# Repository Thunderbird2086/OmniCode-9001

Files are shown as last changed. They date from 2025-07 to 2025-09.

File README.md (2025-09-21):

# OmniCode:9001
A modular keyboard made up of three detachable untis.
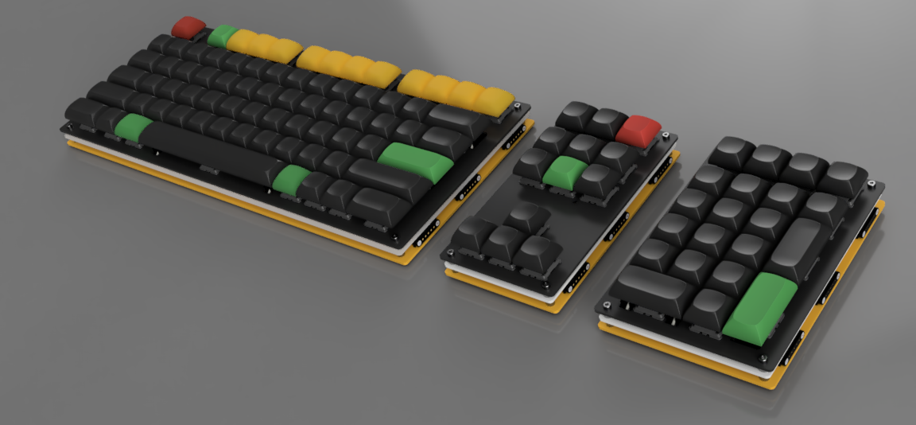
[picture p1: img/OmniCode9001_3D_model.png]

*POGO pins are rendered with 5 pins only*

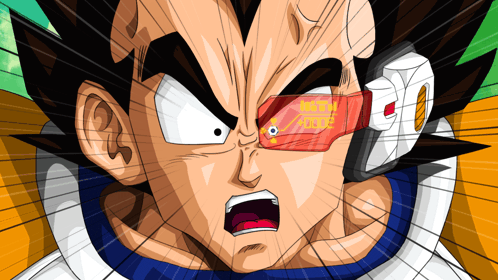
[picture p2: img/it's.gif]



## Overview
OmniCode:9001 is the modular keyboards born in Hong Kong, engineered for control beyond limits. This highly customizable, open-source keyboard is designed for ergonomic comfort, maximum flexibility, and creative power. With magnetic connectors, hot-swappable blocks like GlyphMatrix, PhaseShift, and DeltaForm, OmniCode:9001 adapts to every workflow.  It is built with the RP2040 microcontroller for next-generation performance.  Ideal for makers and keyboard enthusiasts who demand the best.

## Sub Modules
- **Alpha Block:** GlyphMatrix taps into the visual power of language—glyphs as symbols, matrix as command stream. It’s the scriptwriter for your digital world.

- **Nav Block:** PhaseShift suggests rapid movement, shifting through modes or layers like teleportation. It’s your tactical array for traversing digital dimensions.

- **Num Block:** DeltaForm Already perfect. This name suggests modular transformation. Zoom, macros, data entry and it's all reborn in a shapeshifting format.

## Builds
* [BOM](bom/)
* [Build guides](doc/build.md)
* [Cases](cases/)

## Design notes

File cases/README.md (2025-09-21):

# OmniCode:9001 Case Files

This directory contains STEP files for all OmniCode:9001 cases. These files can be used for both 3D printing and CNC manufacturing.

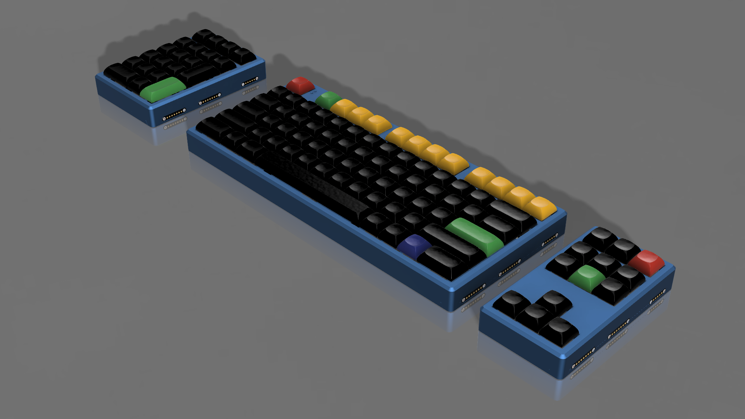
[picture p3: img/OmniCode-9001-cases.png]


## Case Components

### GlyphMatrix
- `GlyphMatrix_Top.step` - Top case
- `GlyphMatrix_PCB.step` - PCB model for reference

### PhaseShift
- `PhaseShift_Top.step` - Top case
- `PhaseShift_Plate.step` - Switch plate

### DeltaForm
- `DeltaForm_Top.step` - Top case
- `DeltaForm_Plate.step` - Switch plate

## Manufacturing Notes

### Screw Specifications
- All cases use M3 helicoils (thread inserts)
- Helicoil size: M3x0.5mm 1D(3mm)
- Required for both 3D printed and CNC manufactured cases

### 3D Printing Recommendations
- Material: Nylon or ABS recommended
- Layer Height: 0.2mm or less for better surface finish
- Infill: 60% minimum, recommanded over 80% 
- Wall Count: 4 minimum
- Support: Required for top cases
- Orientation: Print top cases upside down for best finish
- Note: Tap for helicoil installation after printing

### CNC Manufacturing
- Material: Aluminum 6061 recommended
- Finish: Can be anodized after manufacturing
- Thread spec: Tap for M3 helicoil installation

### Hardware Requirements
- M3 helicoils for all mounting points
- M3 screws for assembly: 8mm in length
- Follow the main build guide for assembly instructions

## Additional Notes
- All models are in 1:1 scale (millimeters)

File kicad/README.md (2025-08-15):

# OmniCode:9001 PCB Designs

This directory contains all KiCad PCB design files for the OmniCode:9001 keyboard modules.

## Modules

### GlyphMatrix (Alpha Block)
The main typing module with a full ANSI layout.

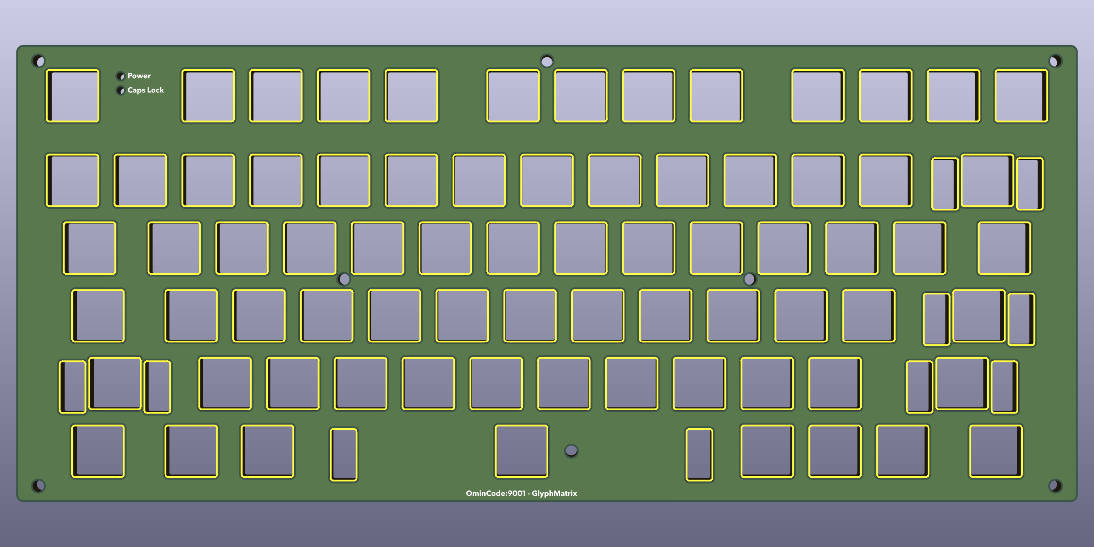
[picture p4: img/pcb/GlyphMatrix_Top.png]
GlyphMatrix PCB Top View

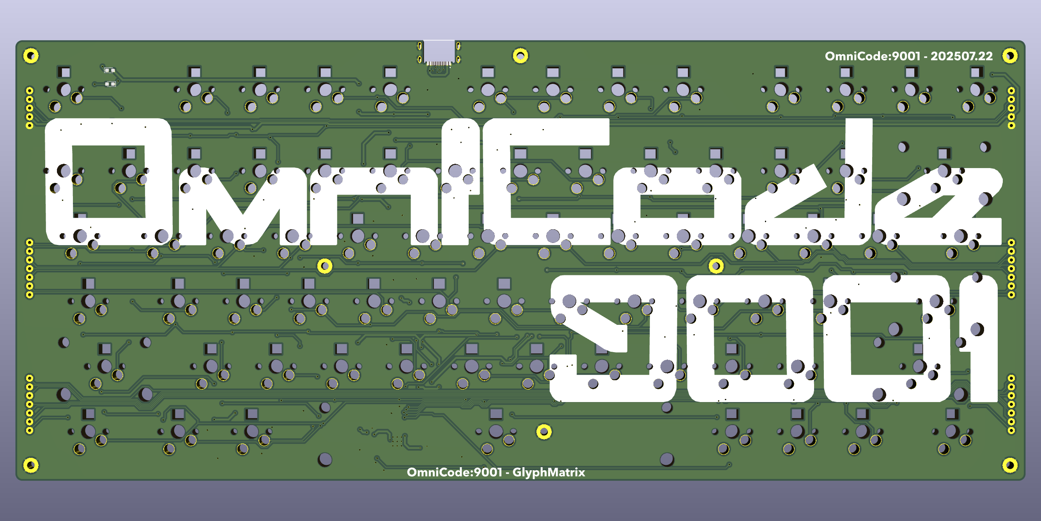
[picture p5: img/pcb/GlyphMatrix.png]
GlyphMatrix PCB

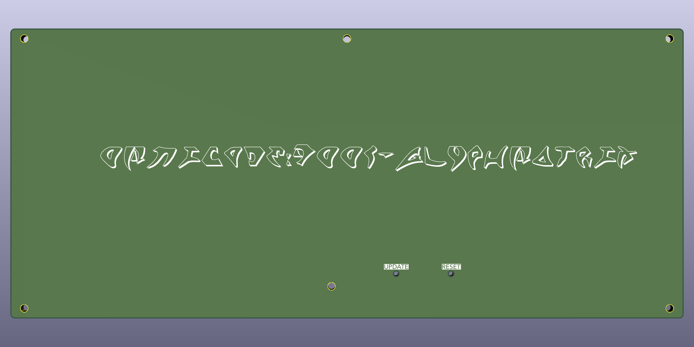
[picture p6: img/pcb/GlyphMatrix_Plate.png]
GlyphMatrix PCB Bottom View


**Features:**
- RP2040 microcontroller
- USB Type-C connector
- Hot-swappable MX switch sockets
- RGB LED support
- POGO pin connections for modular attachment

### PhaseShift (Nav Block)
Navigation and macro control module.

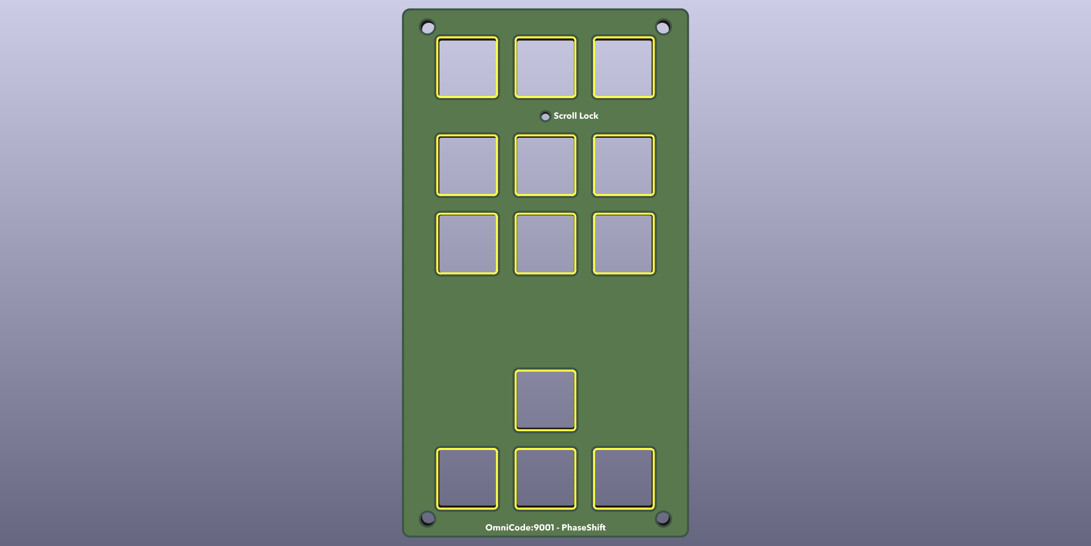
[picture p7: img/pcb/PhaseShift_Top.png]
PhaseShift PCB Top View

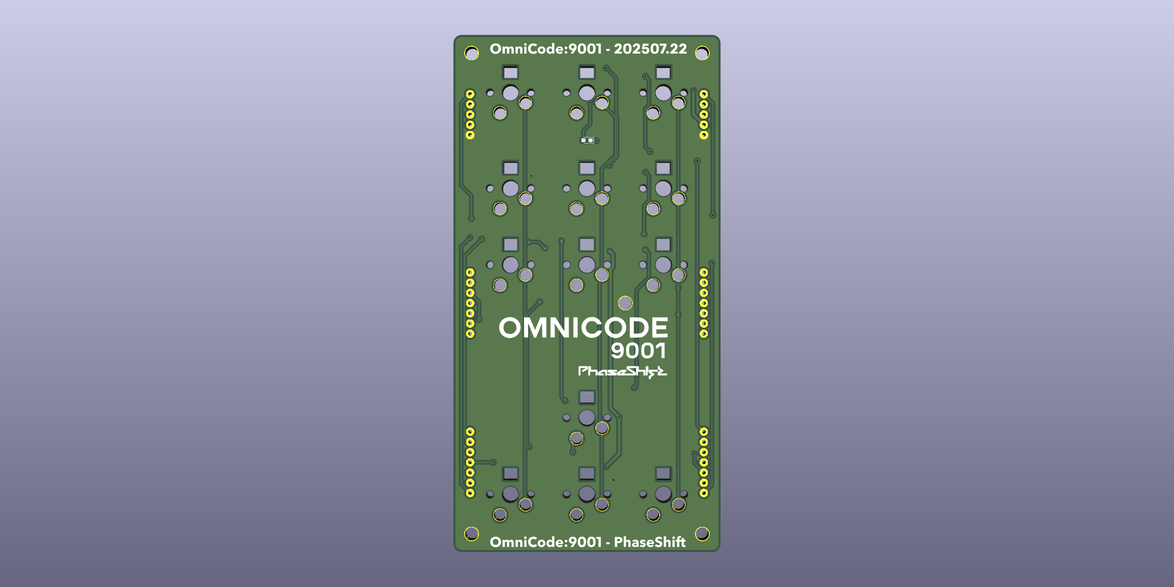
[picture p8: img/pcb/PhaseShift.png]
PhaseShift PCB

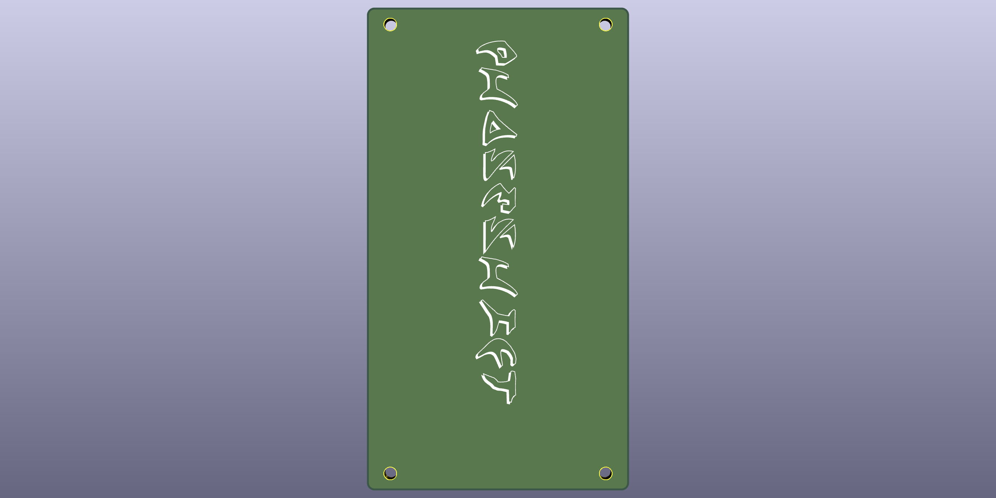
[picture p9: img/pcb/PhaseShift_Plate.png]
PhaseShift PCB Bottom View


**Features:**
- Hot-swappable MX switch sockets
- RGB LED support
- POGO pin connections for modular attachment

### DeltaForm (Num Block)
Numeric keypad and additional macro keys.

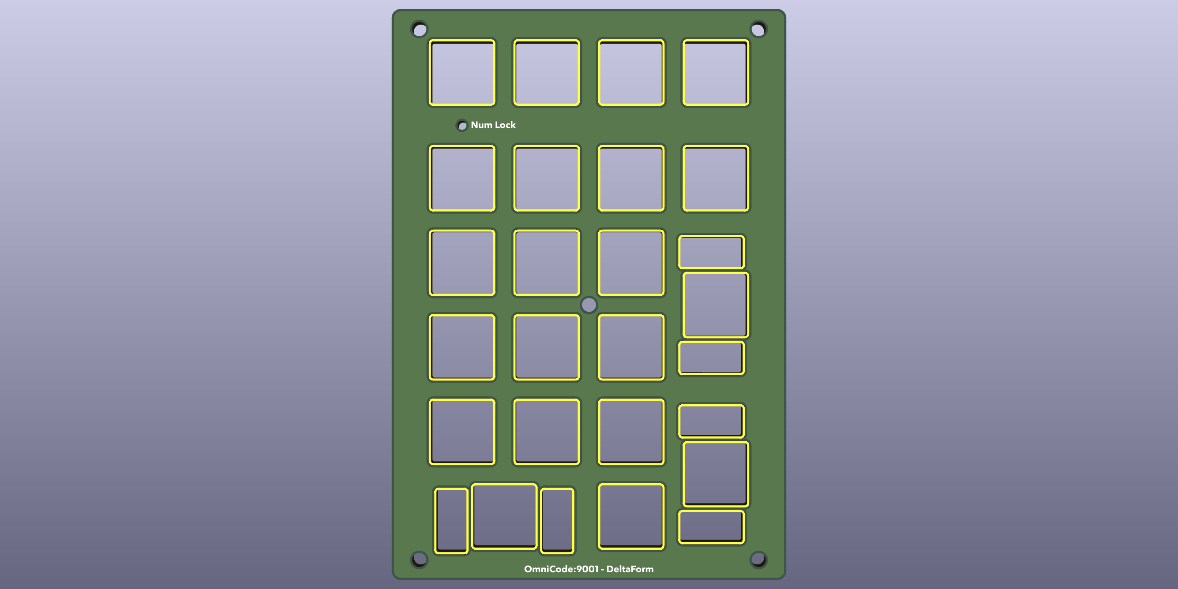
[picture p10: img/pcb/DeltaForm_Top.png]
DeltaForm PCB Top View

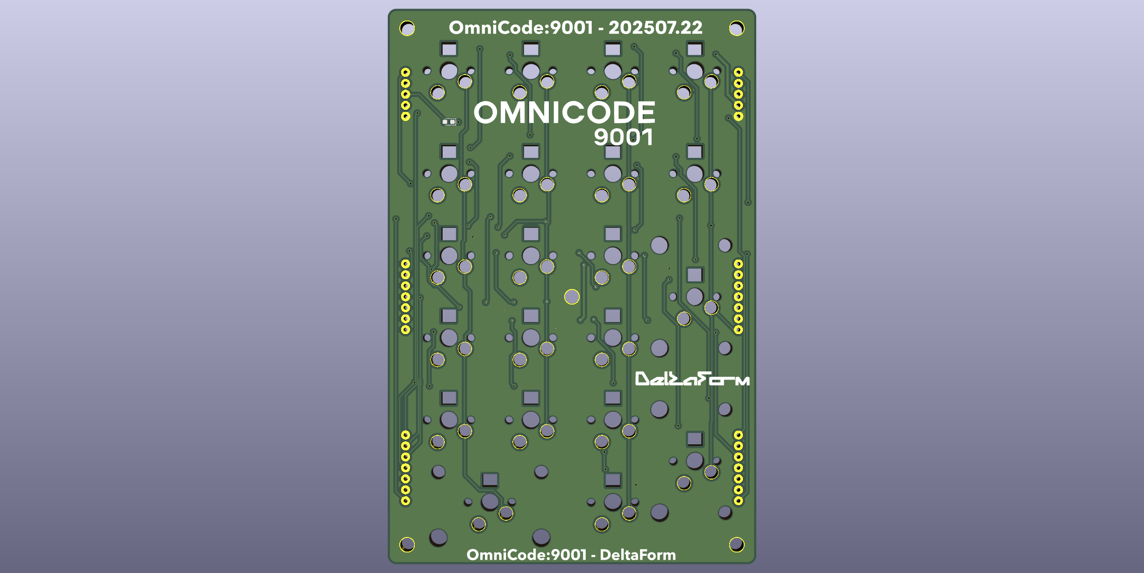
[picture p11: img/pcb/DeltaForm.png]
DeltaForm PCB

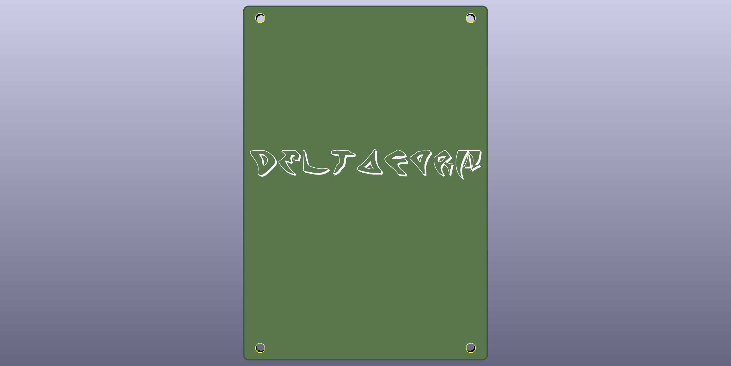
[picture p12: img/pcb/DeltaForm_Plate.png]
DeltaForm PCB Bottom View


**Features:**
- Hot-swappable MX switch sockets
- RGB LED support
- POGO pin connections for modular attachment

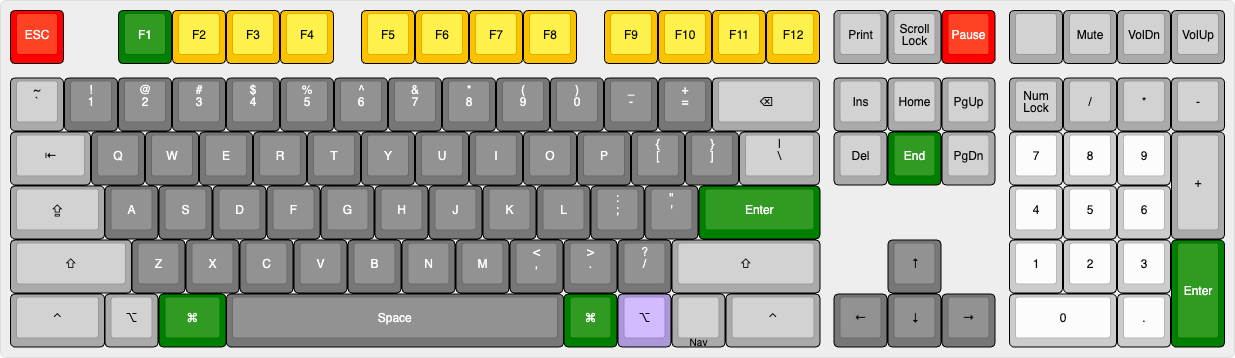
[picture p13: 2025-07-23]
img/layout/omnicode-9001-qwerty.png

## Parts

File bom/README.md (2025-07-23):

# GlyphMatrix (Alpha Block) BOM

GlyphMatrix taps into the visual power of language—glyphs as symbols, matrix as command stream. It’s the scriptwriter for your digital world.

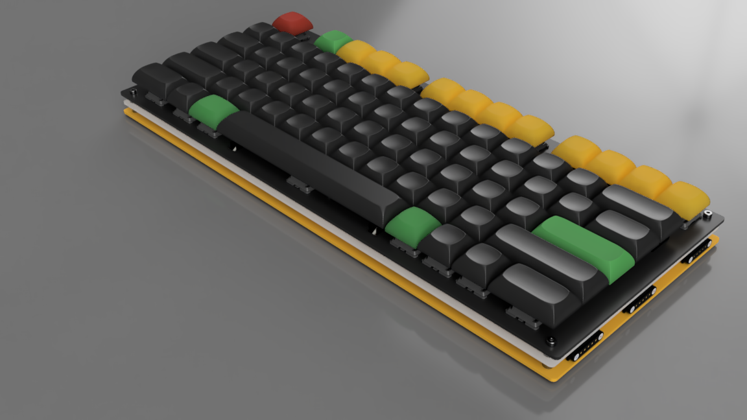
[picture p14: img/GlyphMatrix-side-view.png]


*POGO pins are rendered with 5 pins only*

## Bill of Materials

### RP2040

| Parts | Package | Designator(s) | Quantity |
|---|---|---|---|
| RP2040 | QFN-56 | MCU1 | 1 |
| W25Q128JVS | SOIC-8 | U1 | 1 |
| XC6206PxxxMR | SOT-23 | U3 | 1 |
| 1k | 0402 | R1, R6, R8 | 3 |
| 27R | 0603 | R4, R5 | 2 |
| 100nF | 0402 | C1, C10, C11, C12, C13, C14, C15, C5, C6, C9 | 10 |
| 1uF | 0402 | C16, C17, C4, C8 | 4 |
| 10uF | 0402 | C7 | 1 |
| 22pF | 0402 | C2, C3 | 2 |
| 12MHz | 3225 | Y1 | 1 |
| Push Switch | SKQG | SW1, SW2 | 2 |

### USB

| Parts | Package | Designator(s) | Quantity |
|---|---|---|---|
| USB-C Receptacle | USB4520-03-0-A Rev. A | USB1 | 1 |
| USBLC6-2SC6 | SOT-23-6 | U2 | 1 |
| 5.1k | 0402 | R2, R3 | 2 |
| 500mA | 1206 | F1 | 1 |

### Key Switches

| Parts | Package | Designator(s) | Quantity |
|---|---|---|---|
| 1N4148W | SOD-123 | D1-D74 | 74 |
| Hotswap Socket | MX | S1-S74 | 74 |
| WHITE | 0603 | LED1 | 1 |
| GREEN | 0603 | LED2 | 1 |

### Optional

| Parts | Package | Designator(s) | Quantity |
|---|---|---|---|
| SK6812MINI-E | SK6812MINI-E| L1-L74 | 74 |
| POGO 5 pin-male | Curved | POGO1 | 1 |
| POGO 5 pin-female | Curved | POGO2 | 1 |
| POGO 7 pin-male | Curved | POGO3, POGO5 | 2 |
| POGO 7 pin-female | Curved | POGO4, POGO6 | 2 |

# Other blocks

* [PhaseShift](bom-phaseshift.md)
* [DeltaForm](bom-deltaform.md)

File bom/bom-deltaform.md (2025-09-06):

# DeltaForm (Num Block) BOM

DeltaForm Already perfect. This name suggests modular transformation. Zoom, macros, data entry and it's all reborn in a shapeshifting format.

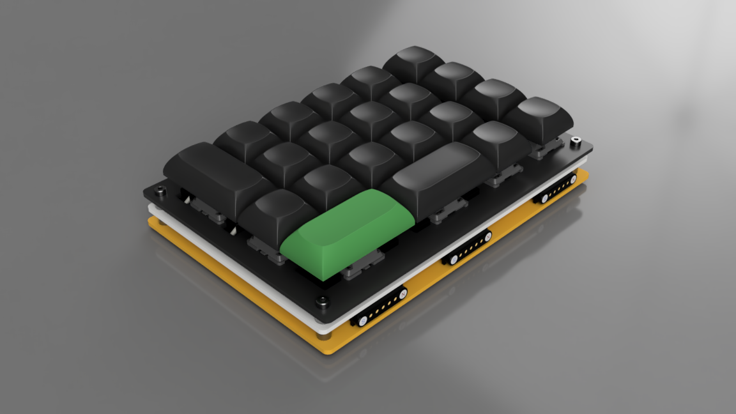
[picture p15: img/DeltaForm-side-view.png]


*POGO pins are rendered with 5 pins only*

## Bill of Materials

| Parts | Packeage | Designator(s) | Quantity |
|---|---|---|---|
| Hotswap Socket | MX | S1-S21 | 21 |
| 1N4148W | SOD-123 | D1-D21 | 21 |
| 330 | 0603 | R1 | 1 |
| GREEN | 0603 | LED1 | 1 |
| POGO 5 pin-male | Curved | POGO1 | 1 |
| POGO 5 pin-female | Curved | POGO2 | 1 |
| POGO 7 pin-male | Curved | POGO3, POGO5 | 2 |
| POGO 7 pin-female | Curved | POGO4, POGO6 | 2 |

### Optional

| Parts | Packeage | Designator(s) | Quantity |
|---|---|---|---|
| SK6812MINI-E | SK6812MINI-E| L1-L21 | 21 |

# Other blocks

* [GlyphMatrix](README.md)
* [PhaseShift](bom-phaseshift.md)

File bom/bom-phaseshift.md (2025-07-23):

# PhaseShift (Nav Block) BOM

PhaseShift suggests rapid movement, shifting through modes or layers like teleportation. It’s your tactical array for traversing digital dimensions.

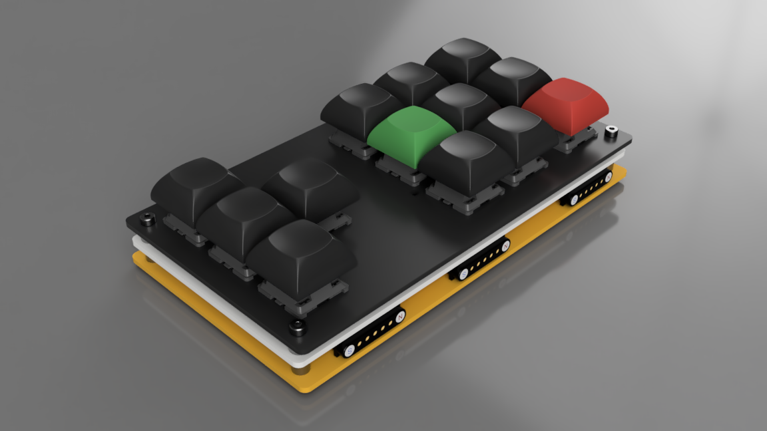
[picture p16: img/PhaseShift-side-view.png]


*POGO pins are rendered with 5 pins only*

## Bill of Materials

| Parts | Packeage | Designator(s) | Quantity |
|---|---|---|---|
| Hotswap Socket | MX | S1-S13 | 13 |
| 1N4148W | SOD-123 | D1-D13 | 13 |
| 330 | 0603 | R1 | 1 |
| GREEN | 0603 | LED1 | 1 |
| POGO 5 pin-male | Curved | POGO1 | 1 |
| POGO 5 pin-female | Curved | POGO2 | 1 |
| POGO 7 pin-male | Curved | POGO3, POGO5 | 2 |
| POGO 7 pin-female | Curved | POGO4, POGO6 | 2 |

### Optional

| Parts | Packeage | Designator(s) | Quantity |
|---|---|---|---|
| SK6812MINI-E | SK6812MINI-E| L1-L13 | 13 |

# Other blocks

* [GlyphMatrix](README.md)
* [DeltaForm](bom-deltaform.md)

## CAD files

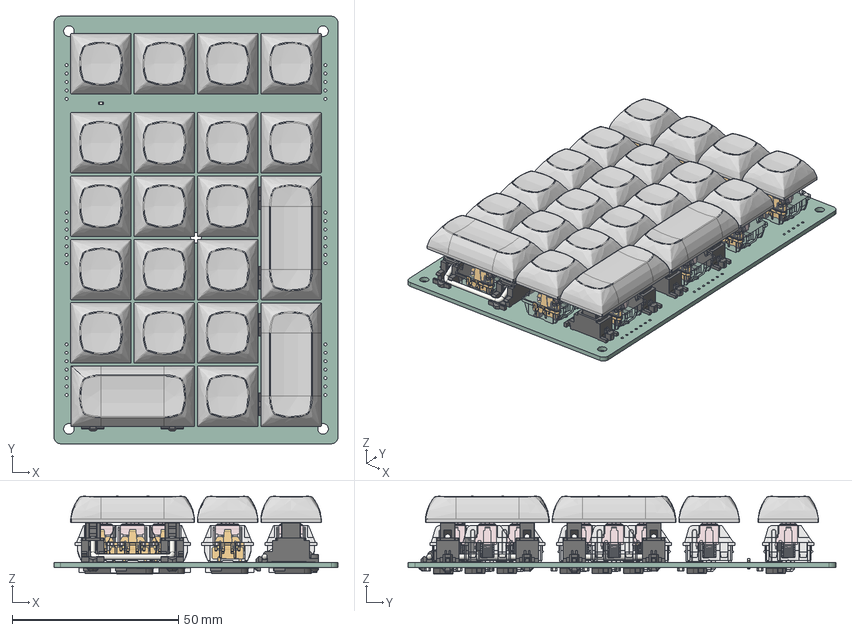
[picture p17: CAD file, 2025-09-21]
3D Models/DeltaForm.step
85.4 x 128.6 x 23.4 mm
Stabilizer_Cherry_MX_2.00u x 3
LED_0603_1608Metric
D_1206_3216Metric x 21
mx_body x 21
contact_a1 x 21
contact_a2 x 21
contact_b x 21
contact_a003 x 21
contact_a004 x 21
contact_b001 x 21
DSA_2u x 3
bottom x 21
pin1 x 21
pin2 x 21
shrunken_spring x 21
stem_body x 21
stem_cushion_l x 21
stem_cushion_r x 21
top x 21
MX Mount v1 x 18
SK6812MINI-E x 21
R_0603_1608Metric
DeltaForm_PCB

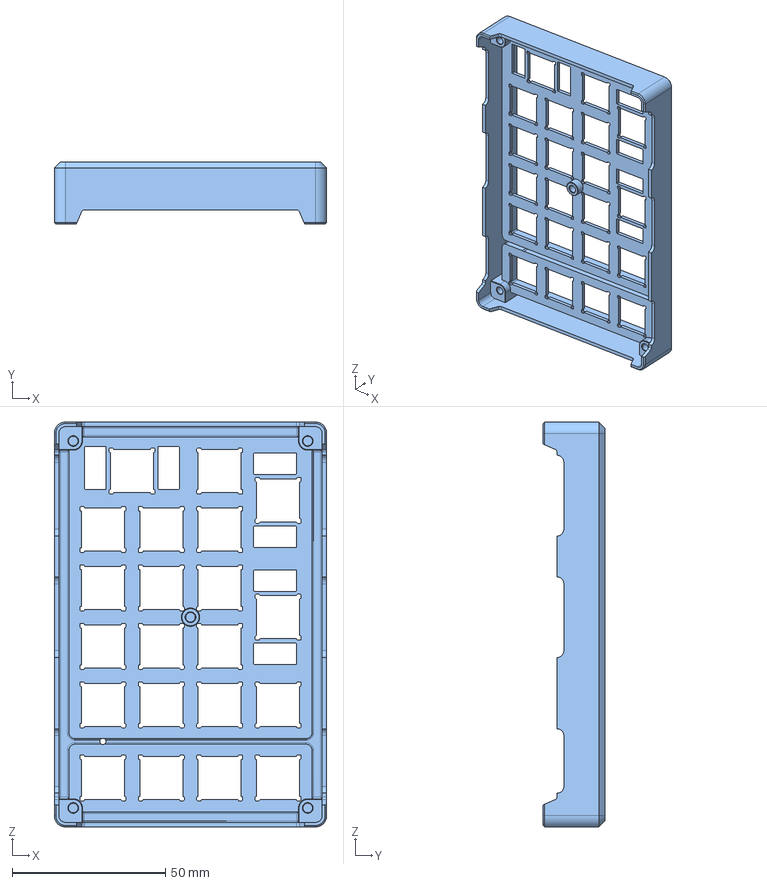
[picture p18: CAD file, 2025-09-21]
cases/DeltaForm-Top.step
88.8 x 20.2 x 132.0 mm

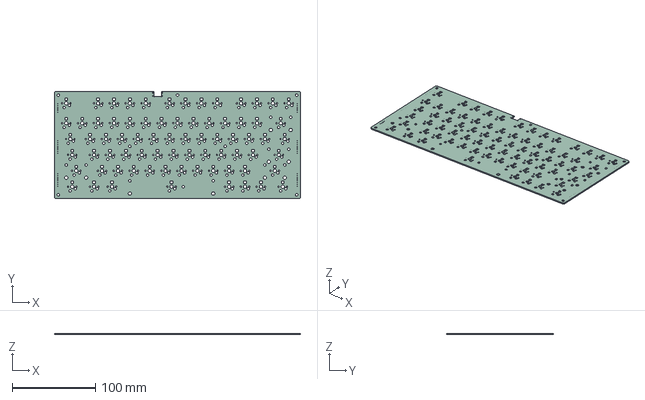
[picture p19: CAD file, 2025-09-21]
3D Models/GlyphMatrix_PCB.step
294.9 x 128.6 x 1.51 mm

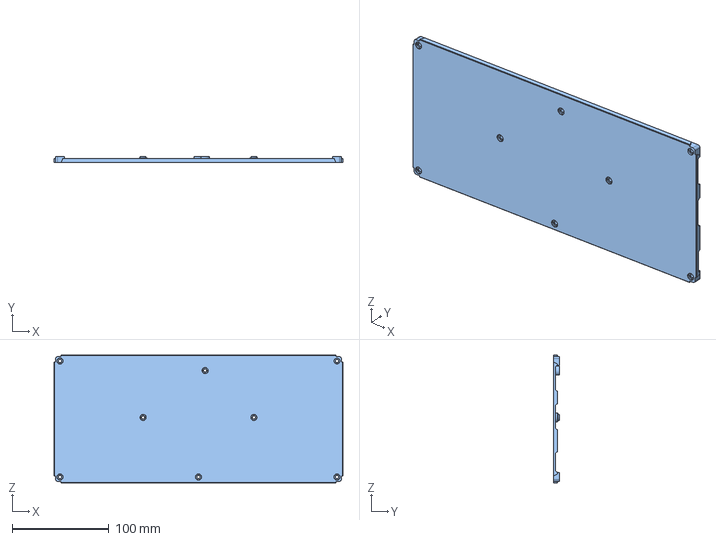
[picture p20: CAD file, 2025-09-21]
cases/GlyphMatrix-Bottom.step
298.3 x 6.70 x 132.0 mm

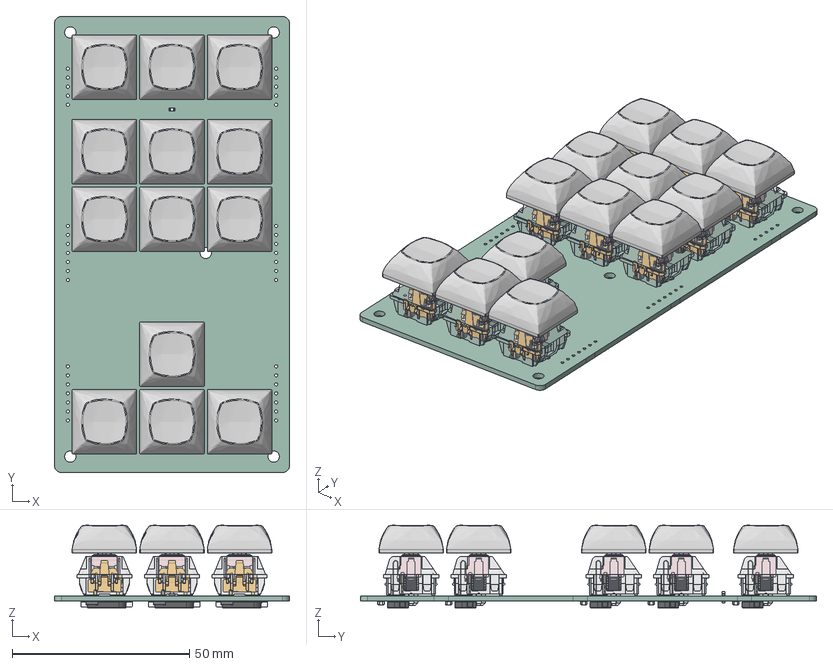
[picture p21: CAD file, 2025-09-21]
3D Models/PhaseShift.step
66.4 x 128.6 x 23.3 mm
LED_0603_1608Metric
mx_body x 13
contact_a1 x 13
contact_a2 x 13
contact_b x 13
contact_a003 x 13
contact_a004 x 13
contact_b001 x 13
MX Mount v1 x 13
bottom x 13
pin1 x 13
pin2 x 13
shrunken_spring x 13
stem_body x 13
stem_cushion_l x 13
stem_cushion_r x 13
top x 13
D_1206_3216Metric x 13
SK6812MINI-E x 13
R_0603_1608Metric
PhaseShift_PCB

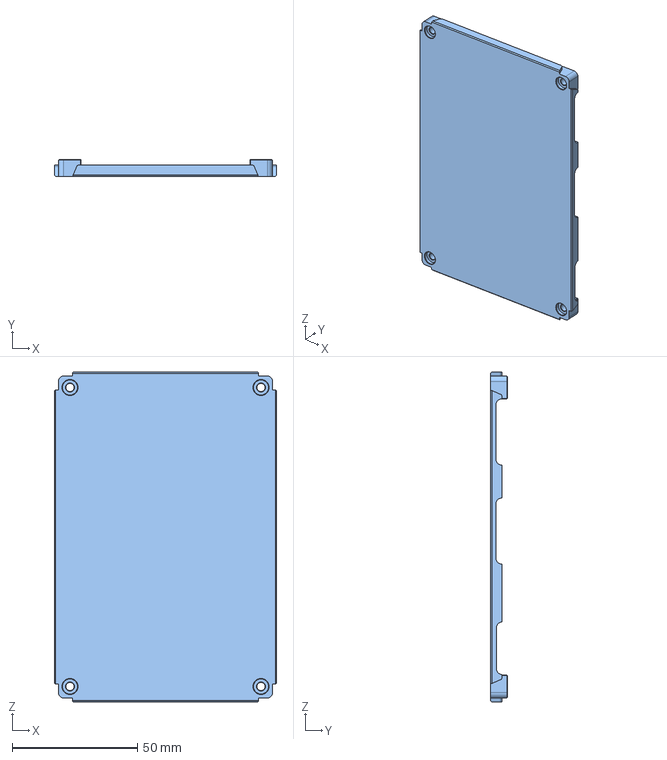
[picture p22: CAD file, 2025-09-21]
cases/DeltaForm-Bottom.step
88.8 x 6.70 x 132.0 mm

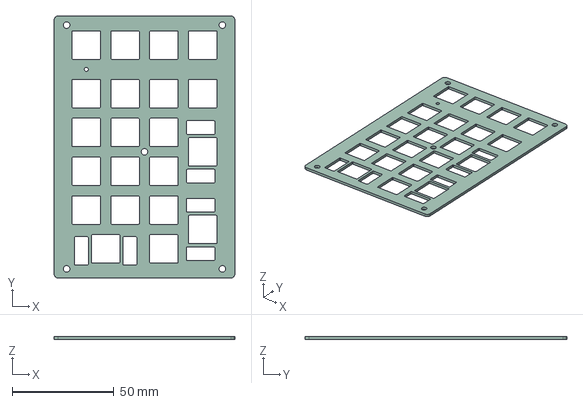
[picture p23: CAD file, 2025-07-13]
3D Models/DeltaForm_Top.step
88.8 x 128.6 x 1.51 mm

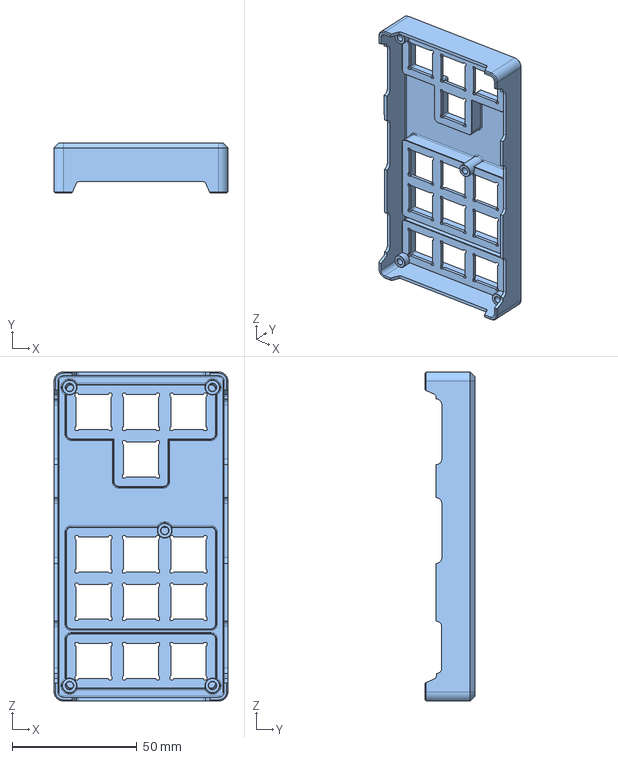
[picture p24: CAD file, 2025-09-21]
cases/PhaseShift-Top.step
69.8 x 20.2 x 132.0 mm

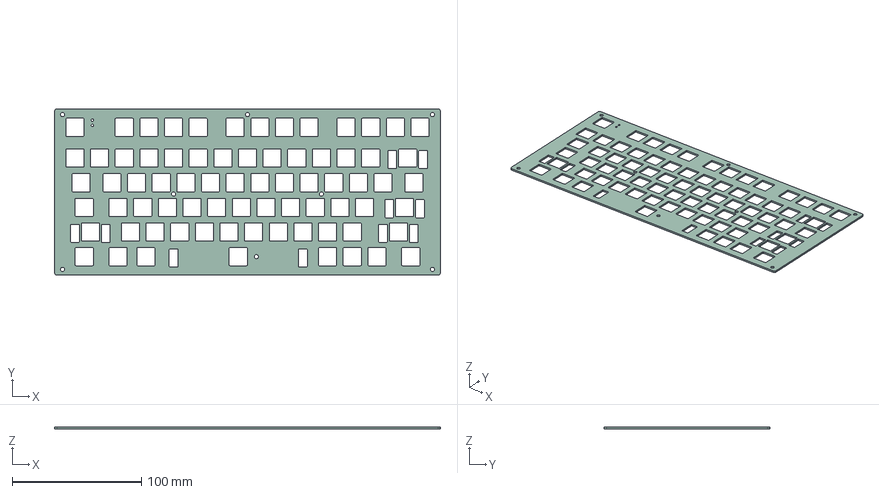
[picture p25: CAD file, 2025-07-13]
3D Models/GlyphMatrix_Top.step
298.3 x 128.6 x 1.51 mm

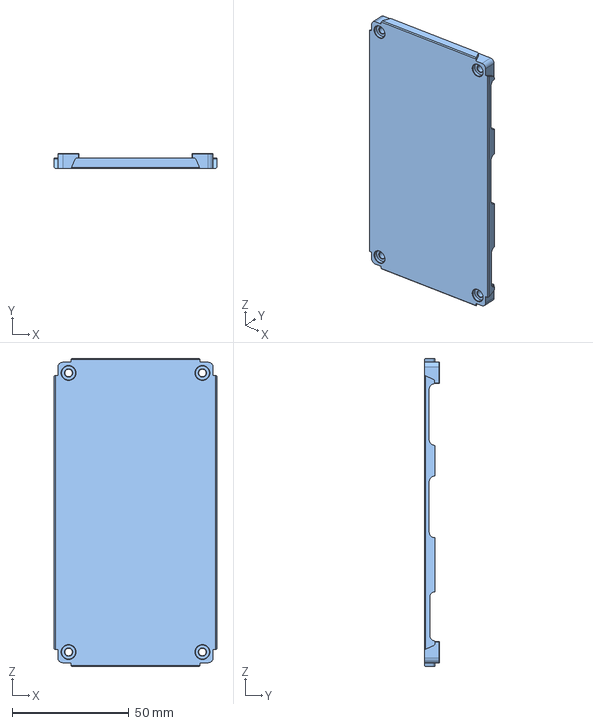
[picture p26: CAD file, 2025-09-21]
cases/PhaseShift-Bottom.step
69.8 x 6.60 x 132.0 mm

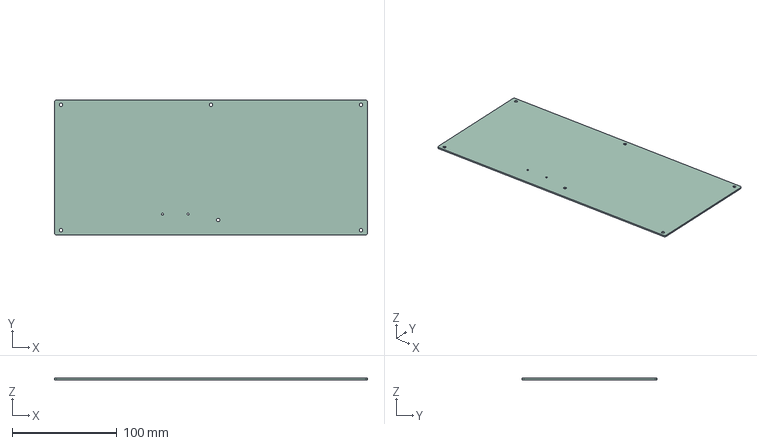
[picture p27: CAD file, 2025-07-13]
3D Models/GlyphMatrix_Plate.step
298.3 x 128.6 x 1.51 mm

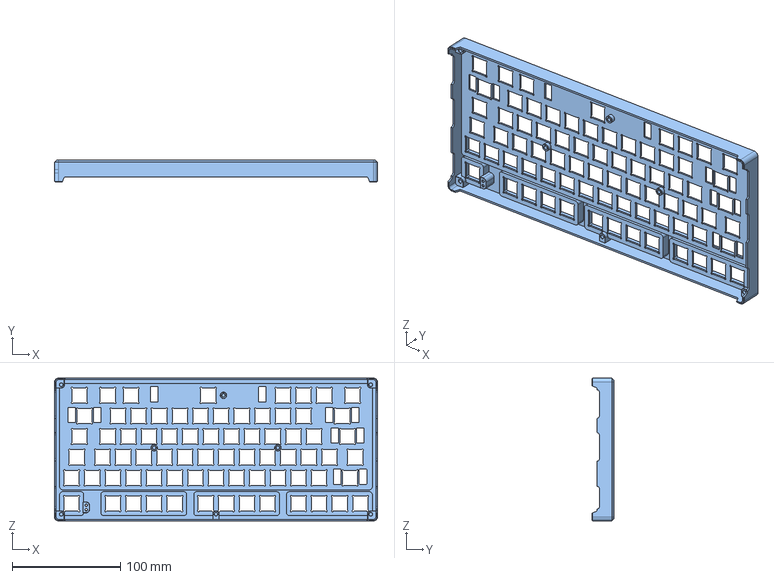
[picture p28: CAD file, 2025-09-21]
cases/GlyphMatrix-Top.step
298.3 x 20.2 x 132.0 mm

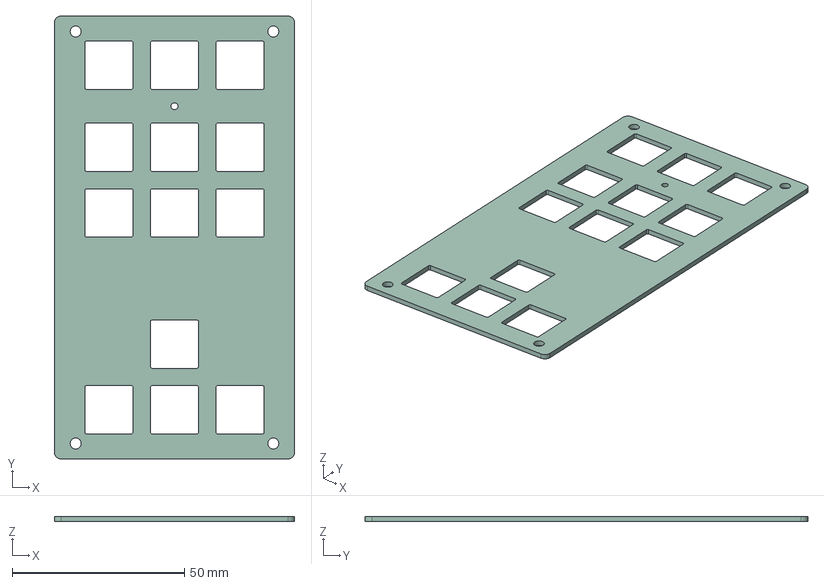
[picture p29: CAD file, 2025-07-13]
3D Models/PhaseShift_Top.step
69.8 x 128.6 x 1.51 mm

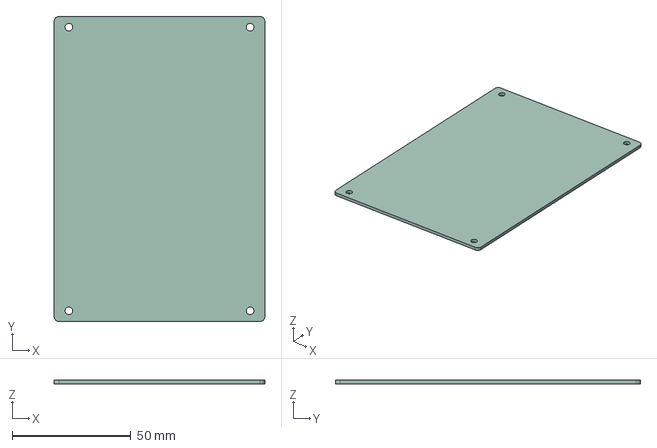
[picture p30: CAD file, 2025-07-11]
3D Models/DeltaForm_Plate.step
88.8 x 128.6 x 1.51 mm

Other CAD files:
3D Models/PhaseShift_Plate.step

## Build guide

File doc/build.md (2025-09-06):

# Build Guide - GlyphMatrix

> **Note:** Even though using a pre-soldered PCB, it still requires manual soldering of hot swap sockets and LEDs.

## Parts
### Required
| Part | Quantity | Notes |
|---|---|---|
| MX key switches | 74 | |
| Hot swap sockets | 74 | |
| Keycaps | 74 | |
| M3x8 screws | 8 | |
| Spacers (3mm) or M3 Standoffs (3mm) | 8 | Choose one |
| M3 gaskets (0.5mm) | 8 | |
| M3x4 screws | 6 | |
| M3 Standoffs (5mm) | 8 | |
| D2 Light guide (3.2mm) | 2 | |

### Optonal
| Part | Quantity | Notes |
|---|---|---|
| RGB LEDs | 74 | SK6812 mini-e |
| POGO Pin 5P (curved)| 1 Set | male and female |
| POGO Pin 7P (curved)| 2 Set | male and female |

## Steps

1. **Soldering Hot Swap Sockets and LEDs**
   - **Hot Swap Sockets:** Solder all 74 hot swap sockets onto the PCB, making sure each socket is aligned with the footprint.

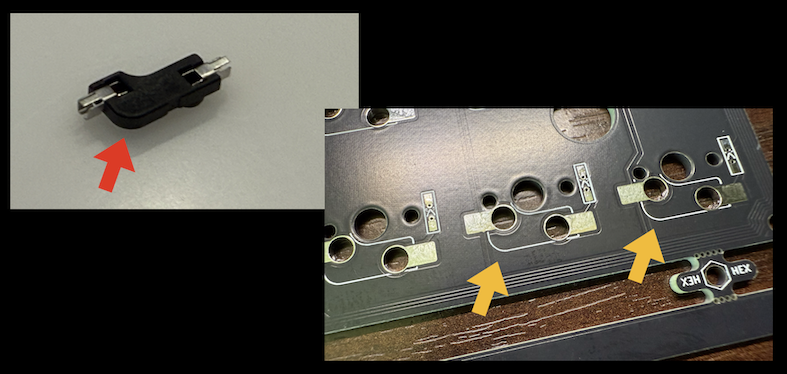
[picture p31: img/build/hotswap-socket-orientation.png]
     
   - **Per-key LED (optional):** Solder per-key LEDs onto the PCB, making sure their orientation matches the footprint.

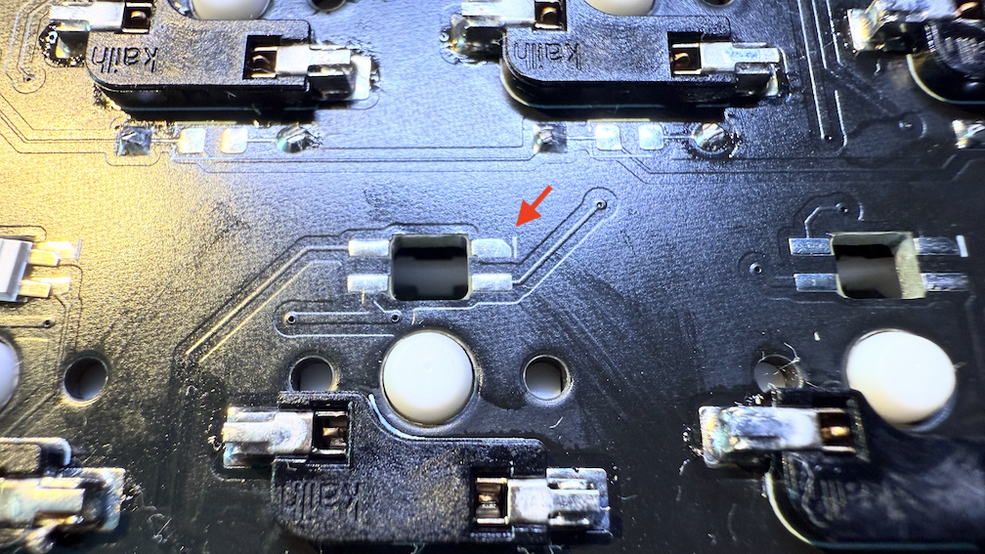
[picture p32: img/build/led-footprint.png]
     

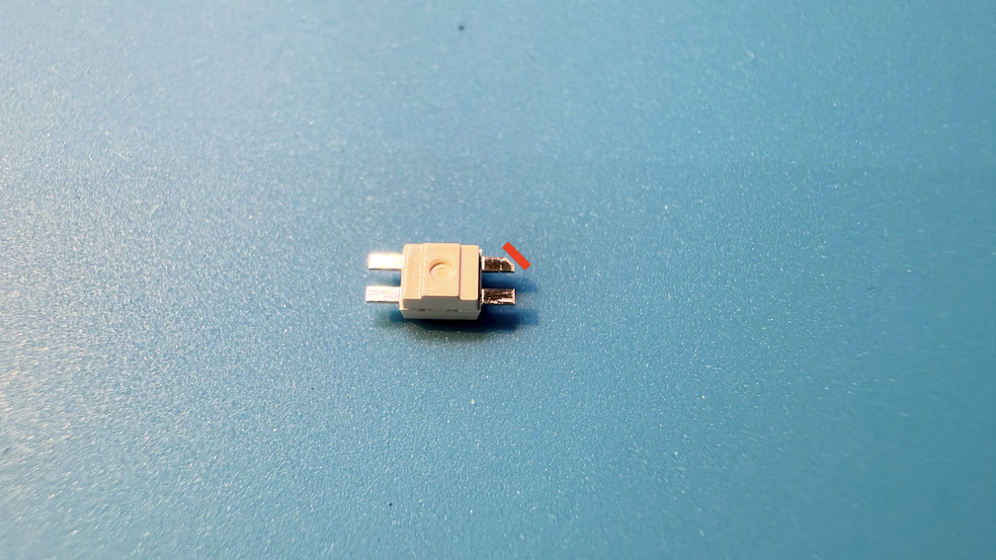
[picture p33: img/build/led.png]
     
   - **POGO Pin (optional):**
     - Insert the POGO pins from the bottom side of the PCB, ensuring the correct orientation (male part on the left side, female part on the right for instance).

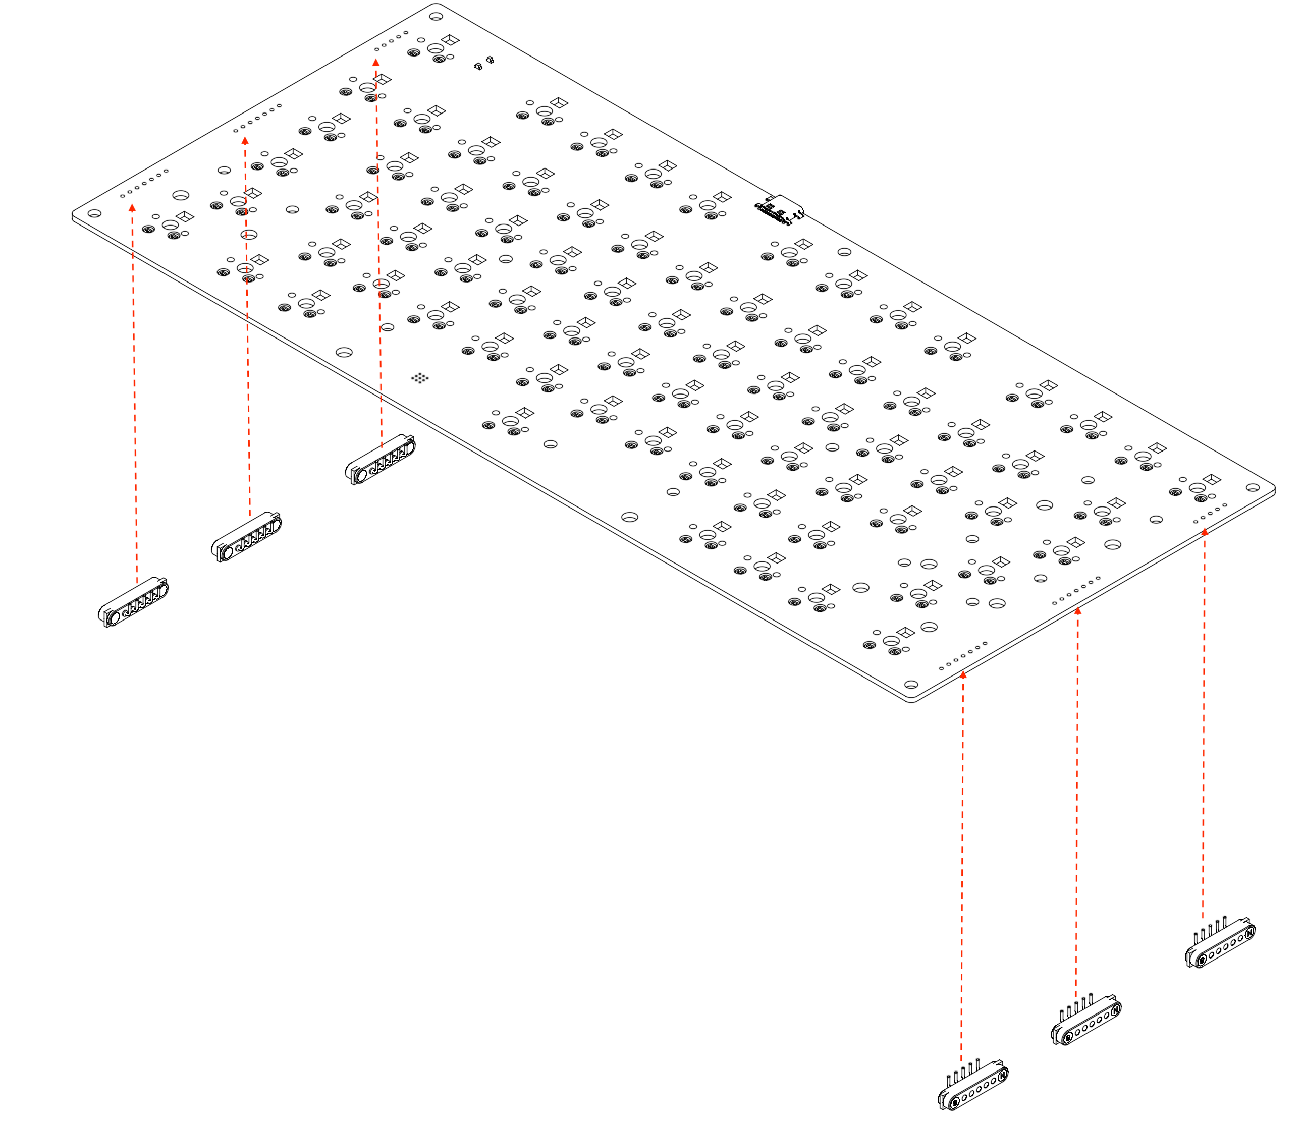
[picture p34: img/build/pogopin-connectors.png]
       
     - Hold the pins firmly in place and solder from the top side.
     - Double-check alignment before soldering all pins, as POGO pins must be straight for reliable contact.
     - After soldering, inspect for excess solder and clean up any bridges or cold joints.

1. **Install Stabilizers**
   > **Note:** Stabilizers may require assembly before installation.
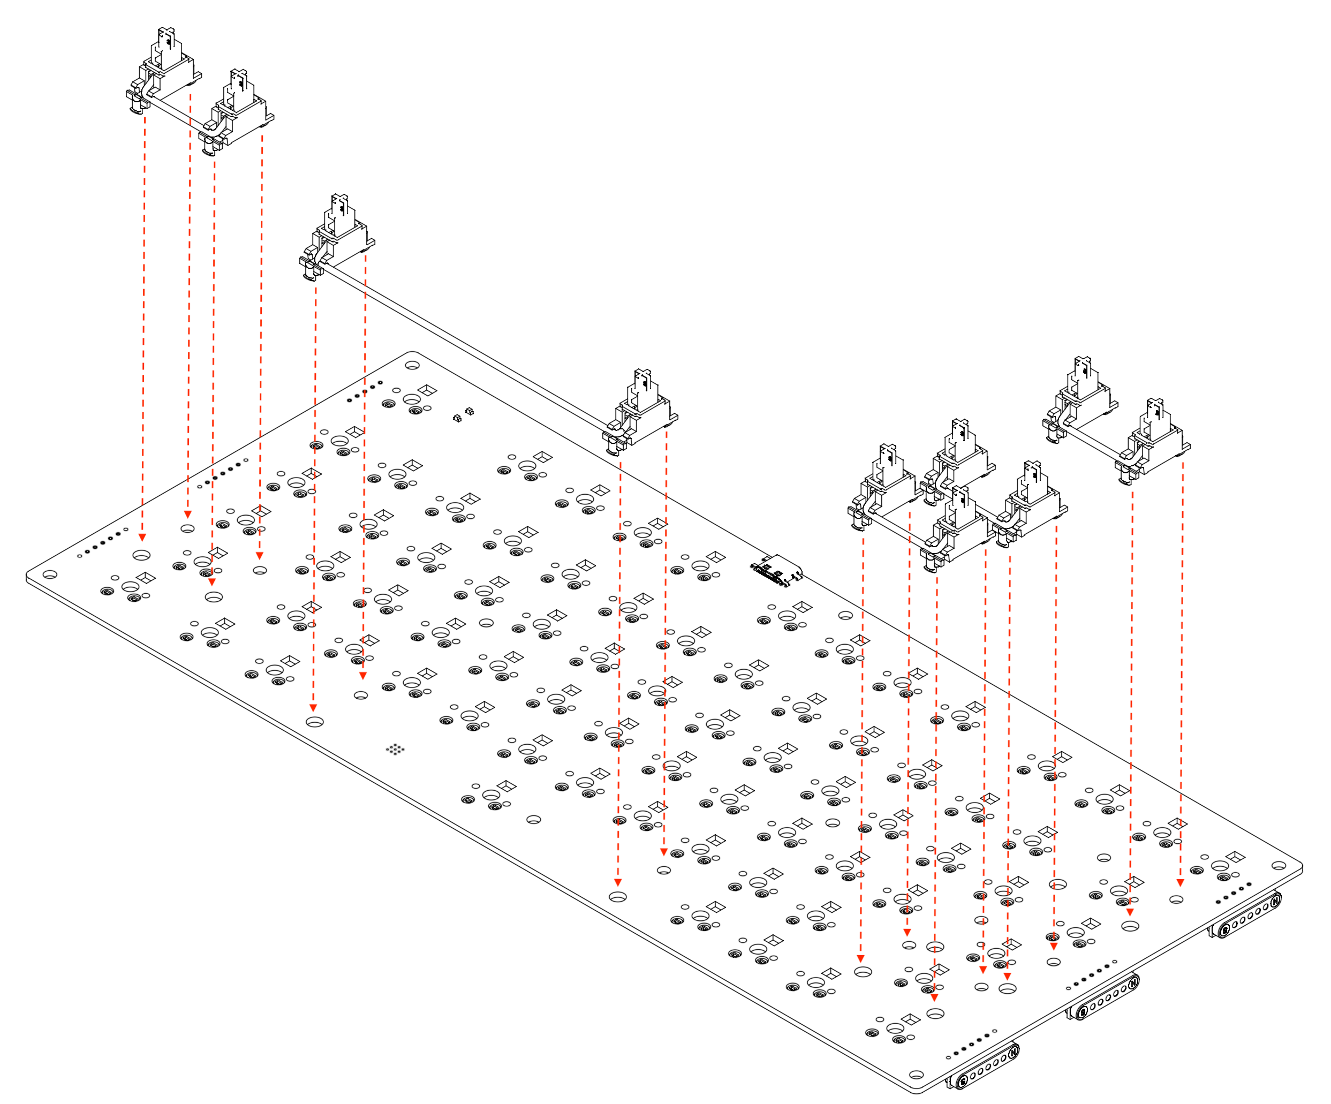
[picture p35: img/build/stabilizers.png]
     

1. **Prepare Top Plate and Mounting Hardware**
   > **Note:** There are two options for mounting hardware. Choose one of the following methods:
   ### Option A: Using 3mm Spacers
   1. Place the top plate onto the PCB
   1. Position the 8 spacers (3mm) at the designated mounting points
   1. Add 8 standoffs (5mm) at the bottom side of the PCB
   1. Insert 8 M3x8mm screws through the top plate, spacers, gaskets and PCB, then loosely fasten them with 5mm standoffs

   ### Option B: Using M3x3mm Standoffs
   1. Insert 8 M3x8mm screws through the top plate and M3x3mm standoffs
   1. Place the top plate assembly onto the PCB
   1. Add 8 standoffs (5mm) at the bottom side of the PCB

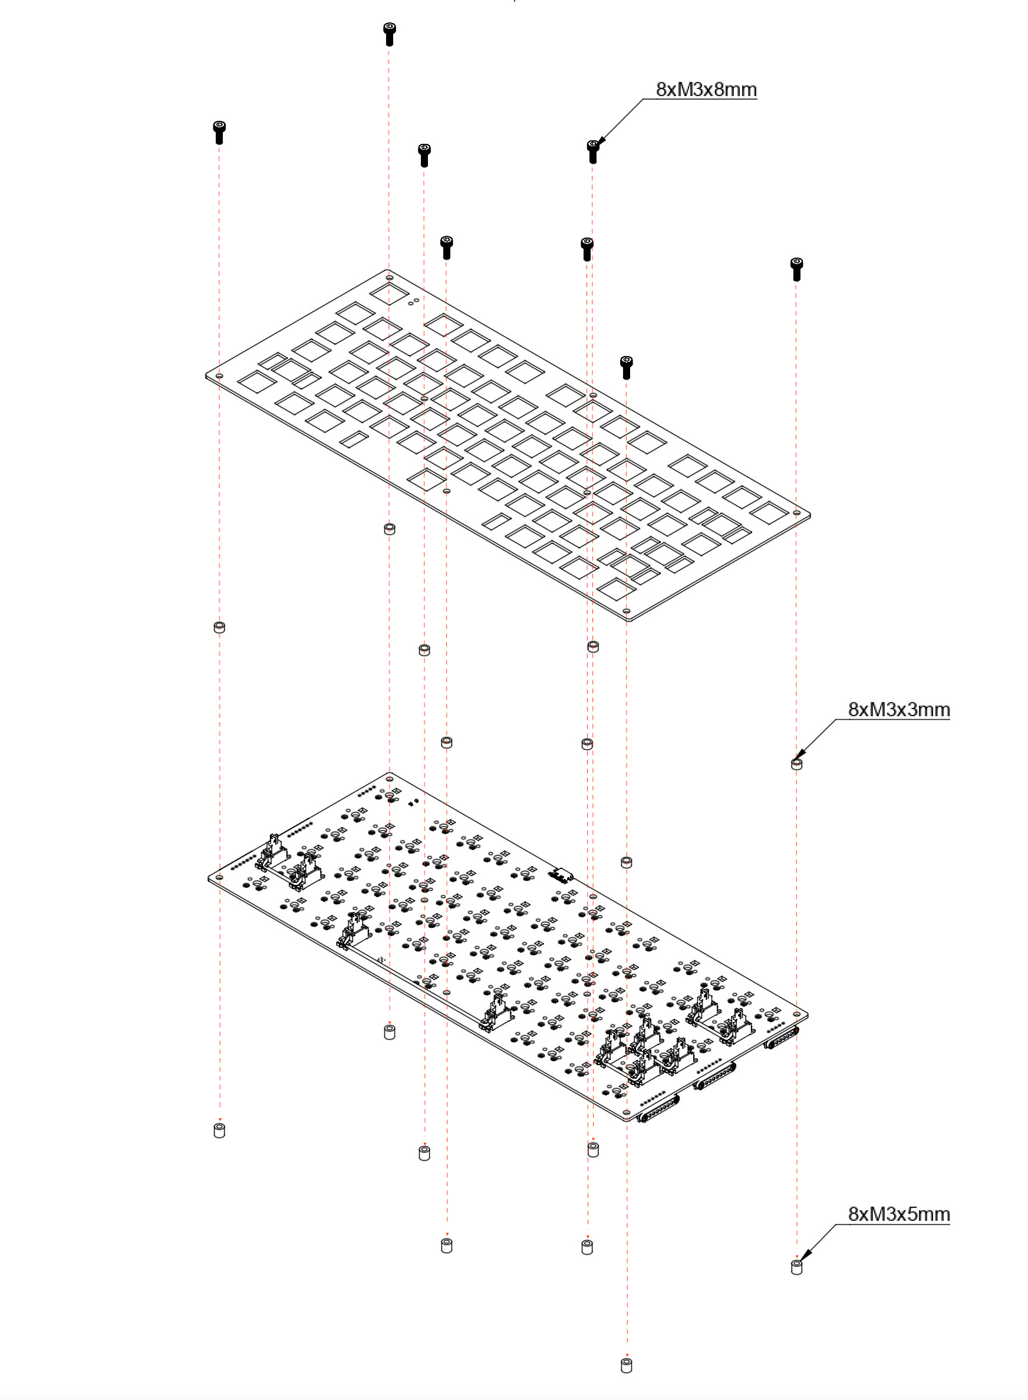
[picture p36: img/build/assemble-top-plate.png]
   

   > **Important:** Do not fully tighten the screws yet. This is a pre-assembly step. Final tightening should be done after all key switches are installed to ensure proper fit and alignment.

1. **Install Light Guide**
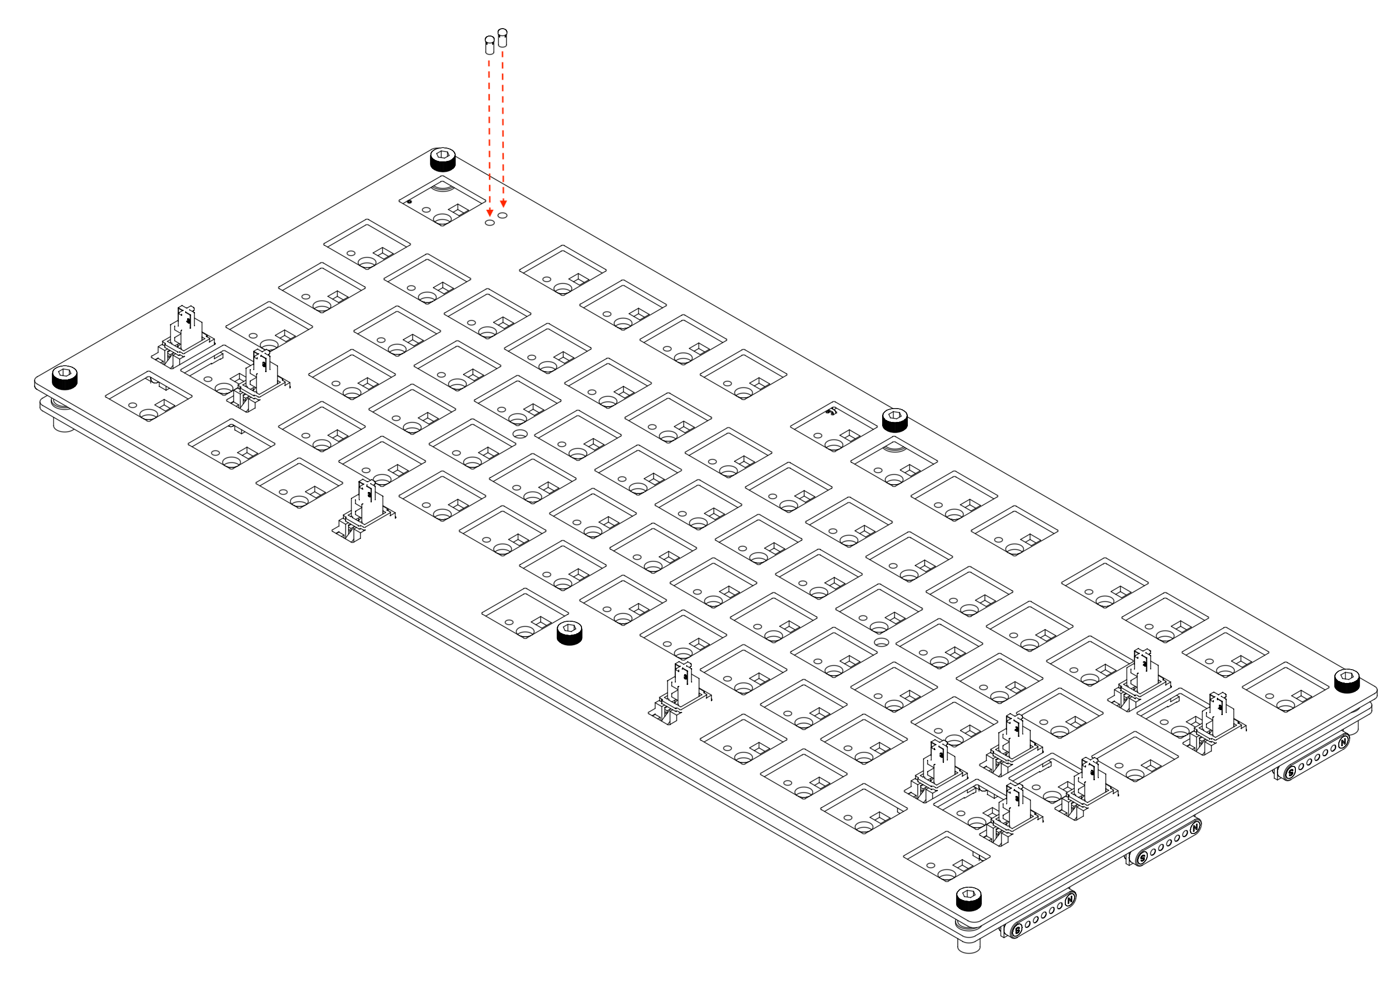
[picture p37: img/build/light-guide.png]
   

1. **Install Key Switches**
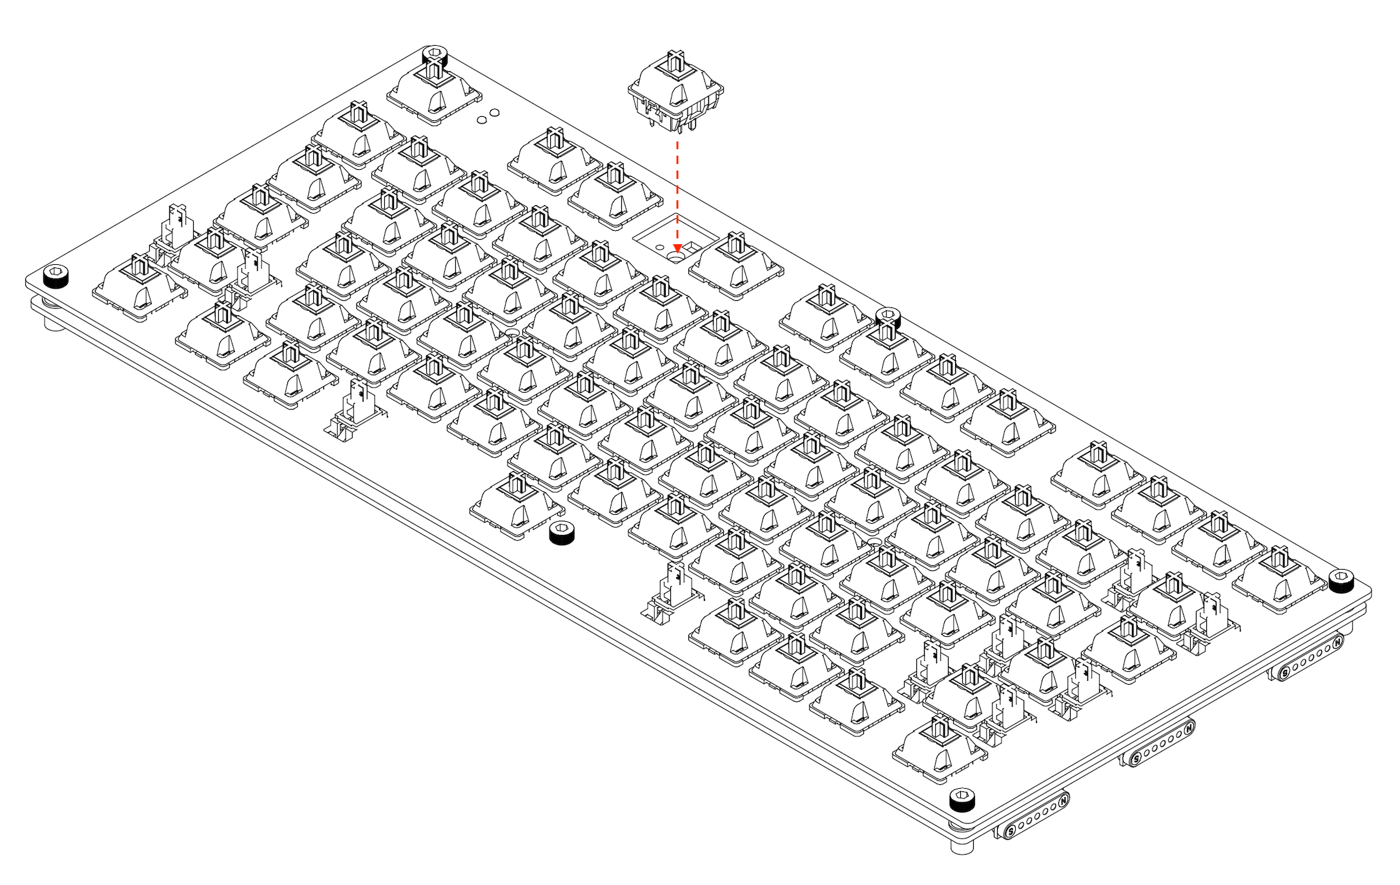
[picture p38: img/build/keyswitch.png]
   
   - Carefully align each MX key switch with the hot swap socket and plate cutout.
   - Gently press the switch straight down into the socket. **Be careful:** The switch pins are easy to bend, so make sure that they are straight and enter the socket holes cleanly.
   - Double-check that each switch is fully seated and flush with the plate.
   - After installing a few switches, check that the PCB and plate remain properly aligned. Adjust if needed before continuing.
   - Once all switches are installed, you can flash the firmware and test each key to confirm proper installation and electrical contact.

1. **Secure with Screws**
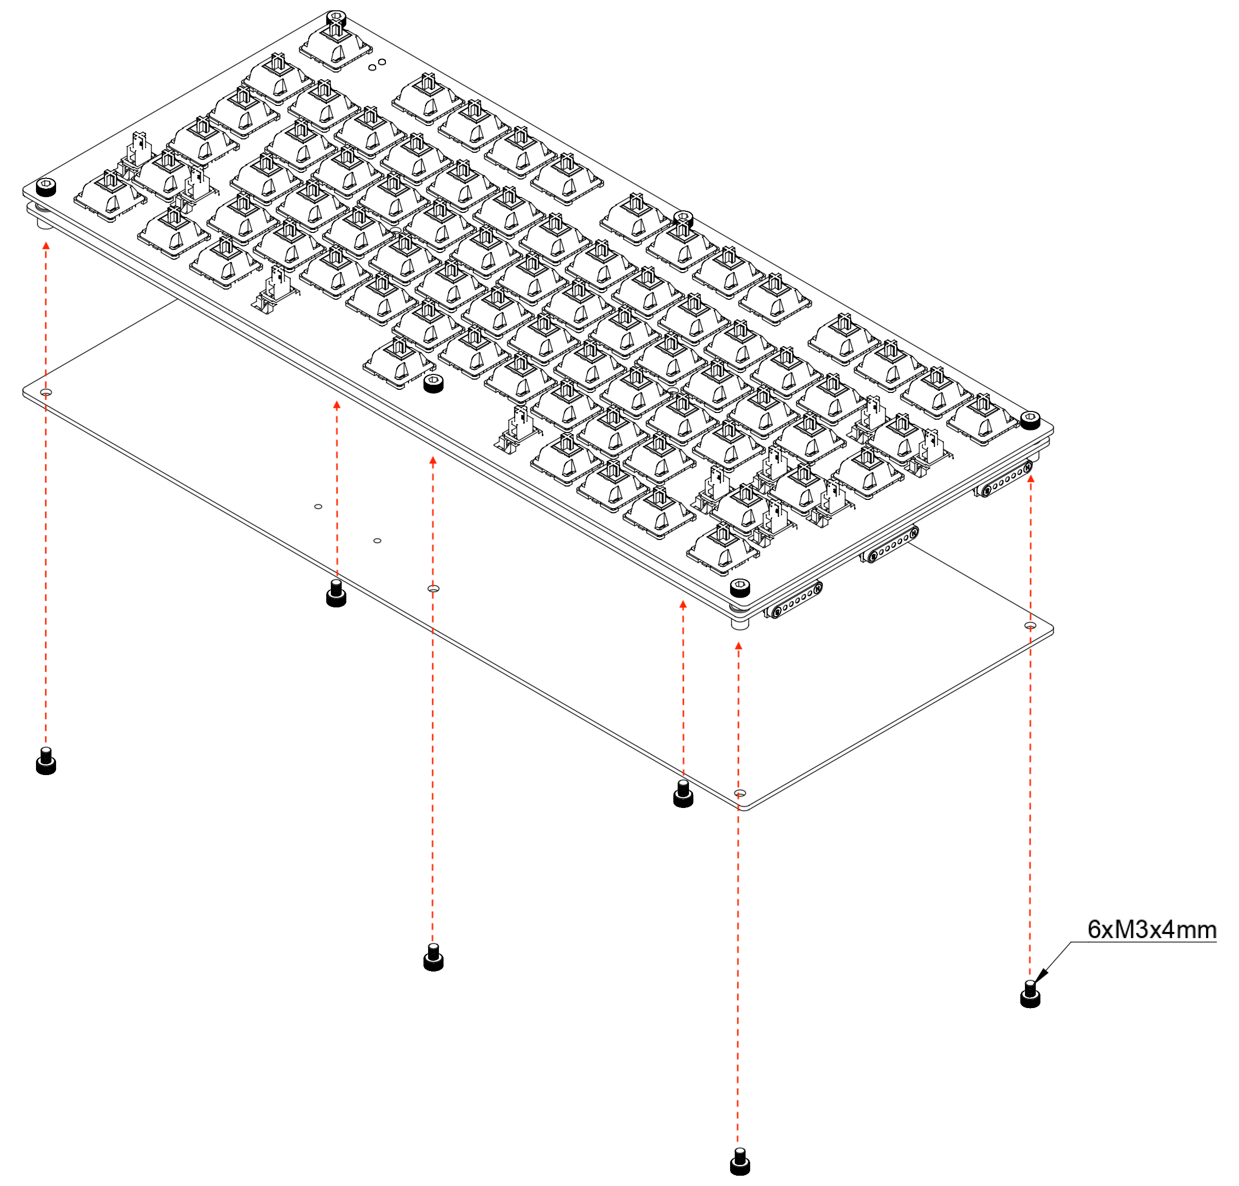
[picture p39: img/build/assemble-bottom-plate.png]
   
   - Place the bottom plate onto the assembled stack.
   - Use 8 M3x4mm screws for any additional mounting points as needed.
   - Tighten all screws evenly, but do not overtighten. It's just enough to hold everything securely and avoid damaging the PCB or plates.

1. **Add Keycaps**
   - Press the keycaps onto each switch stem. Double-check orientation and fit.
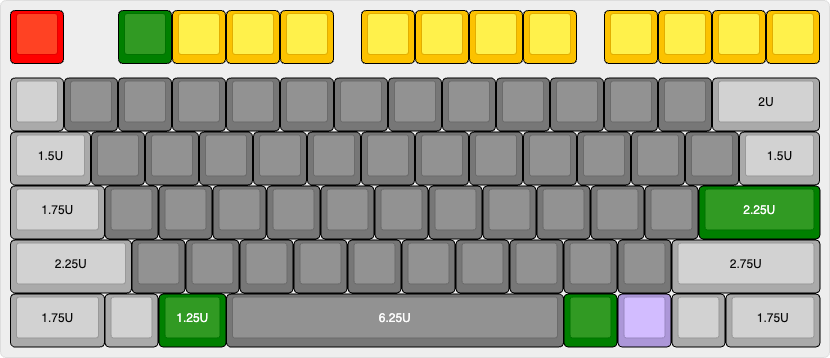
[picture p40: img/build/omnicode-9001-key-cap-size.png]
     

1. **Final Check**
   - Inspect all keys for proper fit and alignment.
   - Test each switch for electrical contact and smooth actuation.

## Tips
- Take your time with switch and socket installation for best results.

Enjoy your custom GlyphMatrix build!
    
## One more thing!
- If you seek to unlock the true potential of your GlyphMatrix, legends speak of two mysterious modules: [**PhaseShift**](./build_phaseshift.md) and [**DeltaForm**](./build_deltaform.md).
- When all three blocks are combined, the GlyphMatrix transcends its limits and evolves into **OmniCode:9001**, the ultimate keyboard fusion, worthy of the most legendary coders. Unleash your final form!:w

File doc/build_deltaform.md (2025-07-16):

# Build Guide - DeltaForm

> **Note:** DeltaForm is an add-on block for the GlyphMatrix keyboard. It cannot function independently and must be connected to a GlyphMatrix for operation.



## Parts
### Required
| Part | Quantity | Notes |
|---|---|---|
| MX key switches | 21 | |
| Hot swap sockets | 21 | |
| Keycaps | 21 | |
| M3x8mm screws | 4 | |
| Spacers (3mm) | 4 | |
| M3 gaskets (0.5mm)  | 4 | |
| M3x4mm screws | 4 | |
| M3 Standoffs (5mm)  | 4 | |
| POGO Pin 5P (curved)| 1 Set | For connection to GlyphMatrix |
| POGO Pin 7P (curved)| 2 Set | For connection to GlyphMatrix |

### Optional
| Part | Quantity | Notes |
|---|---|---|
| RGB LEDs | 21 | SK6812 mini-e |

## Steps

1. **Soldering Hot Swap Sockets and LEDs**
   - Solder all 21 hot swap sockets onto the PCB, aligning each socket with the footprint.
   - Install POGO pins for connection to GlyphMatrix, following the same alignment and soldering tips as in the GlyphMatrix guide.
   - (Optional) Solder per-key LEDs onto the PCB, ensuring correct orientation.

2. **Prepare Top Plate and Mounting Hardware**
   - Place the top plate onto the PCB.
   - Position the 4 spacers (3mm) at the mounting points.
   - Add M3 gaskets (0.5mm) between PCB and spacers.
   - Add 4 standoffs (5mm) at the bottom side of the PCB.
   - Insert 4 M3x8mm screws through the top plate, spacers, gaskets, and PCB, then loosely fasten with 5mm standoffs.
   - **Do not fully tighten yet.**

3. **Install Key Switches**
   - Carefully align each switch and press straight down into the socket. Check for bent pins.
   - Ensure all switches are fully seated and flush with the plate.

4. **Secure with Screws**
   - Place the bottom plate onto the stack.
   - Use 4 M3x4mm screws for any additional mounting points.
   - Tighten all screws evenly, but do not overtighten.

5. **Add Keycaps**
   - Press keycaps onto each switch stem.

6. **Final Check**
   - Inspect for fit and alignment.
   - Test for electrical contact after connecting to GlyphMatrix.

## Tips
- DeltaForm must be connected to a GlyphMatrix to function.
- Take your time with switch and socket installation for best results.

Enjoy your custom DeltaForm build!

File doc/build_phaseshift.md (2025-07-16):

# Build Guide - PhaseShift

> **Note:** PhaseShift is an add-on block for the GlyphMatrix keyboard. It cannot function independently and must be connected to a GlyphMatrix for operation.



## Parts
### Required
| Part | Quantity | Notes |
|---|---|---|
| MX key switches | 12 | |
| Hot swap sockets | 12 | |
| Keycaps | 12 | |
| M3x8mm screws | 4 | |
| Spacers (3mm) | 4 | |
| M3 gaskets (0.5mm)  | 4 | |
| M3x4mm screws | 4 | |
| M3 Standoffs (5mm)  | 4 | |
| POGO Pin 5P (curved)| 1 Set | For connection to GlyphMatrix |
| POGO Pin 7P (curved)| 2 Set | For connection to GlyphMatrix |

### Optional
| Part | Quantity | Notes |
|---|---|---|
| RGB LEDs | 12 | SK6812 mini-e |

## Steps

1. **Soldering Hot Swap Sockets and LEDs**
   - Solder all 12 hot swap sockets onto the PCB, aligning each socket with the footprint.
   - Install POGO pins for connection to GlyphMatrix, following the same alignment and soldering tips as in the GlyphMatrix guide.
   - (Optional) Solder per-key LEDs onto the PCB, ensuring correct orientation.

2. **Prepare Top Plate and Mounting Hardware**
   - Place the top plate onto the PCB.
   - Position the 4 spacers (3mm) at the mounting points.
   - Add M3 gaskets (0.5mm) between PCB and spacers.
   - Add 4 standoffs (5mm) at the bottom side of the PCB.
   - Insert 4 M3x8mm screws through the top plate, spacers, gaskets, and PCB, then loosely fasten with 5mm standoffs.
   - **Do not fully tighten yet.**

3. **Install Key Switches**
   - Carefully align each switch and press straight down into the socket. Check for bent pins.
   - Ensure all switches are fully seated and flush with the plate.

4. **Secure with Screws**
   - Place the bottom plate onto the stack.
   - Use 4 M3x4mm screws for any additional mounting points.
   - Tighten all screws evenly, but do not overtighten.

5. **Add Keycaps**
   - Press keycaps onto each switch stem.

6. **Final Check**
   - Inspect for fit and alignment.
   - Test for electrical contact after connecting to GlyphMatrix.

## Tips
- PhaseShift must be connected to a GlyphMatrix to function.
- Take your time with switch and socket installation for best results.

Enjoy your custom PhaseShift build!

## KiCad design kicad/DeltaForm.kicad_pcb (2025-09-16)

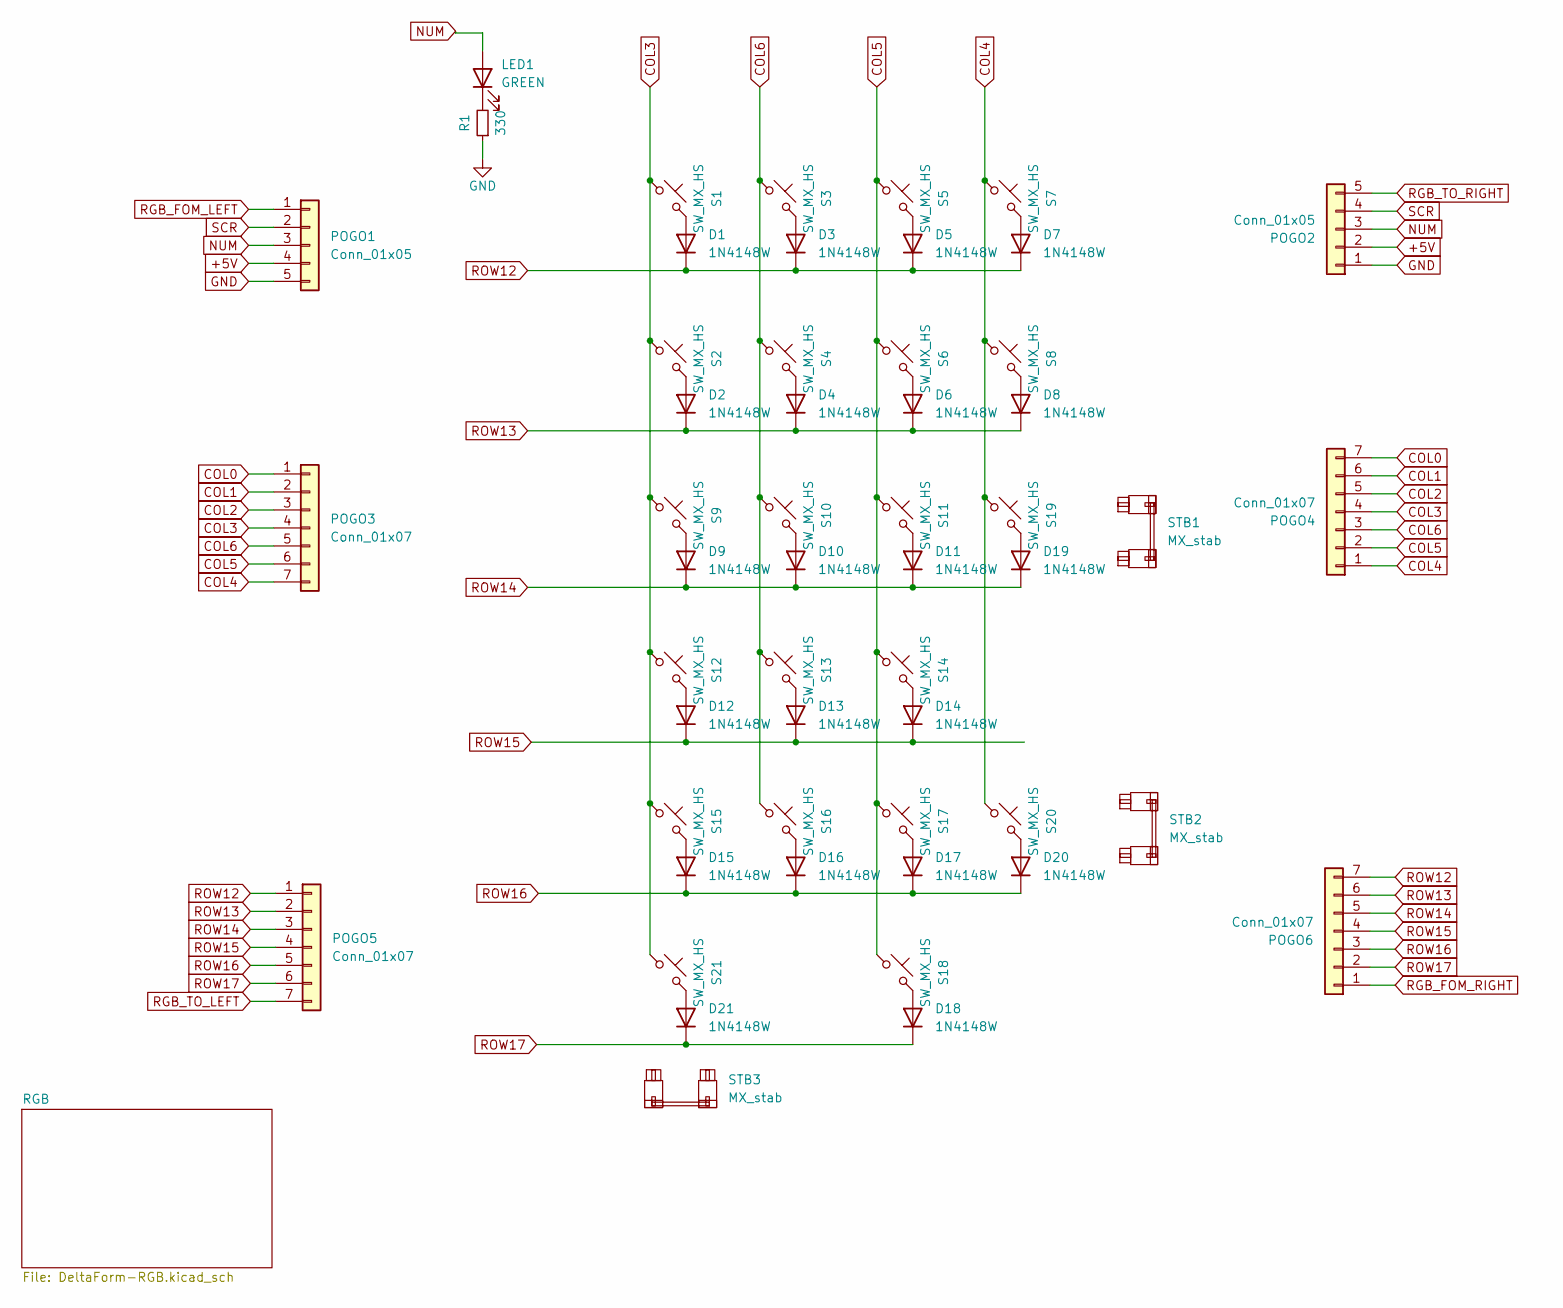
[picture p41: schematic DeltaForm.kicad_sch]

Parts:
D1, D2, D3, D4, D5, D6, D7, D8, D9, D10, D11, D12, D13, D14, D15, D16, D17, D18, D19, D20, D21: 1N4148W; D3_SMD; LCSC C7420318
LED1: GREEN; LED_0603_1608Metric_Pad1.05x0.95mm_HandSolder; LCSC C84264
POGO1, POGO2: Conn_01x05; Pogopin_1x05_P2.54mm_Curved
POGO3, POGO4, POGO5, POGO6: Conn_01x07; Pogopin_1x07_P2.54mm_Curved
R1: 330; R_0603_1608Metric; LCSC C23138
S1, S2, S3, S4, S5, S6, S7, S8, S9, S10, S11, S12, S13, S14, S15, S16, S17, S18, S19, S20: SW_MX_HS; SW_MX_HS_1u; LCSC C9900021274
S21: SW_MX_HS; SW_MX_HS_2u; LCSC C9900021274
STB1, STB2, STB3: MX_stab; Stabilizer_Cherry_MX_2.00u

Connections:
+5V: POGO1.4, POGO2.2; also elsewhere on the board
COL0: POGO3.1, POGO4.7
COL1: POGO3.2, POGO4.6
COL2: POGO3.3, POGO4.5
COL3: POGO3.4, POGO4.4, S1.2, S2.2, S9.2, S12.2, S15.2, S21.2
COL4: POGO3.7, POGO4.1, S7.2, S8.2, S19.2, S20.2
COL5: POGO3.6, POGO4.2, S5.2, S6.2, S11.2, S14.2, S17.2, S18.2
COL6: POGO3.5, POGO4.3, S3.2, S4.2, S10.2, S13.2, S16.2
GND: POGO1.5, POGO2.1, R1.1; also elsewhere on the board
NUM: LED1.2 (A), POGO1.3, POGO2.3
unnamed: D1.2 (A), S1.1
unnamed: D2.2 (A), S2.1
unnamed: D3.2 (A), S3.1
unnamed: D4.2 (A), S4.1
unnamed: D5.2 (A), S5.1
unnamed: D6.2 (A), S6.1
unnamed: D7.2 (A), S7.1
unnamed: D8.2 (A), S8.1
unnamed: D9.2 (A), S9.1
unnamed: D10.2 (A), S10.1
unnamed: D11.2 (A), S11.1
unnamed: D12.2 (A), S12.1
unnamed: D13.2 (A), S13.1
unnamed: D14.2 (A), S14.1
unnamed: D15.2 (A), S15.1
unnamed: D16.2 (A), S16.1
unnamed: D17.2 (A), S17.1
unnamed: D18.2 (A), S18.1
unnamed: D19.2 (A), S19.1
unnamed: D20.2 (A), S20.1
unnamed: D21.2 (A), S21.1
unnamed: LED1.1 (K), R1.2
RGB_FOM_LEFT: POGO1.1; also elsewhere on the board
RGB_FOM_RIGHT: POGO6.1; also elsewhere on the board
RGB_TO_LEFT: POGO5.7; also elsewhere on the board
RGB_TO_RIGHT: POGO2.5; also elsewhere on the board
ROW12: D1.1 (K), D3.1 (K), D5.1 (K), D7.1 (K), POGO5.1, POGO6.7
ROW13: D2.1 (K), D4.1 (K), D6.1 (K), D8.1 (K), POGO5.2, POGO6.6
ROW14: D9.1 (K), D10.1 (K), D11.1 (K), D19.1 (K), POGO5.3, POGO6.5
ROW15: D12.1 (K), D13.1 (K), D14.1 (K), POGO5.4, POGO6.4
ROW16: D15.1 (K), D16.1 (K), D17.1 (K), D20.1 (K), POGO5.5, POGO6.3
ROW17: D18.1 (K), D21.1 (K), POGO5.6, POGO6.2
SCR: POGO1.2, POGO2.4

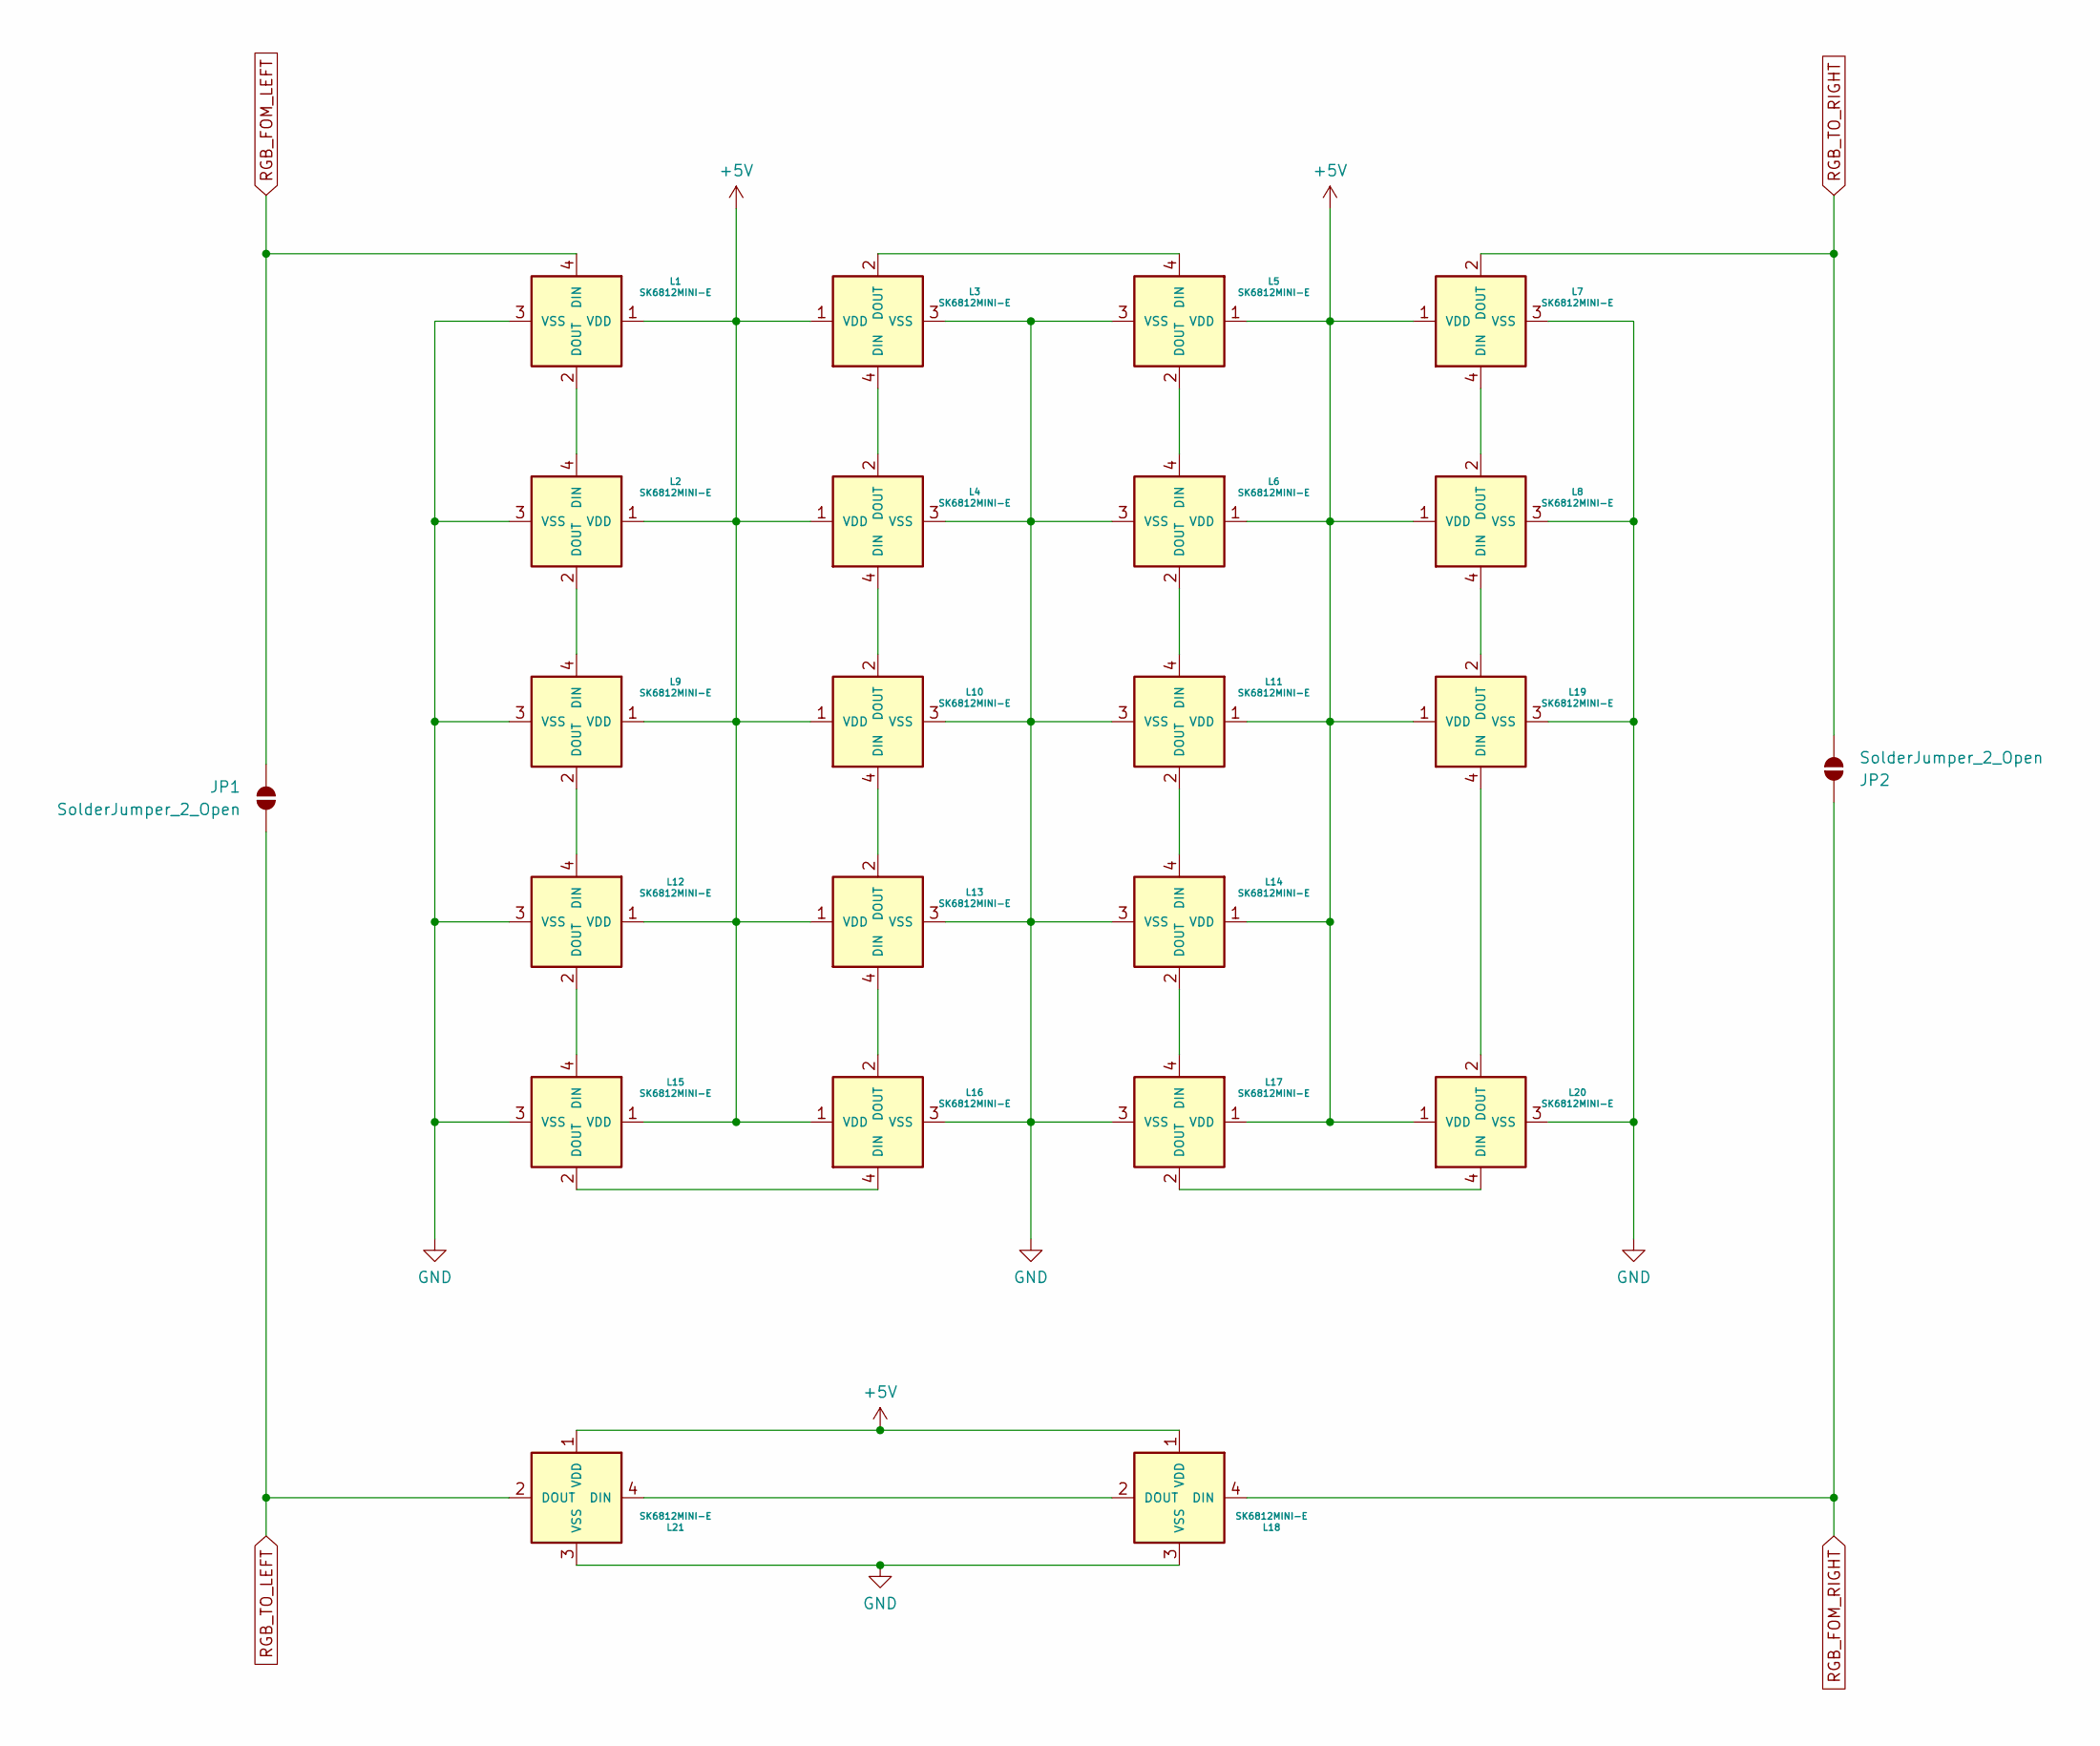
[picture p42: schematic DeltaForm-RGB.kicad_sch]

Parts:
JP1, JP2: SolderJumper_2_Open; SolderJumper-2_P1.3mm_Open_TrianglePad1.0x1.5mm
L1, L2, L3, L4, L5, L6, L7, L8, L9, L10, L11, L12, L13, L14, L15, L16, L17, L18, L19, L20, L21: SK6812MINI-E; LED_SK6812MINI-E; LCSC C7420318

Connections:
+5V: L1.1 (VDD), L2.1 (VDD), L3.1 (VDD), L4.1 (VDD), L5.1 (VDD), L6.1 (VDD), L7.1 (VDD), L8.1 (VDD), L9.1 (VDD), L10.1 (VDD), L11.1 (VDD), L12.1 (VDD), L13.1 (VDD), L14.1 (VDD), L15.1 (VDD), L16.1 (VDD), L17.1 (VDD), L18.1 (VDD), L19.1 (VDD), L20.1 (VDD), L21.1 (VDD); also elsewhere on the board
GND: L1.3 (VSS), L2.3 (VSS), L3.3 (VSS), L4.3 (VSS), L5.3 (VSS), L6.3 (VSS), L7.3 (VSS), L8.3 (VSS), L9.3 (VSS), L10.3 (VSS), L11.3 (VSS), L12.3 (VSS), L13.3 (VSS), L14.3 (VSS), L15.3 (VSS), L16.3 (VSS), L17.3 (VSS), L18.3 (VSS), L19.3 (VSS), L20.3 (VSS), L21.3 (VSS); also elsewhere on the board
unnamed: L1.2 (DOUT), L2.4 (DIN)
unnamed: L2.2 (DOUT), L9.4 (DIN)
unnamed: L3.4 (DIN), L4.2 (DOUT)
unnamed: L3.2 (DOUT), L5.4 (DIN)
unnamed: L5.2 (DOUT), L6.4 (DIN)
unnamed: L7.4 (DIN), L8.2 (DOUT)
unnamed: L10.4 (DIN), L13.2 (DOUT)
unnamed: L4.4 (DIN), L10.2 (DOUT)
unnamed: L6.2 (DOUT), L11.4 (DIN)
unnamed: L11.2 (DOUT), L14.4 (DIN)
unnamed: L9.2 (DOUT), L12.4 (DIN)
unnamed: L12.2 (DOUT), L15.4 (DIN)
unnamed: L13.4 (DIN), L16.2 (DOUT)
unnamed: L14.2 (DOUT), L17.4 (DIN)
unnamed: L15.2 (DOUT), L16.4 (DIN)
unnamed: L17.2 (DOUT), L20.4 (DIN)
unnamed: L18.2 (DOUT), L21.4 (DIN)
unnamed: L19.4 (DIN), L20.2 (DOUT)
unnamed: L8.4 (DIN), L19.2 (DOUT)
RGB_FOM_LEFT: JP1.2 (B), L1.4 (DIN); also elsewhere on the board
RGB_FOM_RIGHT: JP2.2 (B), L18.4 (DIN); also elsewhere on the board
RGB_TO_LEFT: JP1.1 (A), L21.2 (DOUT); also elsewhere on the board
RGB_TO_RIGHT: JP2.1 (A), L7.2 (DOUT); also elsewhere on the board

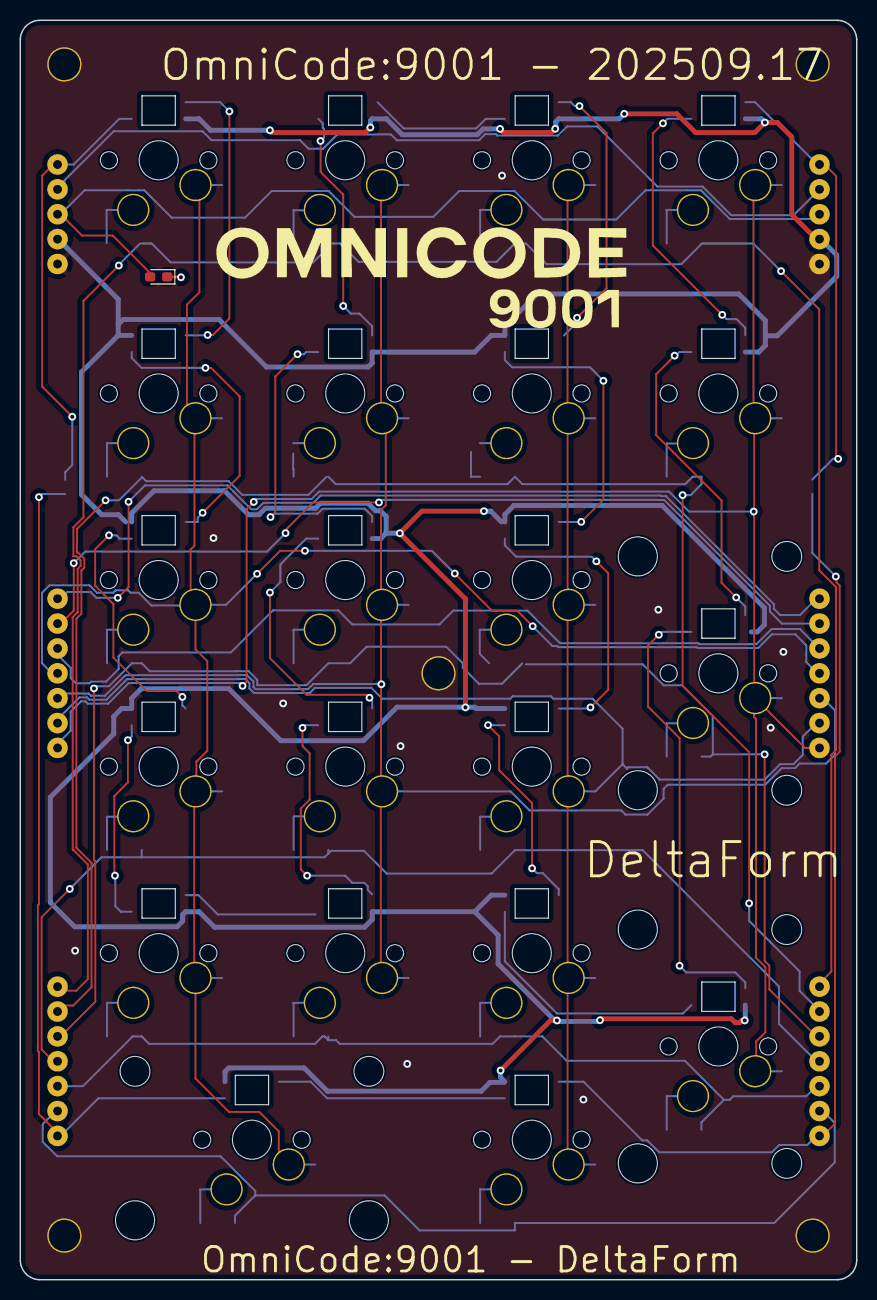
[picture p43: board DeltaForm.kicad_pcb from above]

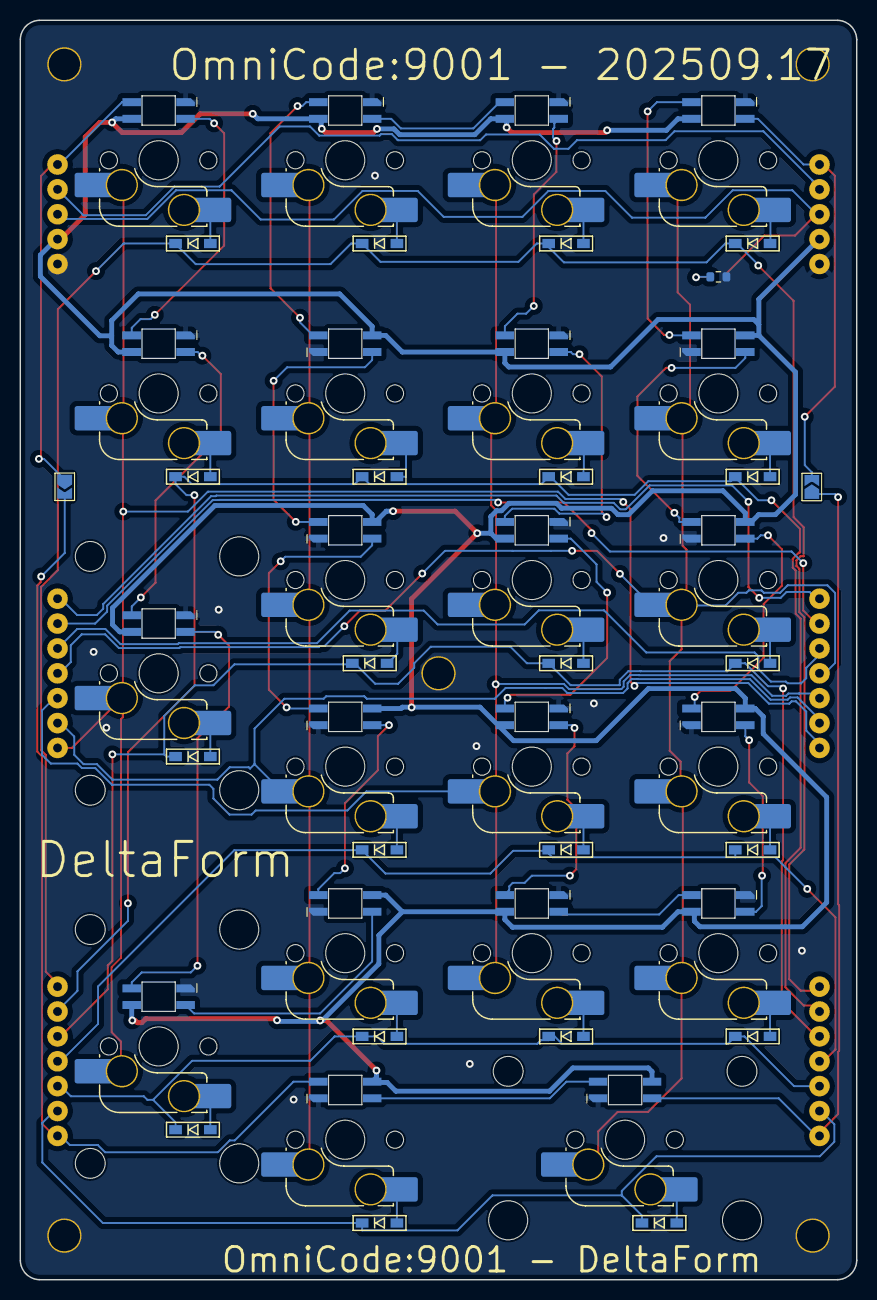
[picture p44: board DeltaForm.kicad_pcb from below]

Board: 2 copper layers, 85.4 x 128.6 mm, 81 parts (72 on the bottom side), 62 nets.

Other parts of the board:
H1, H2, H3, H4, H5: MountingHole_3.2mm_Pad

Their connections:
GND: H1.1, H2.1, H3.1, H4.1, H5.1; also elsewhere on the board

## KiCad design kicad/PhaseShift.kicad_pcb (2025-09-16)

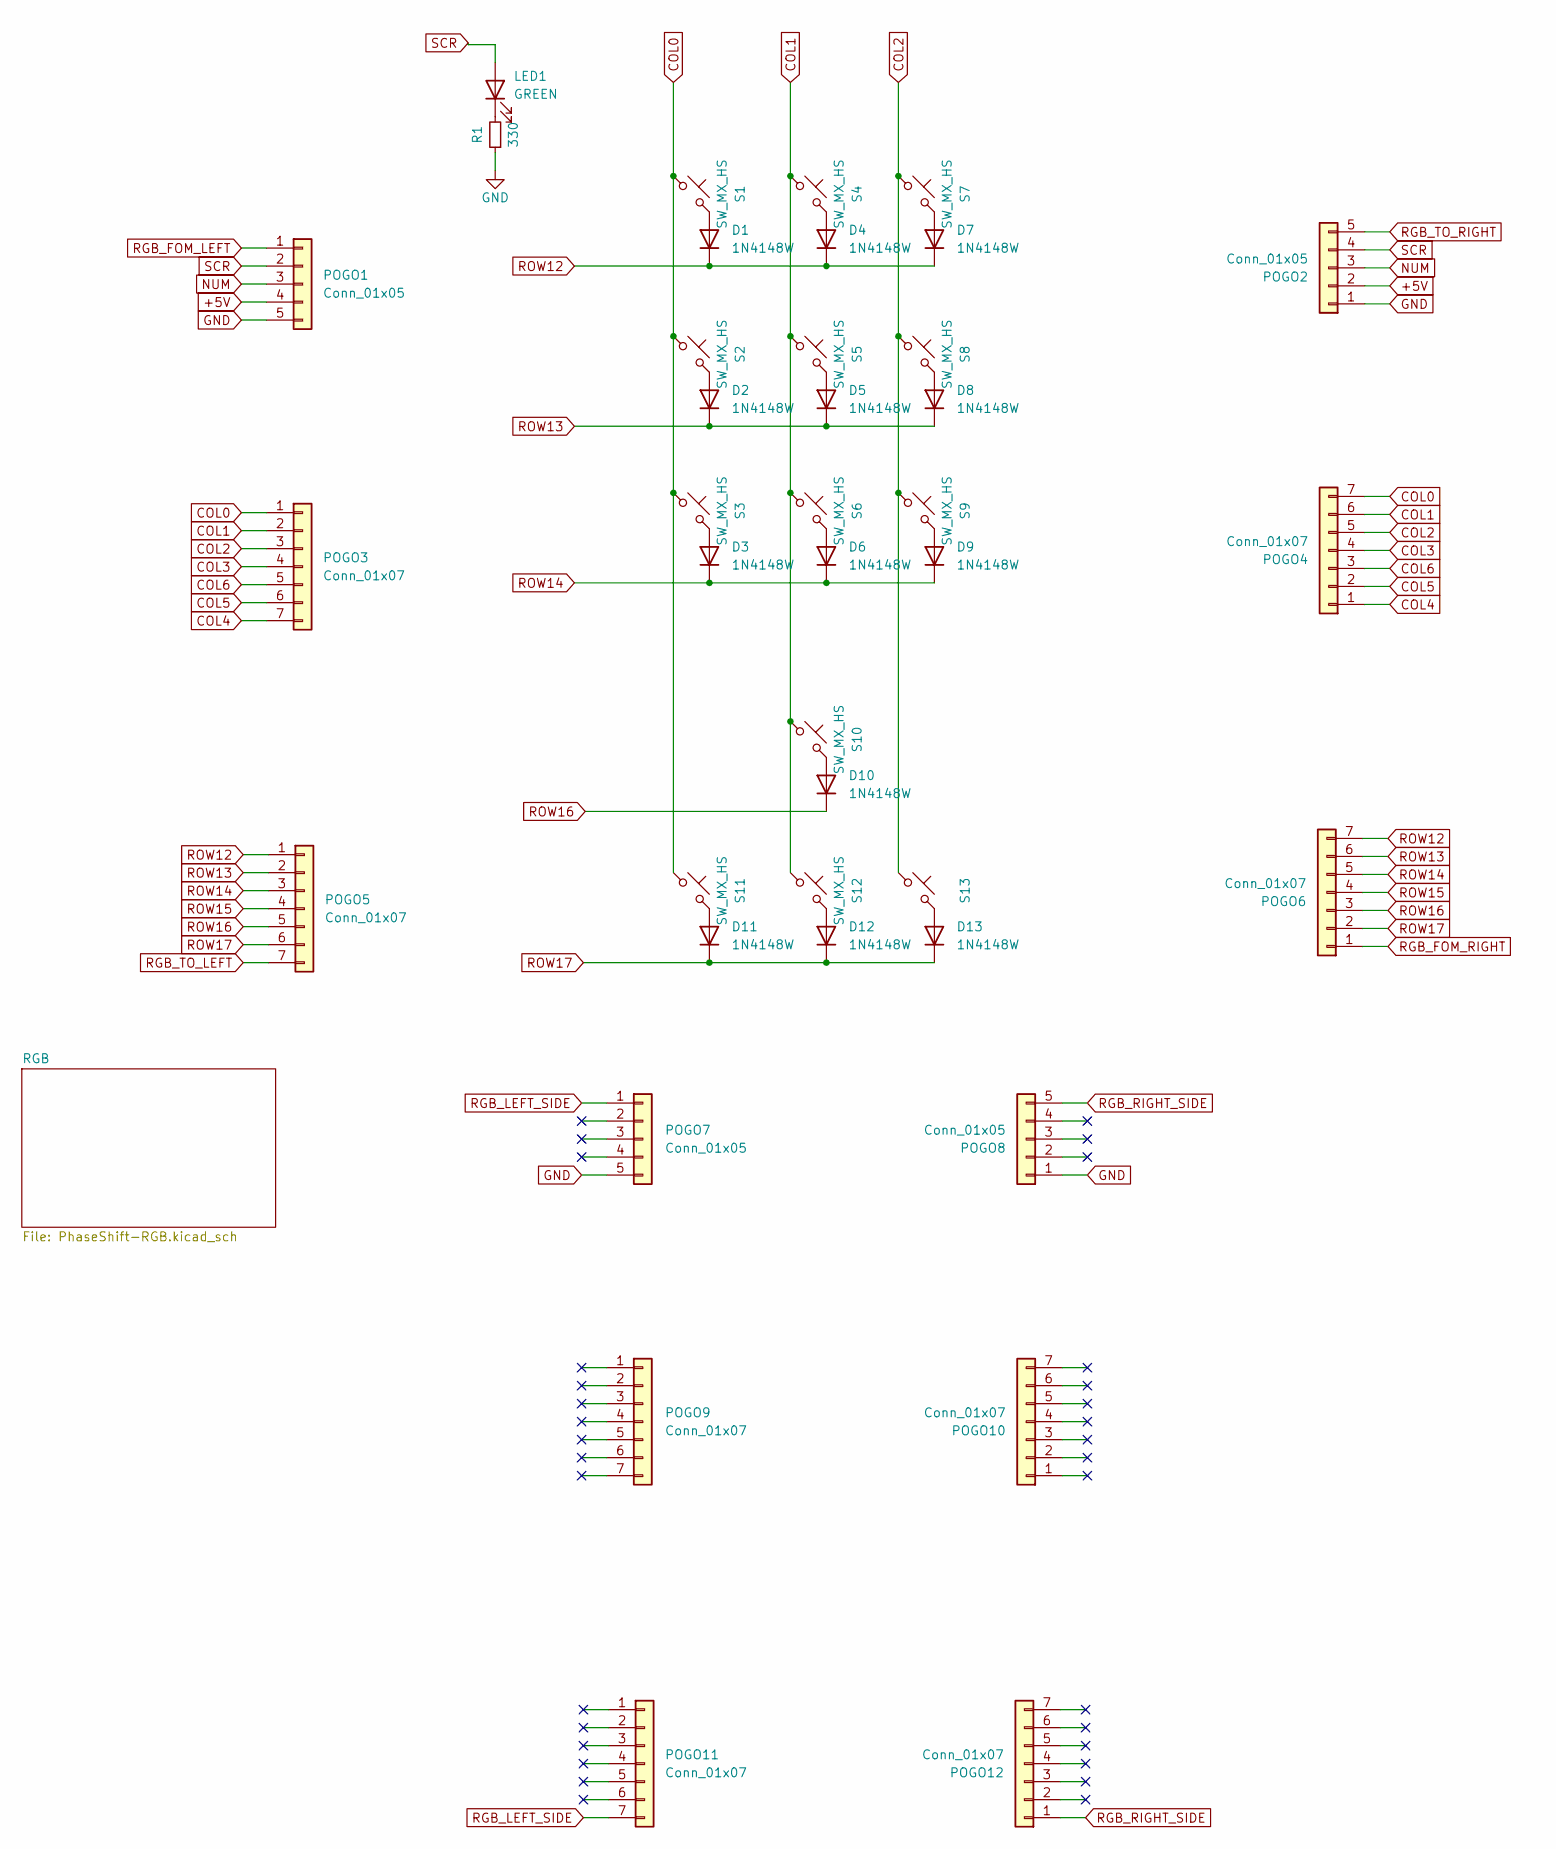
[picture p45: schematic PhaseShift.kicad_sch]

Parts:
D1, D2, D3, D4, D5, D6, D7, D8, D9, D10, D11, D12, D13: 1N4148W; D3_SMD; LCSC C7420318
LED1: GREEN; LED_0603_1608Metric_Pad1.05x0.95mm_HandSolder; LCSC C84264
POGO1, POGO2: Conn_01x05; Pogopin_1x05_P2.54mm_Curved
POGO3, POGO4, POGO5, POGO6: Conn_01x07; Pogopin_1x07_P2.54mm_Curved
POGO7, POGO8: Conn_01x05; Pogopin_1x05_P2.54mm
POGO9, POGO10, POGO11, POGO12: Conn_01x07; Pogopin_1x07_P2.54mm
R1: 330; R_0603_1608Metric; LCSC C23138
S1, S2, S3, S4, S5, S6, S7, S8, S9, S10, S11, S12: SW_MX_HS; SW_MX_HS_1u; LCSC C9900021274
S13: SW_MX_HS_1u; LCSC C9900021274

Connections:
+5V: POGO1.4, POGO2.2; also elsewhere on the board
COL0: POGO3.1, POGO4.7, S1.2, S2.2, S3.2, S11.2
COL1: POGO3.2, POGO4.6, S4.2, S5.2, S6.2, S10.2, S12.2
COL2: POGO3.3, POGO4.5, S7.2, S8.2, S9.2, S13.2
COL3: POGO3.4, POGO4.4
COL4: POGO3.7, POGO4.1
COL5: POGO3.6, POGO4.2
COL6: POGO3.5, POGO4.3
GND: POGO1.5, POGO2.1, POGO7.5, POGO8.1, R1.1; also elsewhere on the board
NUM: POGO1.3, POGO2.3
unnamed: D1.2 (A), S1.1
unnamed: D2.2 (A), S2.1
unnamed: D3.2 (A), S3.1
unnamed: D4.2 (A), S4.1
unnamed: D5.2 (A), S5.1
unnamed: D6.2 (A), S6.1
unnamed: D7.2 (A), S7.1
unnamed: D8.2 (A), S8.1
unnamed: D9.2 (A), S9.1
unnamed: D10.2 (A), S10.1
unnamed: D11.2 (A), S11.1
unnamed: D12.2 (A), S12.1
unnamed: D13.2 (A), S13.1
unnamed: LED1.1 (K), R1.2
RGB_FOM_LEFT: POGO1.1; also elsewhere on the board
RGB_FOM_RIGHT: POGO6.1; also elsewhere on the board
RGB_LEFT_SIDE: POGO7.1, POGO11.7
RGB_RIGHT_SIDE: POGO8.5, POGO12.1
RGB_TO_LEFT: POGO5.7; also elsewhere on the board
RGB_TO_RIGHT: POGO2.5; also elsewhere on the board
ROW12: D1.1 (K), D4.1 (K), D7.1 (K), POGO5.1, POGO6.7
ROW13: D2.1 (K), D5.1 (K), D8.1 (K), POGO5.2, POGO6.6
ROW14: D3.1 (K), D6.1 (K), D9.1 (K), POGO5.3, POGO6.5
ROW15: POGO5.4, POGO6.4
ROW16: D10.1 (K), POGO5.5, POGO6.3
ROW17: D11.1 (K), D12.1 (K), D13.1 (K), POGO5.6, POGO6.2
SCR: LED1.2 (A), POGO1.2, POGO2.4

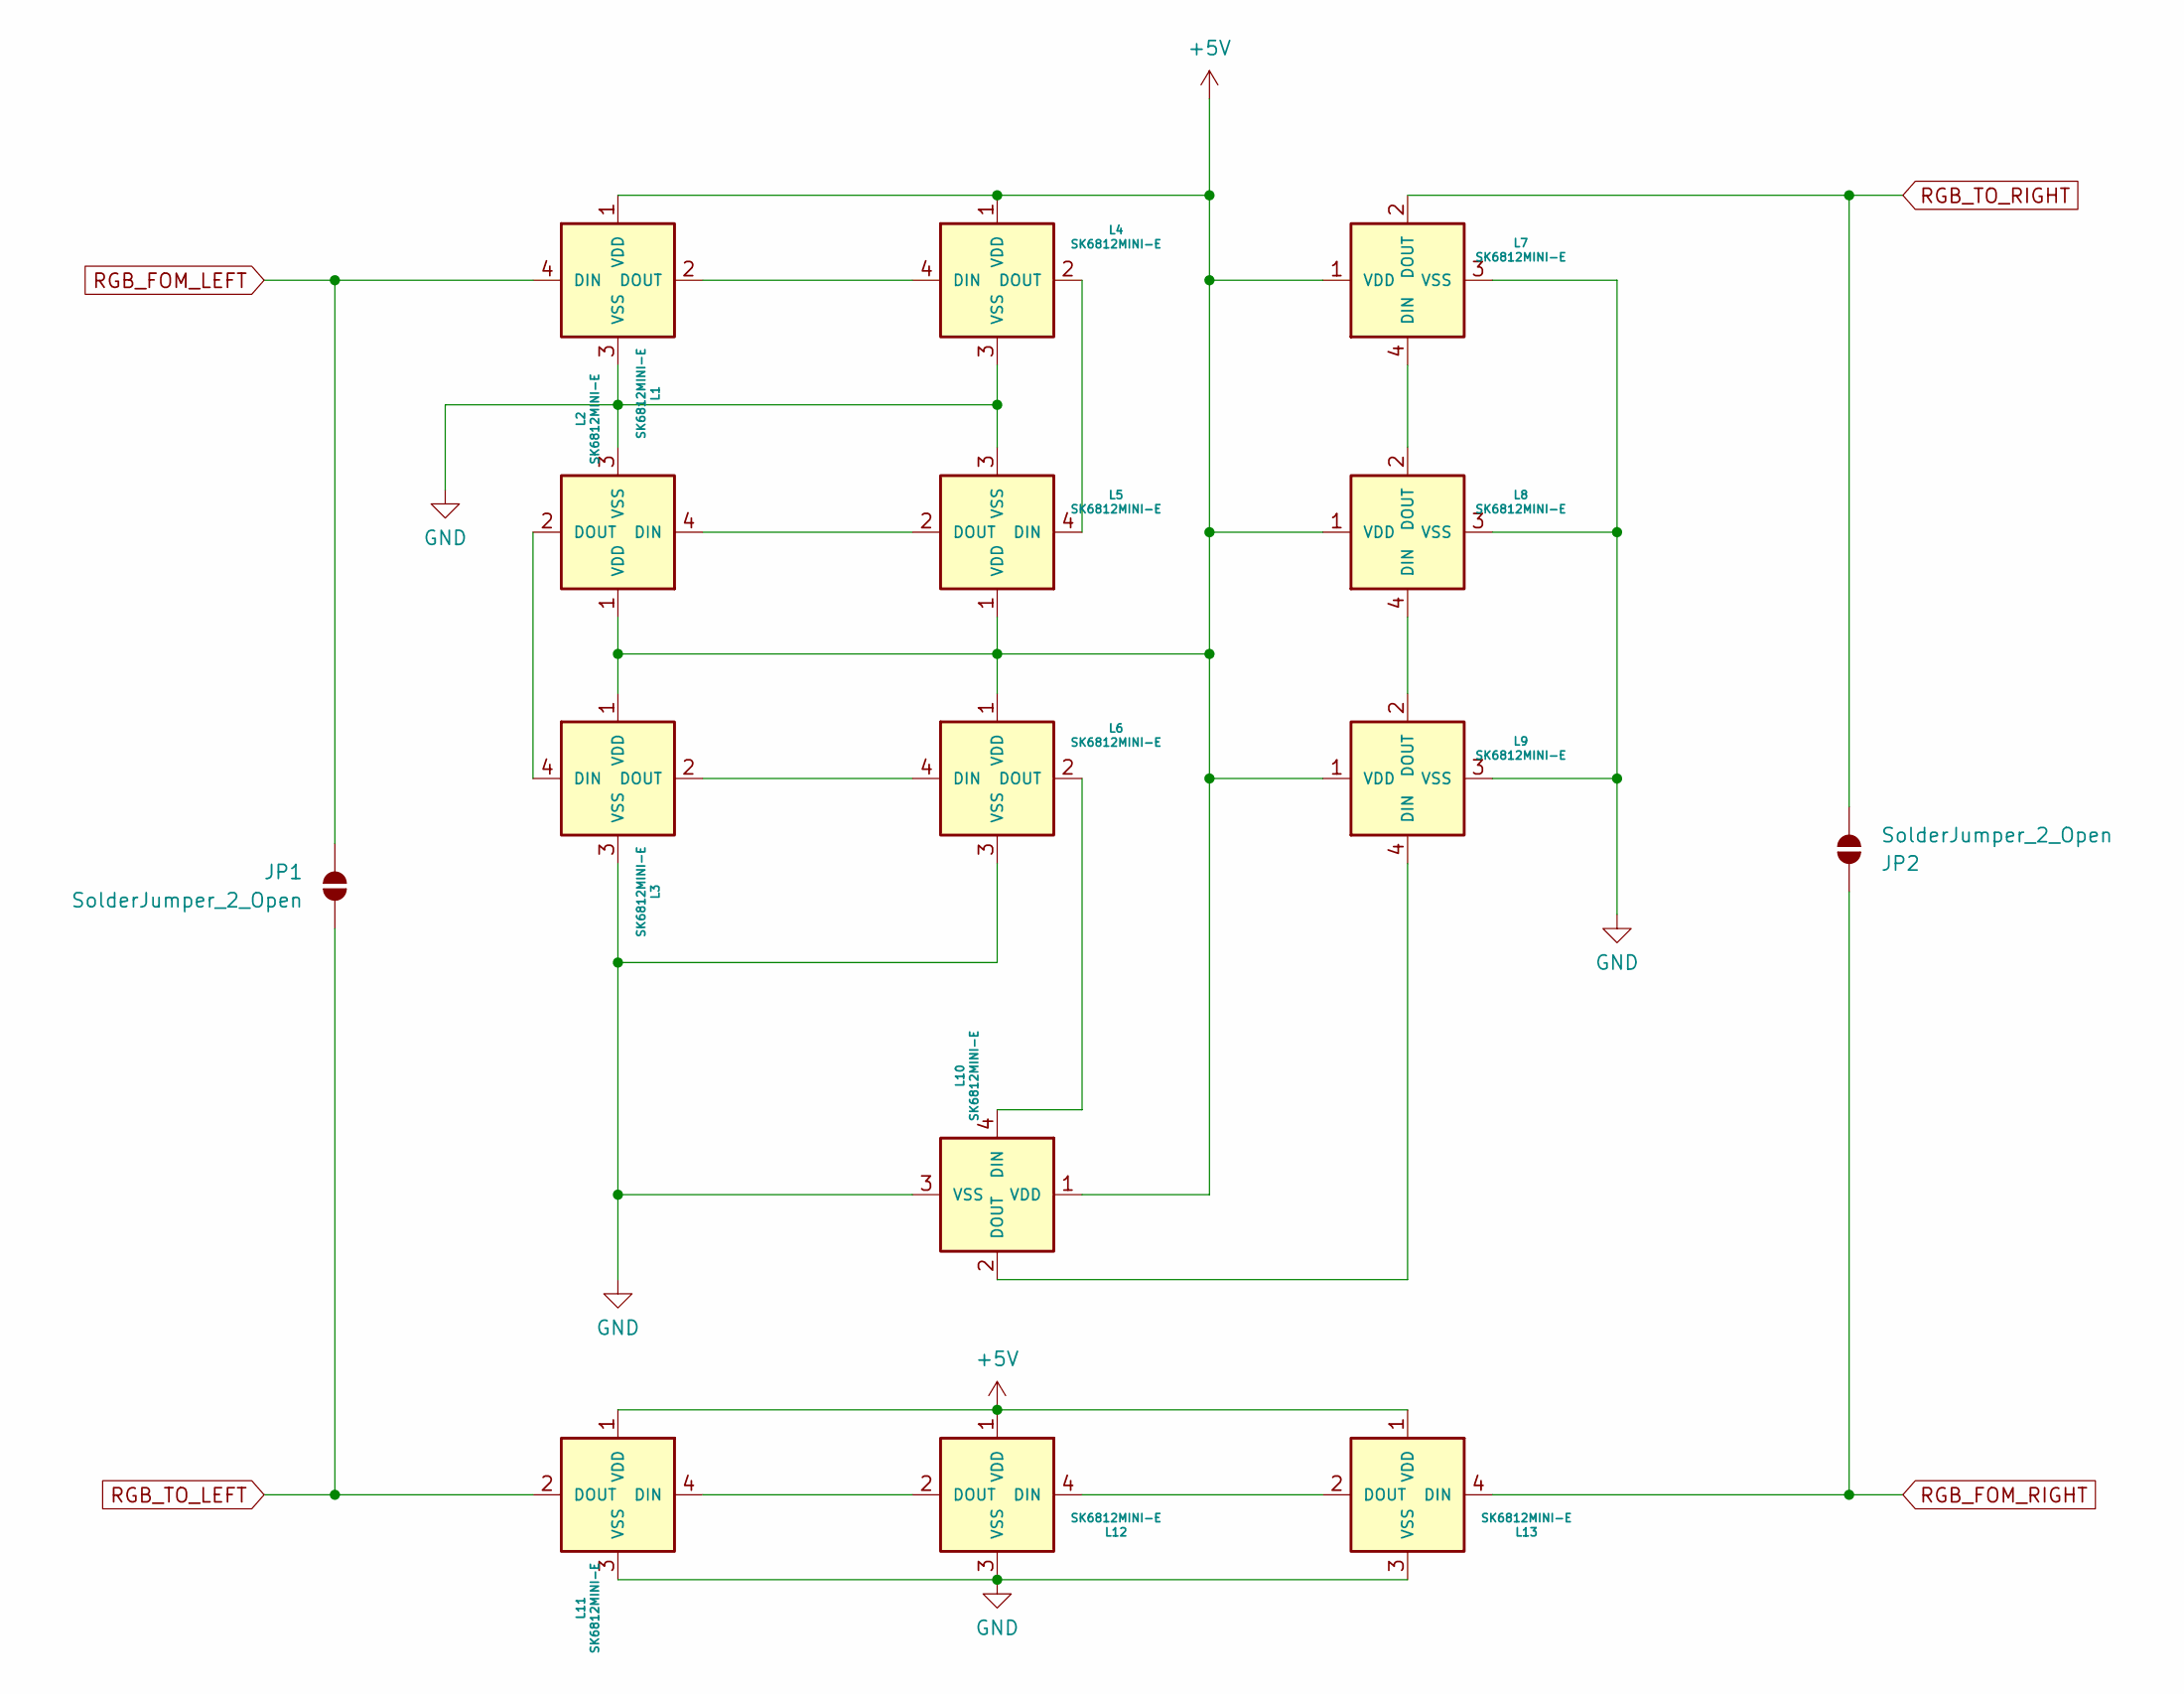
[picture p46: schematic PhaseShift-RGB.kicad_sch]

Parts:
JP1, JP2: SolderJumper_2_Open; SolderJumper-2_P1.3mm_Open_TrianglePad1.0x1.5mm
L1, L2, L3, L4, L5, L6, L7, L8, L9, L10, L11, L12, L13: SK6812MINI-E; LED_SK6812MINI-E; LCSC C7420318

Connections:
+5V: L1.1 (VDD), L2.1 (VDD), L3.1 (VDD), L4.1 (VDD), L5.1 (VDD), L6.1 (VDD), L7.1 (VDD), L8.1 (VDD), L9.1 (VDD), L10.1 (VDD), L11.1 (VDD), L12.1 (VDD), L13.1 (VDD); also elsewhere on the board
GND: L1.3 (VSS), L2.3 (VSS), L3.3 (VSS), L4.3 (VSS), L5.3 (VSS), L6.3 (VSS), L7.3 (VSS), L8.3 (VSS), L9.3 (VSS), L10.3 (VSS), L11.3 (VSS), L12.3 (VSS), L13.3 (VSS); also elsewhere on the board
unnamed: L1.2 (DOUT), L4.4 (DIN)
unnamed: L2.4 (DIN), L5.2 (DOUT)
unnamed: L2.2 (DOUT), L3.4 (DIN)
unnamed: L3.2 (DOUT), L6.4 (DIN)
unnamed: L4.2 (DOUT), L5.4 (DIN)
unnamed: L7.4 (DIN), L8.2 (DOUT)
unnamed: L8.4 (DIN), L9.2 (DOUT)
unnamed: L6.2 (DOUT), L10.4 (DIN)
unnamed: L9.4 (DIN), L10.2 (DOUT)
unnamed: L11.4 (DIN), L12.2 (DOUT)
unnamed: L12.4 (DIN), L13.2 (DOUT)
RGB_FOM_LEFT: JP1.2 (B), L1.4 (DIN); also elsewhere on the board
RGB_FOM_RIGHT: JP2.2 (B), L13.4 (DIN); also elsewhere on the board
RGB_TO_LEFT: JP1.1 (A), L11.2 (DOUT); also elsewhere on the board
RGB_TO_RIGHT: JP2.1 (A), L7.2 (DOUT); also elsewhere on the board

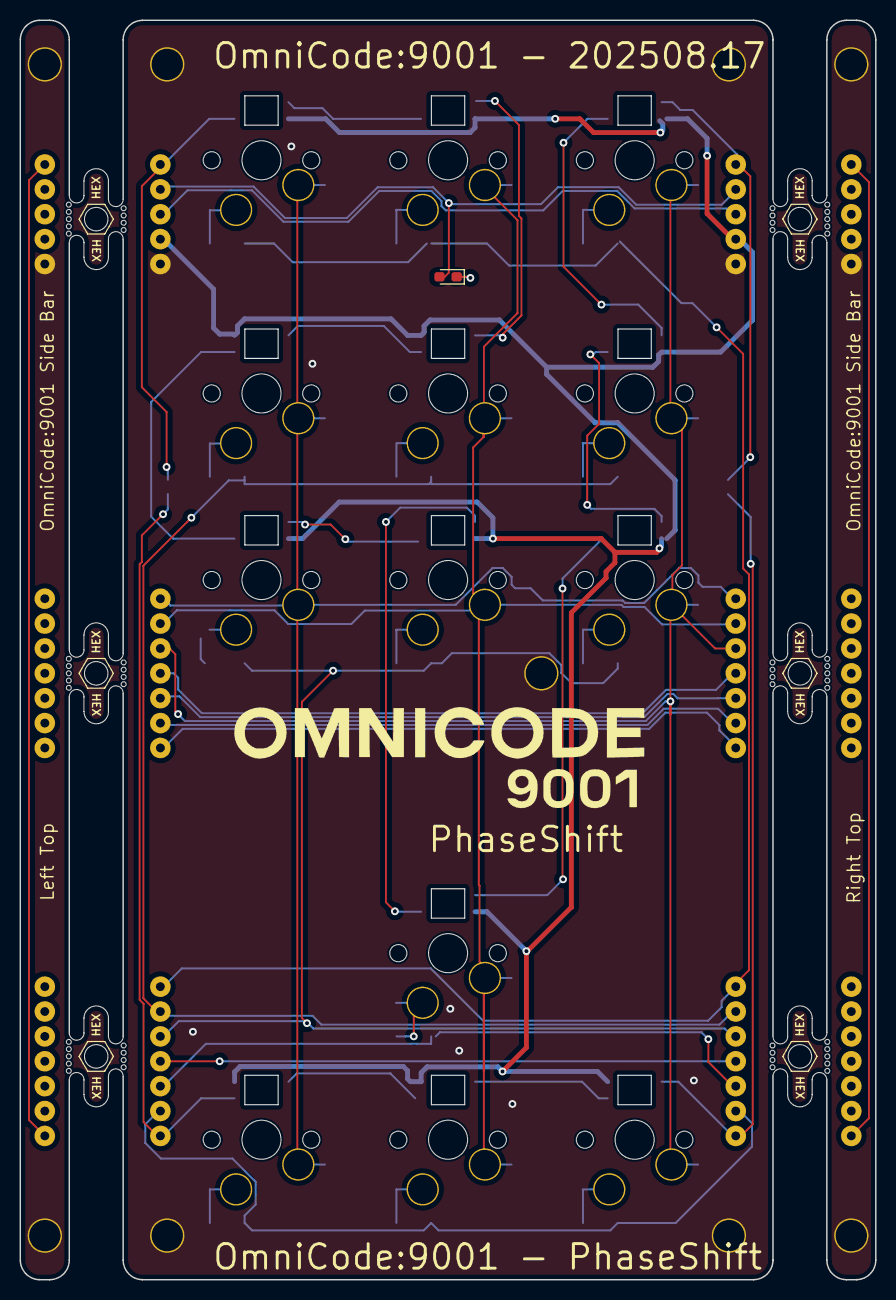
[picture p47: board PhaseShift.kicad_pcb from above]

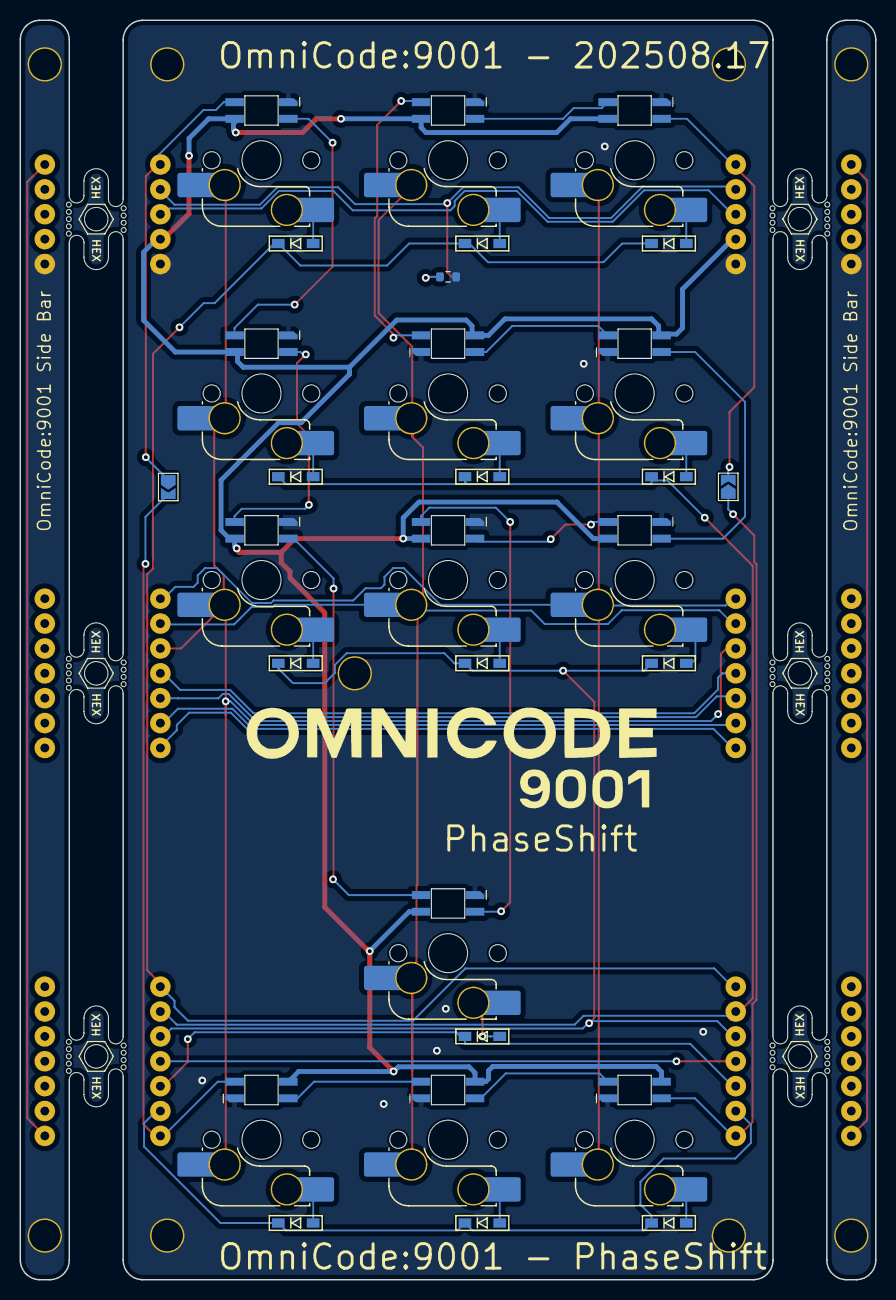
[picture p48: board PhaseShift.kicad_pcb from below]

Board: 2 copper layers, 87.4 x 128.6 mm, 70 parts (48 on the bottom side), 48 nets.

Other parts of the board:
H1, H2, H3, H4, H5, H6, H7, H8, H9: MountingHole_3.2mm_Pad
X1, X2, X3, X4, X5, X6: 5.5mm; mousebites_5p5mm_easysnap

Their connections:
GND: H1.1, H2.1, H3.1, H4.1, H5.1, H6.1, H7.1, H8.1, H9.1; also elsewhere on the board

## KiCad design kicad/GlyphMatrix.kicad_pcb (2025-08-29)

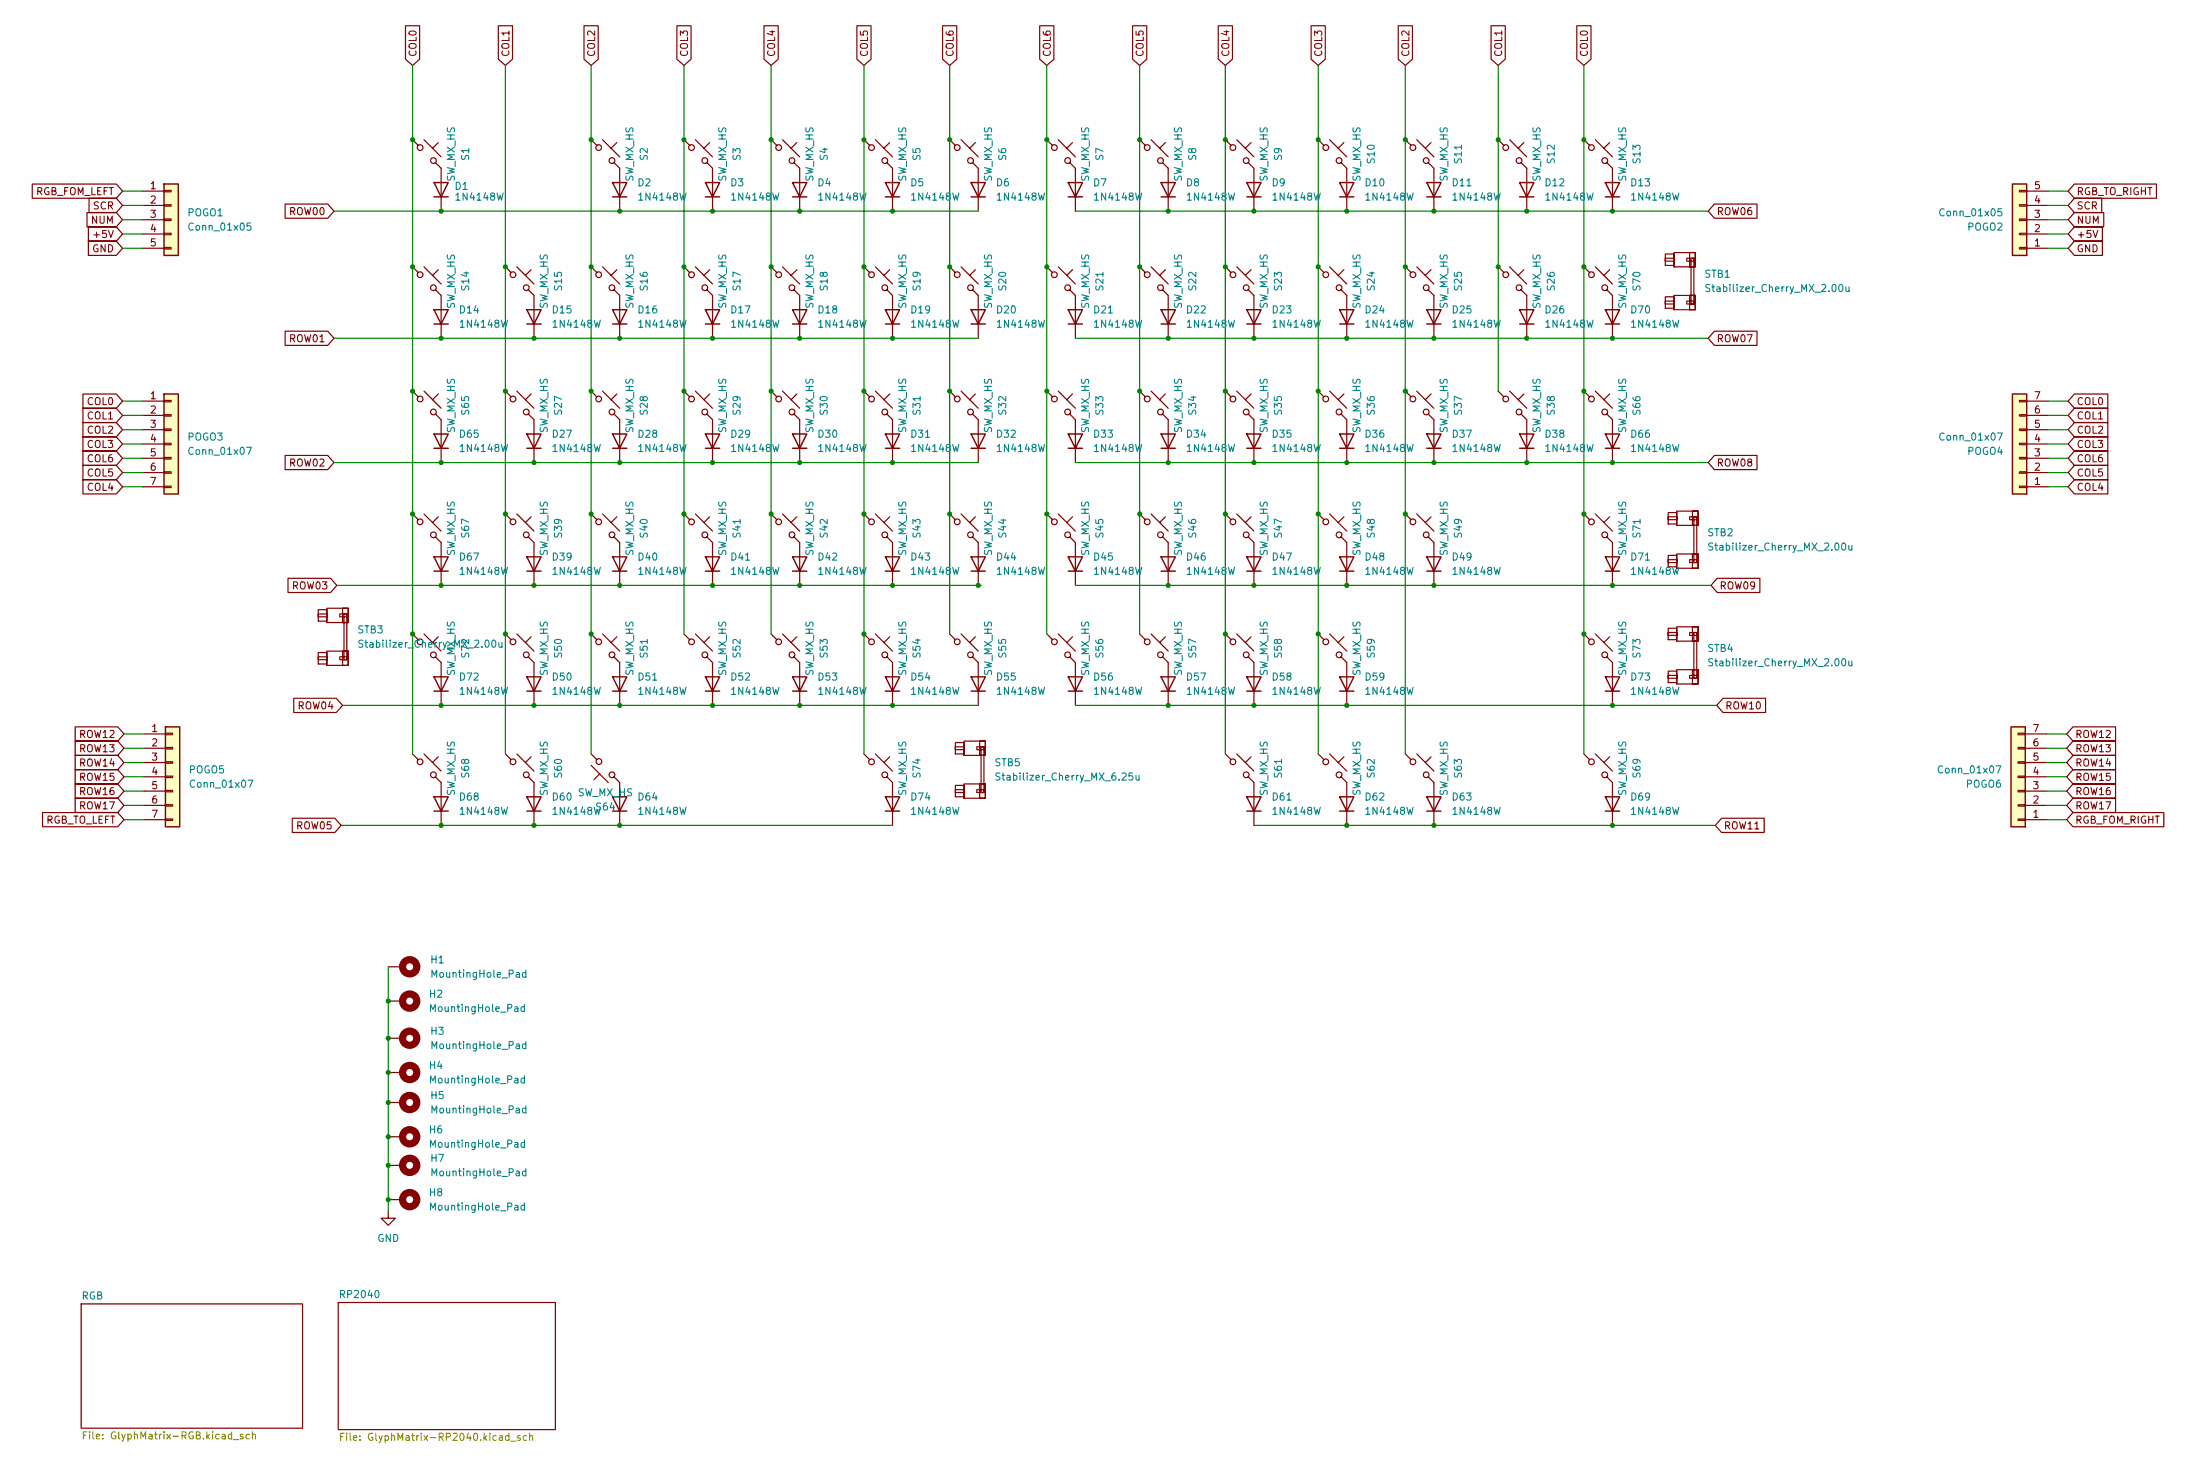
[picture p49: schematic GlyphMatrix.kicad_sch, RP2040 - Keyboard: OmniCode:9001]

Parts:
D1, D2, D3, D4, D5, D6, D7, D8, D9, D10, D11, D12, D13, D14, D15, D16, D17, D18, D19, D20, D21, D22, D23, D24, D25, D26, D27, D28, D29, D30, D31, D32, D33, D34, D35, D36, D37, D38, D39, D40, D41, D42, D43, D44, D45, D46, D47, D48, D49, D50, D51, D52, D53, D54, D55, D56, D57, D58, D59, D60, D61, D62, D63, D64, D65, D66, D67, D68, D69, D70, D71, D72, D73, D74: 1N4148W; D3_SMD; LCSC C7420318
H1, H2, H3, H4, H5, H6, H7, H8: MountingHole_Pad; MountingHole_3.2mm_Pad
POGO1, POGO2: Conn_01x05; Pogopin_1x05_P2.54mm_Curved
POGO3, POGO4, POGO5, POGO6: Conn_01x07; Pogopin_1x07_P2.54mm_Curved
S1, S2, S3, S4, S5, S6, S7, S8, S9, S10, S11, S12, S13, S14, S15, S16, S17, S18, S19, S20, S21, S22, S23, S24, S25, S26, S27, S28, S29, S30, S31, S32, S33, S34, S35, S36, S37, S38, S39, S40, S41, S42, S43, S44, S45, S46, S47, S48, S49, S50, S51, S52, S53, S54, S55, S56, S57, S58, S59, S60, S61, S62, S63: SW_MX_HS; SW_MX_HS_1u; LCSC C41430893
S64: SW_MX_HS; SW_MX_HS_1.25u; LCSC C41430893
S65, S66: SW_MX_HS; SW_MX_HS_1.5u; LCSC C41430893
S67, S68, S69: SW_MX_HS; SW_MX_HS_1.75u; LCSC C41430893
S70: SW_MX_HS; SW_MX_HS_2u; LCSC C41430893
S71, S72: SW_MX_HS; SW_MX_HS_2.25u; LCSC C41430893
S73: SW_MX_HS; SW_MX_HS_2.75u; LCSC C41430893
S74: SW_MX_HS; SW_MX_HS_6.25u; LCSC C41430893
STB1, STB2, STB3, STB4: Stabilizer_Cherry_MX_2.00u
STB5: Stabilizer_Cherry_MX_6.25u

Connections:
+5V: POGO1.4, POGO2.2; also elsewhere on the board
COL0: POGO3.1, POGO4.7, S1.2, S13.2, S14.2, S65.2, S66.2, S67.2, S68.2, S69.2, S70.2, S71.2, S72.2, S73.2; also elsewhere on the board
COL1: POGO3.2, POGO4.6, S12.2, S15.2, S26.2, S27.2, S38.2, S39.2, S50.2, S60.2; also elsewhere on the board
COL2: POGO3.3, POGO4.5, S2.2, S11.2, S16.2, S25.2, S28.2, S37.2, S40.2, S49.2, S51.2, S63.2, S64.2; also elsewhere on the board
COL3: POGO3.4, POGO4.4, S3.2, S10.2, S17.2, S24.2, S29.2, S36.2, S41.2, S48.2, S52.2, S59.2, S62.2; also elsewhere on the board
COL4: POGO3.7, POGO4.1, S4.2, S9.2, S18.2, S23.2, S30.2, S35.2, S42.2, S47.2, S53.2, S58.2, S61.2; also elsewhere on the board
COL5: POGO3.6, POGO4.2, S5.2, S8.2, S19.2, S22.2, S31.2, S34.2, S43.2, S46.2, S54.2, S57.2, S74.2; also elsewhere on the board
COL6: POGO3.5, POGO4.3, S6.2, S7.2, S20.2, S21.2, S32.2, S33.2, S44.2, S45.2, S55.2, S56.2; also elsewhere on the board
GND: H1.1, H2.1, H3.1, H4.1, H5.1, H6.1, H7.1, H8.1, POGO1.5, POGO2.1; also elsewhere on the board
NUM: POGO1.3, POGO2.3; also elsewhere on the board
unnamed: D1.2 (A), S1.1
unnamed: D2.2 (A), S2.1
unnamed: D3.2 (A), S3.1
unnamed: D4.2 (A), S4.1
unnamed: D5.2 (A), S5.1
unnamed: D6.2 (A), S6.1
unnamed: D7.2 (A), S7.1
unnamed: D8.2 (A), S8.1
unnamed: D9.2 (A), S9.1
unnamed: D10.2 (A), S10.1
unnamed: D11.2 (A), S11.1
unnamed: D12.2 (A), S12.1
unnamed: D13.2 (A), S13.1
unnamed: D14.2 (A), S14.1
unnamed: D15.2 (A), S15.1
unnamed: D16.2 (A), S16.1
unnamed: D17.2 (A), S17.1
unnamed: D18.2 (A), S18.1
unnamed: D19.2 (A), S19.1
unnamed: D20.2 (A), S20.1
unnamed: D21.2 (A), S21.1
unnamed: D22.2 (A), S22.1
unnamed: D23.2 (A), S23.1
unnamed: D24.2 (A), S24.1
unnamed: D25.2 (A), S25.1
unnamed: D26.2 (A), S26.1
unnamed: D27.2 (A), S27.1
unnamed: D28.2 (A), S28.1
unnamed: D29.2 (A), S29.1
unnamed: D30.2 (A), S30.1
unnamed: D31.2 (A), S31.1
unnamed: D32.2 (A), S32.1
unnamed: D33.2 (A), S33.1
unnamed: D34.2 (A), S34.1
unnamed: D35.2 (A), S35.1
unnamed: D36.2 (A), S36.1
unnamed: D37.2 (A), S37.1
unnamed: D38.2 (A), S38.1
unnamed: D39.2 (A), S39.1
unnamed: D40.2 (A), S40.1
unnamed: D41.2 (A), S41.1
unnamed: D42.2 (A), S42.1
unnamed: D43.2 (A), S43.1
unnamed: D44.2 (A), S44.1
unnamed: D45.2 (A), S45.1
unnamed: D46.2 (A), S46.1
unnamed: D47.2 (A), S47.1
unnamed: D48.2 (A), S48.1
unnamed: D49.2 (A), S49.1
unnamed: D50.2 (A), S50.1
unnamed: D51.2 (A), S51.1
unnamed: D52.2 (A), S52.1
unnamed: D53.2 (A), S53.1
unnamed: D54.2 (A), S54.1
unnamed: D55.2 (A), S55.1
unnamed: D56.2 (A), S56.1
unnamed: D57.2 (A), S57.1
unnamed: D58.2 (A), S58.1
unnamed: D59.2 (A), S59.1
unnamed: D60.2 (A), S60.1
unnamed: D61.2 (A), S61.1
unnamed: D62.2 (A), S62.1
unnamed: D63.2 (A), S63.1
unnamed: D64.2 (A), S64.1
unnamed: D65.2 (A), S65.1
unnamed: D66.2 (A), S66.1
unnamed: D67.2 (A), S67.1
unnamed: D68.2 (A), S68.1
unnamed: D69.2 (A), S69.1
unnamed: D70.2 (A), S70.1
unnamed: D71.2 (A), S71.1
unnamed: D72.2 (A), S72.1
unnamed: D73.2 (A), S73.1
unnamed: D74.2 (A), S74.1
RGB_FOM_LEFT: POGO1.1; also elsewhere on the board
RGB_FOM_RIGHT: POGO6.1; also elsewhere on the board
RGB_TO_LEFT: POGO5.7; also elsewhere on the board
RGB_TO_RIGHT: POGO2.5; also elsewhere on the board
ROW00: D1.1 (K), D2.1 (K), D3.1 (K), D4.1 (K), D5.1 (K), D6.1 (K); also elsewhere on the board
ROW01: D14.1 (K), D15.1 (K), D16.1 (K), D17.1 (K), D18.1 (K), D19.1 (K), D20.1 (K); also elsewhere on the board
ROW02: D27.1 (K), D28.1 (K), D29.1 (K), D30.1 (K), D31.1 (K), D32.1 (K), D65.1 (K); also elsewhere on the board
ROW03: D39.1 (K), D40.1 (K), D41.1 (K), D42.1 (K), D43.1 (K), D44.1 (K), D67.1 (K); also elsewhere on the board
ROW04: D50.1 (K), D51.1 (K), D52.1 (K), D53.1 (K), D54.1 (K), D55.1 (K), D72.1 (K); also elsewhere on the board
ROW05: D60.1 (K), D64.1 (K), D68.1 (K), D74.1 (K); also elsewhere on the board
ROW06: D7.1 (K), D8.1 (K), D9.1 (K), D10.1 (K), D11.1 (K), D12.1 (K), D13.1 (K); also elsewhere on the board
ROW07: D21.1 (K), D22.1 (K), D23.1 (K), D24.1 (K), D25.1 (K), D26.1 (K), D70.1 (K); also elsewhere on the board
ROW08: D33.1 (K), D34.1 (K), D35.1 (K), D36.1 (K), D37.1 (K), D38.1 (K), D66.1 (K); also elsewhere on the board
ROW09: D45.1 (K), D46.1 (K), D47.1 (K), D48.1 (K), D49.1 (K), D71.1 (K); also elsewhere on the board
ROW10: D56.1 (K), D57.1 (K), D58.1 (K), D59.1 (K), D73.1 (K); also elsewhere on the board
ROW11: D61.1 (K), D62.1 (K), D63.1 (K), D69.1 (K); also elsewhere on the board
ROW12: POGO5.1, POGO6.7; also elsewhere on the board
ROW13: POGO5.2, POGO6.6; also elsewhere on the board
ROW14: POGO5.3, POGO6.5; also elsewhere on the board
ROW15: POGO5.4, POGO6.4; also elsewhere on the board
ROW16: POGO5.5, POGO6.3; also elsewhere on the board
ROW17: POGO5.6, POGO6.2; also elsewhere on the board
SCR: POGO1.2, POGO2.4; also elsewhere on the board

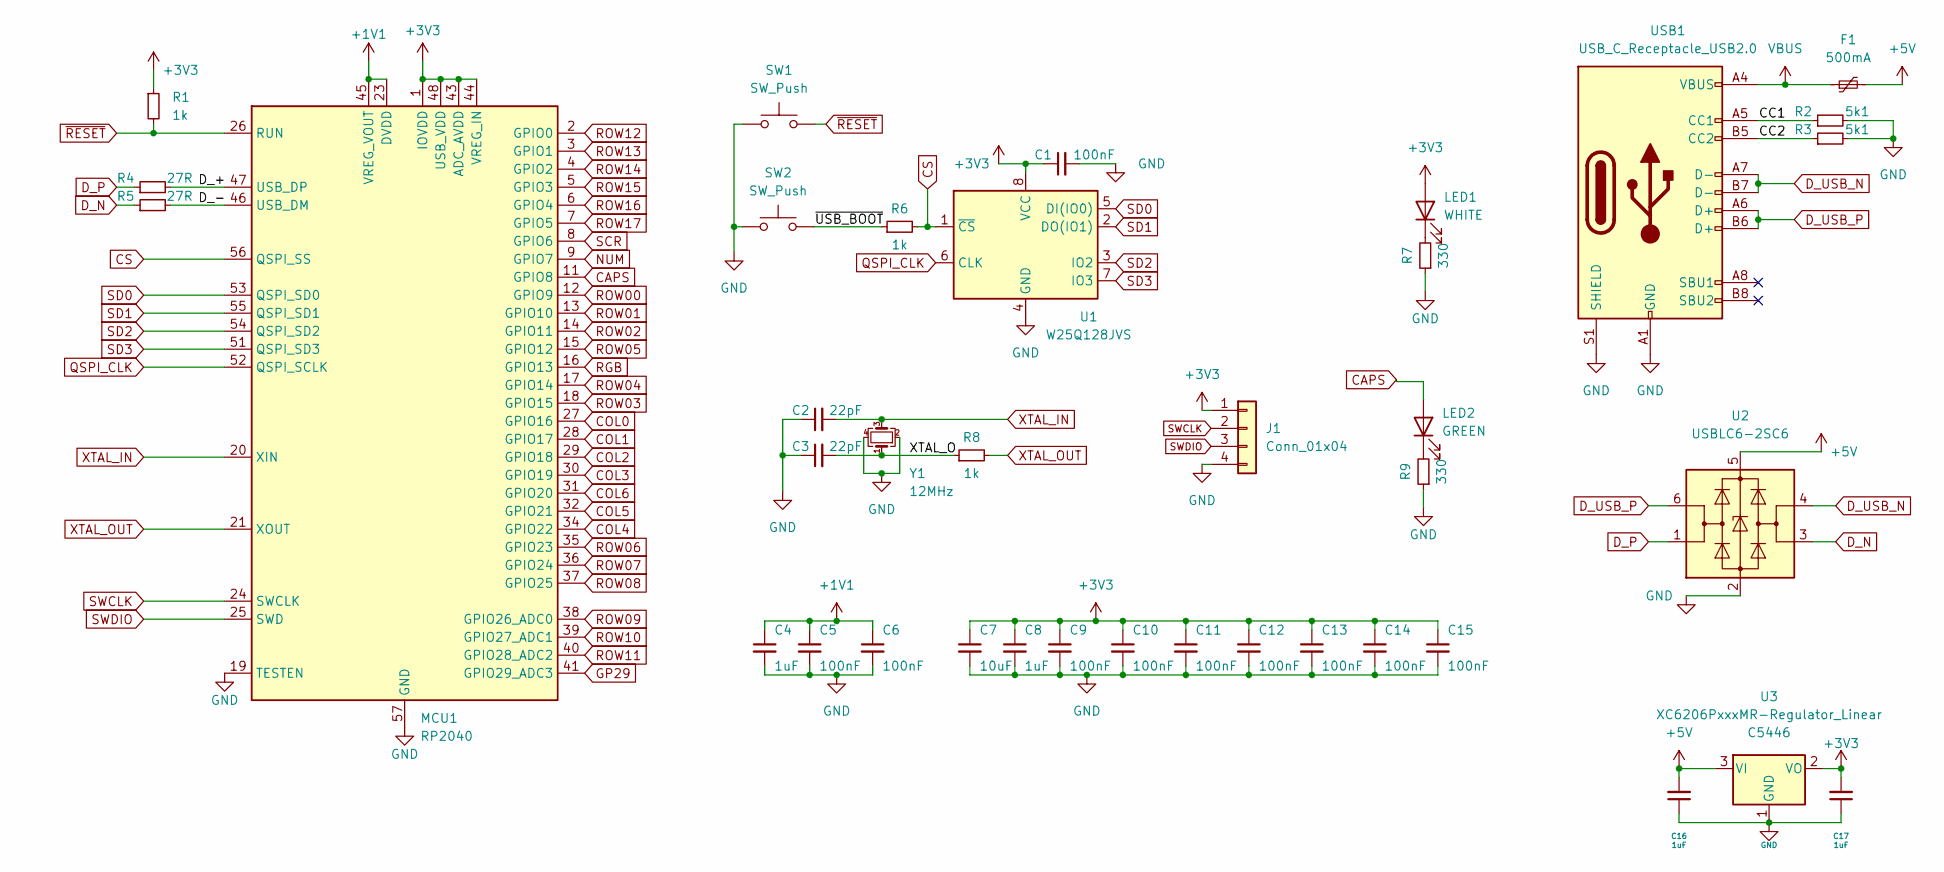
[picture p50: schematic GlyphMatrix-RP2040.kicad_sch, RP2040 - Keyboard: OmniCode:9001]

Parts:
C1, C5, C6, C9, C10, C11, C12, C13, C14, C15: 100nF; C_0402_1005Metric; LCSC C1525
C2, C3: 22pF; C_0402_1005Metric; LCSC C1555
C4, C8, C16, C17: 1uF; C_0402_1005Metric; LCSC C52923
C7: 10uF; C_0402_1005Metric; LCSC C15525
F1: 500mA; Fuse_1206_3216Metric; LCSC C70076
J1: Conn_01x04; PinHeader_2x02_P2.00mm_Vertical_SMD
LED1: WHITE; LED_0603_1608Metric_Pad1.05x0.95mm_HandSolder; LCSC C965808
LED2: GREEN; LED_0603_1608Metric_Pad1.05x0.95mm_HandSolder; LCSC C965805
MCU1: RP2040; RP2040-QFN-56; LCSC C2040
R1, R6, R8: 1k; R_0402_1005Metric; LCSC C11702
R2, R3: 5k1; R_0402_1005Metric; LCSC C25905
R4, R5: 27R; R_0603_1608Metric; LCSC C25190
R7, R9: 330; R_0603_1608Metric; LCSC C23138
SW1, SW2: SW_Push; SW_SPST_SKQG_WithoutStem; LCSC C202424
U1: W25Q128JVS; SOIC-8_5.3x5.3mm_P1.27mm; LCSC C131025
U2: USBLC6-2SC6; SOT-23-6; LCSC C2827654
U3: XC6206PxxxMR-Regulator_Linear; SOT-23; LCSC C5446
USB1: USB_C_Receptacle_USB2.0; GCT_USB4520-03-0-A_REVA; LCSC C2906290
Y1: 12MHz; Crystal_SMD_3225-4Pin_3.2x2.5mm; LCSC C9002

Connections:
+1V1: C4.1, C5.1, C6.1, MCU1.23 (DVDD), MCU1.45 (VREG_VOUT), MCU1.50 (DVDD)
+3V3: C1.1, C7.1, C8.1, C9.1, C10.1, C11.1, C12.1, C13.1, C14.1, C15.1, C17.2, J1.1, LED1.2 (A), MCU1.1 (IOVDD), MCU1.10 (IOVDD), MCU1.22 (IOVDD), MCU1.33 (IOVDD), MCU1.42 (IOVDD), MCU1.43 (ADC_AVDD), MCU1.44 (VREG_IN), MCU1.48 (USB_VDD), MCU1.49 (IOVDD), R1.1, U1.8 (VCC), U3.2 (VO)
+5V: C16.2, F1.2, U2.5 (VBUS), U3.3 (VI); also elsewhere on the board
/RP2040/CC1: R2.1, USB1.A5 (CC1)
/RP2040/CC2: R3.1, USB1.B5 (CC2)
/RP2040/D_+: MCU1.47 (USB_DP), R4.2
/RP2040/D_-: MCU1.46 (USB_DM), R5.2
/RP2040/XTAL_O: C3.2, R8.1, Y1.1
/RP2040/~USB_BOOT: R6.1, SW2.2
CAPS: LED2.2 (A), MCU1.11 (GPIO8)
COL0: MCU1.27 (GPIO16); also elsewhere on the board
COL1: MCU1.28 (GPIO17); also elsewhere on the board
COL2: MCU1.29 (GPIO18); also elsewhere on the board
COL3: MCU1.30 (GPIO19); also elsewhere on the board
COL4: MCU1.34 (GPIO22); also elsewhere on the board
COL5: MCU1.32 (GPIO21); also elsewhere on the board
COL6: MCU1.31 (GPIO20); also elsewhere on the board
CS: MCU1.56 (QSPI_SS), R6.2, U1.1 (~CS)
D_N: R5.1, U2.3 (I/O2)
D_P: R4.1, U2.1 (I/O1)
D_USB_N: U2.4 (I/O2), USB1.A7 (D-), USB1.B7 (D-)
D_USB_P: U2.6 (I/O1), USB1.A6 (D+), USB1.B6 (D+)
GND: C1.2, C2.1, C3.1, C4.2, C5.2, C6.2, C7.2, C8.2, C9.2, C10.2, C11.2, C12.2, C13.2, C14.2, C15.2, C16.1, C17.1, J1.4, MCU1.19 (TESTEN), MCU1.57 (GND), R2.2, R3.2, R7.1, R9.1, SW1.1, SW2.1, U1.4 (GND), U2.2 (GND), U3.1 (GND), USB1.A1 (GND), USB1.A12 (GND), USB1.B1 (GND), USB1.B12 (GND), USB1.S1 (SHIELD), Y1.2, Y1.4; also elsewhere on the board
GP29: MCU1.41 (GPIO29_ADC3)
NUM: MCU1.9 (GPIO7); also elsewhere on the board
unnamed: LED1.1 (K), R7.2
unnamed: LED2.1 (K), R9.2
QSPI_CLK: MCU1.52 (QSPI_SCLK), U1.6 (CLK)
RGB: MCU1.16 (GPIO13); also elsewhere on the board
ROW00: MCU1.12 (GPIO9); also elsewhere on the board
ROW01: MCU1.13 (GPIO10); also elsewhere on the board
ROW02: MCU1.14 (GPIO11); also elsewhere on the board
ROW03: MCU1.18 (GPIO15); also elsewhere on the board
ROW04: MCU1.17 (GPIO14); also elsewhere on the board
ROW05: MCU1.15 (GPIO12); also elsewhere on the board
ROW06: MCU1.35 (GPIO23); also elsewhere on the board
ROW07: MCU1.36 (GPIO24); also elsewhere on the board
ROW08: MCU1.37 (GPIO25); also elsewhere on the board
ROW09: MCU1.38 (GPIO26_ADC0); also elsewhere on the board
ROW10: MCU1.39 (GPIO27_ADC1); also elsewhere on the board
ROW11: MCU1.40 (GPIO28_ADC2); also elsewhere on the board
ROW12: MCU1.2 (GPIO0); also elsewhere on the board
ROW13: MCU1.3 (GPIO1); also elsewhere on the board
ROW14: MCU1.4 (GPIO2); also elsewhere on the board
ROW15: MCU1.5 (GPIO3); also elsewhere on the board
ROW16: MCU1.6 (GPIO4); also elsewhere on the board
ROW17: MCU1.7 (GPIO5); also elsewhere on the board
SCR: MCU1.8 (GPIO6); also elsewhere on the board
SD0: MCU1.53 (QSPI_SD0), U1.5 (DI(IO0))
SD1: MCU1.55 (QSPI_SD1), U1.2 (DO(IO1))
SD2: MCU1.54 (QSPI_SD2), U1.3 (IO2)
SD3: MCU1.51 (QSPI_SD3), U1.7 (IO3)
SWCLK: J1.2, MCU1.24 (SWCLK)
SWDIO: J1.3, MCU1.25 (SWD)
VBUS: F1.1, USB1.A4 (VBUS), USB1.A9 (VBUS), USB1.B4 (VBUS), USB1.B9 (VBUS)
XTAL_IN: C2.2, MCU1.20 (XIN), Y1.3
XTAL_OUT: MCU1.21 (XOUT), R8.2
~RESET: MCU1.26 (RUN), R1.2, SW1.2

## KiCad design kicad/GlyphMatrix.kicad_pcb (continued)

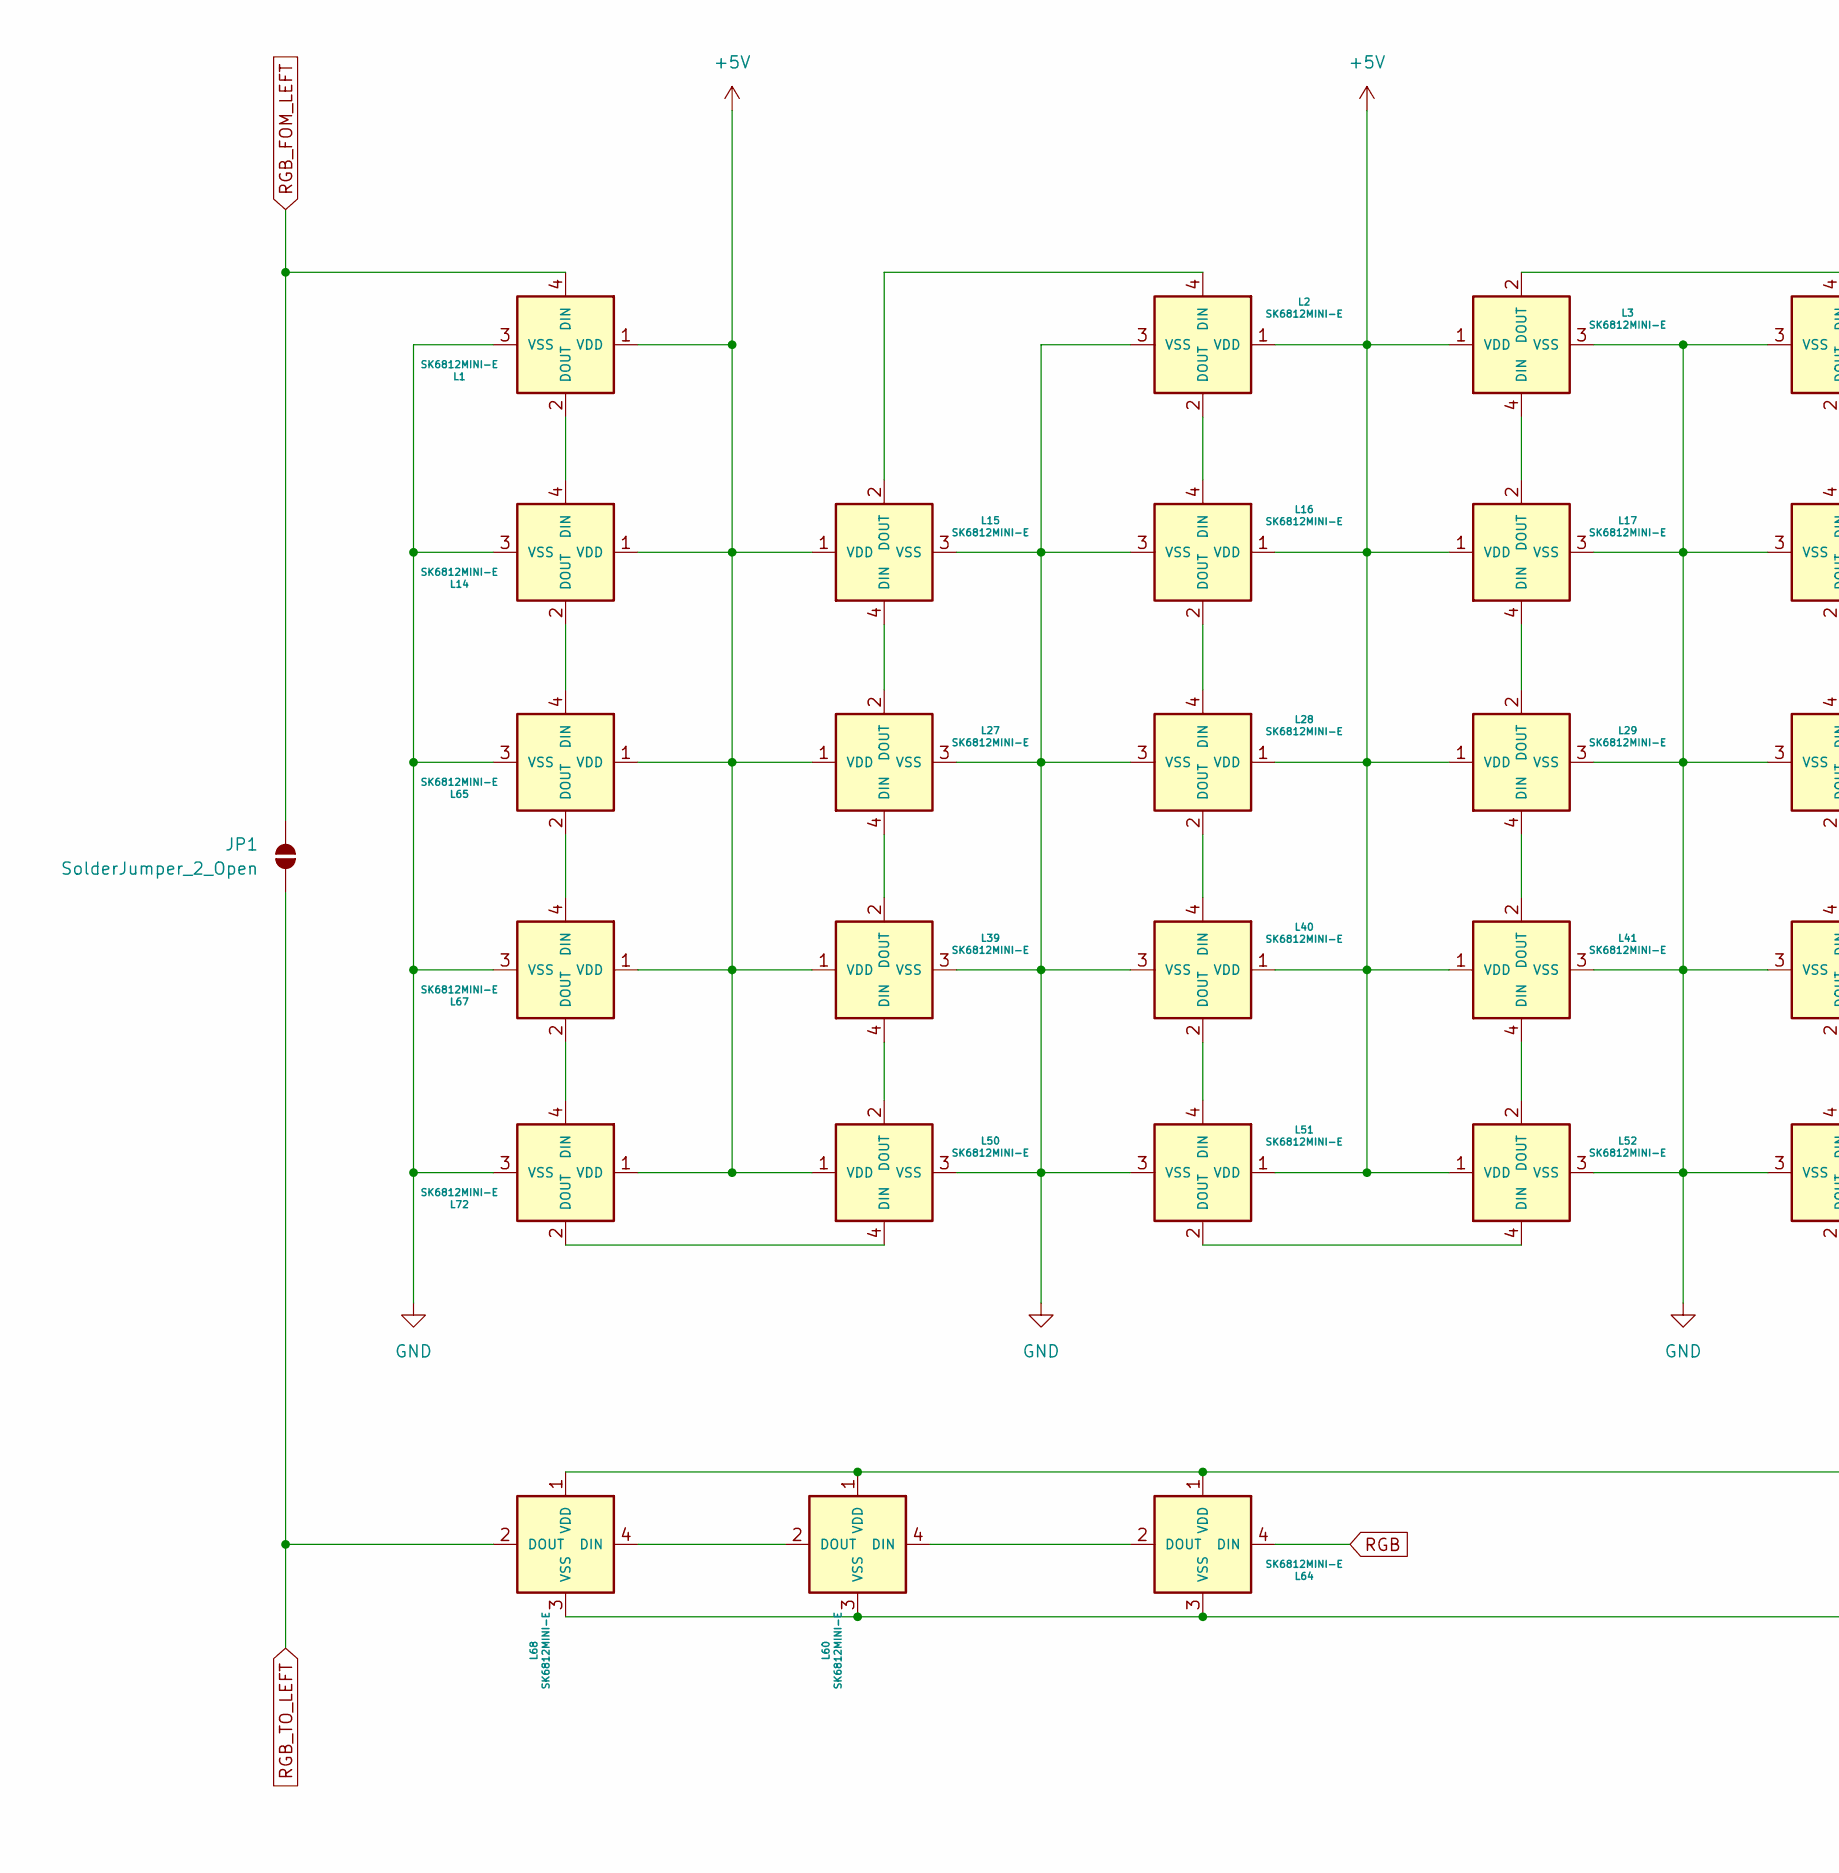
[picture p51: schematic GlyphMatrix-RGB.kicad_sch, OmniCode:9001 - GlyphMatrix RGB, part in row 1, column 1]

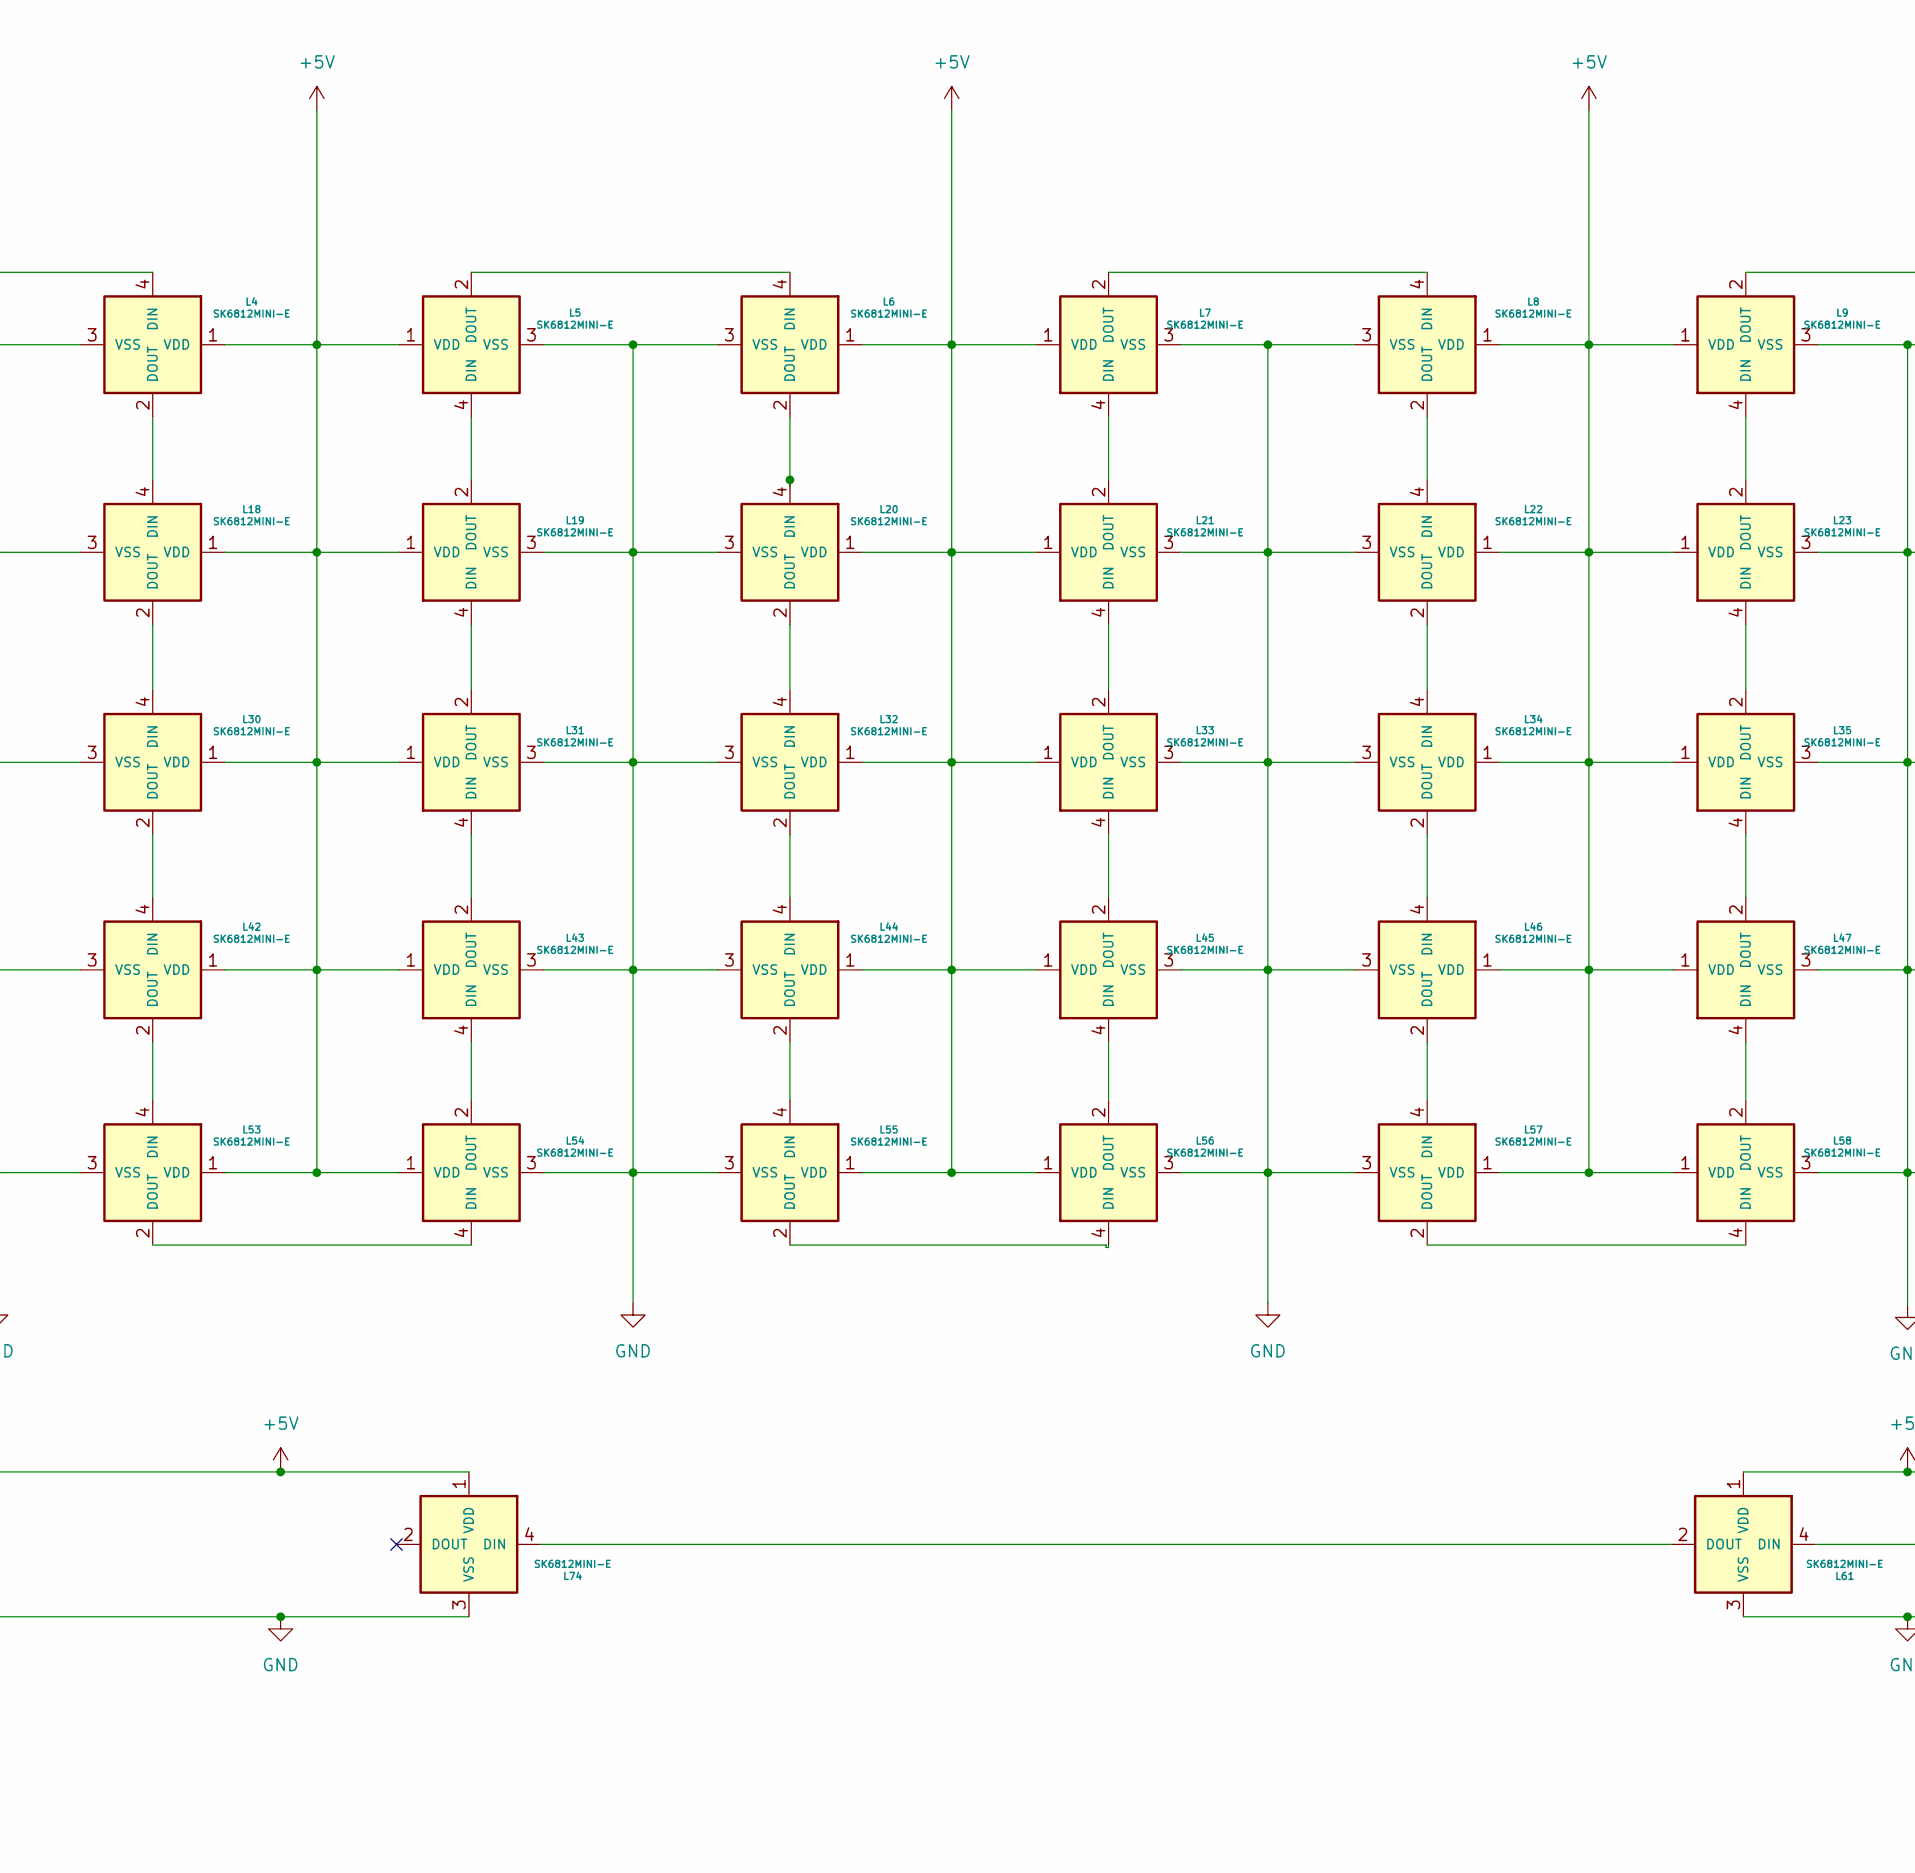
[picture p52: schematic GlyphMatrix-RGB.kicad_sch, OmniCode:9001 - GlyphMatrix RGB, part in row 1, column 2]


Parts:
JP1, JP2: SolderJumper_2_Open; SolderJumper-2_P1.3mm_Bridged_RoundedPad1.0x1.5mm
L1, L2, L3, L4, L5, L6, L7, L8, L9, L10, L11, L12, L13, L14, L15, L16, L17, L18, L19, L20, L21, L22, L23, L24, L25, L26, L27, L28, L29, L30, L31, L32, L33, L34, L35, L36, L37, L38, L39, L40, L41, L42, L43, L44, L45, L46, L47, L48, L49, L50, L51, L52, L53, L54, L55, L56, L57, L58, L59, L60, L61, L62, L63, L64, L65, L66, L67, L68, L69, L70, L71, L72, L73, L74: SK6812MINI-E; LED_SK6812MINI-E; LCSC C5149201

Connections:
+5V: L1.1 (VDD), L2.1 (VDD), L3.1 (VDD), L4.1 (VDD), L5.1 (VDD), L6.1 (VDD), L7.1 (VDD), L8.1 (VDD), L9.1 (VDD), L10.1 (VDD), L11.1 (VDD), L12.1 (VDD), L13.1 (VDD), L14.1 (VDD), L15.1 (VDD), L16.1 (VDD), L17.1 (VDD), L18.1 (VDD), L19.1 (VDD), L20.1 (VDD), L21.1 (VDD), L22.1 (VDD), L23.1 (VDD), L24.1 (VDD), L25.1 (VDD), L26.1 (VDD), L27.1 (VDD), L28.1 (VDD), L29.1 (VDD), L30.1 (VDD), L31.1 (VDD), L32.1 (VDD), L33.1 (VDD), L34.1 (VDD), L35.1 (VDD), L36.1 (VDD), L37.1 (VDD), L38.1 (VDD), L39.1 (VDD), L40.1 (VDD), L41.1 (VDD), L42.1 (VDD), L43.1 (VDD), L44.1 (VDD), L45.1 (VDD), L46.1 (VDD), L47.1 (VDD), L48.1 (VDD), L49.1 (VDD), L50.1 (VDD), L51.1 (VDD), L52.1 (VDD), L53.1 (VDD), L54.1 (VDD), L55.1 (VDD), L56.1 (VDD), L57.1 (VDD), L58.1 (VDD), L59.1 (VDD), L60.1 (VDD), L61.1 (VDD), L62.1 (VDD), L63.1 (VDD), L64.1 (VDD), L65.1 (VDD), L66.1 (VDD), L67.1 (VDD), L68.1 (VDD), L69.1 (VDD), L70.1 (VDD), L71.1 (VDD), L72.1 (VDD), L73.1 (VDD), L74.1 (VDD); also elsewhere on the board
GND: L1.3 (VSS), L2.3 (VSS), L3.3 (VSS), L4.3 (VSS), L5.3 (VSS), L6.3 (VSS), L7.3 (VSS), L8.3 (VSS), L9.3 (VSS), L10.3 (VSS), L11.3 (VSS), L12.3 (VSS), L13.3 (VSS), L14.3 (VSS), L15.3 (VSS), L16.3 (VSS), L17.3 (VSS), L18.3 (VSS), L19.3 (VSS), L20.3 (VSS), L21.3 (VSS), L22.3 (VSS), L23.3 (VSS), L24.3 (VSS), L25.3 (VSS), L26.3 (VSS), L27.3 (VSS), L28.3 (VSS), L29.3 (VSS), L30.3 (VSS), L31.3 (VSS), L32.3 (VSS), L33.3 (VSS), L34.3 (VSS), L35.3 (VSS), L36.3 (VSS), L37.3 (VSS), L38.3 (VSS), L39.3 (VSS), L40.3 (VSS), L41.3 (VSS), L42.3 (VSS), L43.3 (VSS), L44.3 (VSS), L45.3 (VSS), L46.3 (VSS), L47.3 (VSS), L48.3 (VSS), L49.3 (VSS), L50.3 (VSS), L51.3 (VSS), L52.3 (VSS), L53.3 (VSS), L54.3 (VSS), L55.3 (VSS), L56.3 (VSS), L57.3 (VSS), L58.3 (VSS), L59.3 (VSS), L60.3 (VSS), L61.3 (VSS), L62.3 (VSS), L63.3 (VSS), L64.3 (VSS), L65.3 (VSS), L66.3 (VSS), L67.3 (VSS), L68.3 (VSS), L69.3 (VSS), L70.3 (VSS), L71.3 (VSS), L72.3 (VSS), L73.3 (VSS), L74.3 (VSS); also elsewhere on the board
unnamed: L1.2 (DOUT), L14.4 (DIN)
unnamed: L3.2 (DOUT), L4.4 (DIN)
unnamed: L5.2 (DOUT), L6.4 (DIN)
unnamed: L7.2 (DOUT), L8.4 (DIN)
unnamed: L9.2 (DOUT), L10.4 (DIN)
unnamed: L10.2 (DOUT), L24.4 (DIN)
unnamed: L11.4 (DIN), L25.2 (DOUT)
unnamed: L11.2 (DOUT), L12.4 (DIN)
unnamed: L12.2 (DOUT), L26.4 (DIN)
unnamed: L13.4 (DIN), L70.2 (DOUT)
unnamed: L14.2 (DOUT), L65.4 (DIN)
unnamed: L15.4 (DIN), L27.2 (DOUT)
unnamed: L2.4 (DIN), L15.2 (DOUT)
unnamed: L2.2 (DOUT), L16.4 (DIN)
unnamed: L16.2 (DOUT), L28.4 (DIN)
unnamed: L17.4 (DIN), L29.2 (DOUT)
unnamed: L3.4 (DIN), L17.2 (DOUT)
unnamed: L4.2 (DOUT), L18.4 (DIN)
unnamed: L18.2 (DOUT), L30.4 (DIN)
unnamed: L19.4 (DIN), L31.2 (DOUT)
unnamed: L5.4 (DIN), L19.2 (DOUT)
unnamed: L6.2 (DOUT), L20.4 (DIN)
unnamed: L20.2 (DOUT), L32.4 (DIN)
unnamed: L21.4 (DIN), L33.2 (DOUT)
unnamed: L7.4 (DIN), L21.2 (DOUT)
unnamed: L8.2 (DOUT), L22.4 (DIN)
unnamed: L22.2 (DOUT), L34.4 (DIN)
unnamed: L23.4 (DIN), L35.2 (DOUT)
unnamed: L9.4 (DIN), L23.2 (DOUT)
unnamed: L24.2 (DOUT), L36.4 (DIN)
unnamed: L25.4 (DIN), L37.2 (DOUT)
unnamed: L26.2 (DOUT), L38.4 (DIN)
unnamed: L27.4 (DIN), L39.2 (DOUT)
unnamed: L28.2 (DOUT), L40.4 (DIN)
unnamed: L29.4 (DIN), L41.2 (DOUT)
unnamed: L30.2 (DOUT), L42.4 (DIN)
unnamed: L31.4 (DIN), L43.2 (DOUT)
unnamed: L32.2 (DOUT), L44.4 (DIN)
unnamed: L33.4 (DIN), L45.2 (DOUT)
unnamed: L34.2 (DOUT), L46.4 (DIN)
unnamed: L35.4 (DIN), L47.2 (DOUT)
unnamed: L36.2 (DOUT), L48.4 (DIN)
unnamed: L37.4 (DIN), L49.2 (DOUT)
unnamed: L38.2 (DOUT), L73.4 (DIN)
unnamed: L39.4 (DIN), L50.2 (DOUT)
unnamed: L40.2 (DOUT), L51.4 (DIN)
unnamed: L41.4 (DIN), L52.2 (DOUT)
unnamed: L42.2 (DOUT), L53.4 (DIN)
unnamed: L43.4 (DIN), L54.2 (DOUT)
unnamed: L44.2 (DOUT), L55.4 (DIN)
unnamed: L45.4 (DIN), L56.2 (DOUT)
unnamed: L46.2 (DOUT), L57.4 (DIN)
unnamed: L47.4 (DIN), L58.2 (DOUT)
unnamed: L48.2 (DOUT), L59.4 (DIN)
unnamed: L49.4 (DIN), L59.2 (DOUT)
unnamed: L50.4 (DIN), L72.2 (DOUT)
unnamed: L51.2 (DOUT), L52.4 (DIN)
unnamed: L53.2 (DOUT), L54.4 (DIN)
unnamed: L55.2 (DOUT), L56.4 (DIN)
unnamed: L57.2 (DOUT), L58.4 (DIN)
unnamed: L60.4 (DIN), L64.2 (DOUT)
unnamed: L60.2 (DOUT), L68.4 (DIN)
unnamed: L61.4 (DIN), L62.2 (DOUT)
unnamed: L61.2 (DOUT), L74.4 (DIN)
unnamed: L62.4 (DIN), L63.2 (DOUT)
unnamed: L63.4 (DIN), L69.2 (DOUT)
unnamed: L65.2 (DOUT), L67.4 (DIN)
unnamed: L66.4 (DIN), L71.2 (DOUT)
unnamed: L66.2 (DOUT), L70.4 (DIN)
unnamed: L67.2 (DOUT), L72.4 (DIN)
unnamed: L71.4 (DIN), L73.2 (DOUT)
RGB: L64.4 (DIN); also elsewhere on the board
RGB_FOM_LEFT: JP1.2 (B), L1.4 (DIN); also elsewhere on the board
RGB_FOM_RIGHT: JP2.2 (B), L69.4 (DIN); also elsewhere on the board
RGB_TO_LEFT: JP1.1 (A), L68.2 (DOUT); also elsewhere on the board
RGB_TO_RIGHT: JP2.1 (A), L13.2 (DOUT); also elsewhere on the board



Board: 2 copper layers, 294.9 x 128.6 mm, 281 parts (265 on the bottom side), 206 nets.

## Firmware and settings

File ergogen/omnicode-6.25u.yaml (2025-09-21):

meta:
  author: Allen Choi
  version: 0.6.5
  engine: 4.1.0
  project: "OmniCode:9001"

text_common:
  base_text_android: &base_text_android
    what: utility_text
    params: {side: 'F', reversible: false, face: 'Android Robot'}

  text_base: &text_base
    what: utility_text
    params:
      face: 'KiCad Font'
      knockout: true

  version_text: &version_text
    <<: *text_base
    params.text: "OminCode:9001 202508.04"

  text_bbg: &text_bbg
    what: utility_text
    params:
      face: 'Avenir Next P for BBG'
      bold: true
      align: 'left'
      width: 6
      height: 6
      side: F

  text_khs: &text_khs
    what: utility_text
    params:
      face: 'Kahless Shadow'
      bold: true
      mirrored: true
      width: 8
      height: 8
      side: B

units:
  # Key sizes
  u1_00: U  # Base unit (1U)
  u0_25: u1_00 * 0.25
  u0_50: u1_00 * 0.5
  u1_25: u1_00 * 1.25  # 1.25U - Used for modifiers
  u1_50: u1_00 * 1.5    # 1.5U - Used for Tab and backslash
  u1_75: u1_00 * 1.75  # 1.75U - Used for Caps Lock
  u2_00: u1_00 * 2        # 2U - Used for Backspace and Left Shift
  u2_25: u1_00 * 2.25  # 2.25U - Used for Enter and left space
  u2_75: u1_00 * 2.75  # 2.75U - Used for right space
  u6_00: u1_00 * 6
  u6_25: u1_00 * 6.25

  stabilizer_width: 7
  stabilizer_height: 14
  stabilizer_offset: -1 # This means south stabs, use `orient` to rotate them for north facing scenarios
  stabilizer_spacing_u2_00: 11.938 # Spacing for 2U stabilizers
  stabilizer_spacing_u6_25: (u6_25 - u1_00) / 2

  # Screw hole sizes
  screw_hole_radius: 1.6    # M6 screw hole size
  support_hole_radius: 1.6  # M2 PCB support hole size

  # Spacing and padding
  ps: 0.0          # Base padding between switches
  dx: ps
  dy: ps + 0
  bx: 4.6
  by: .25u1_00
  mb: 5.5          # mouse bite
  px: u1_00 + dx      # Horizontal spacing
  py: u1_00 + dy      # Vertical spacing

  # Pogopin placement
  pogo_w: 2.5 # 0.5 Width of the pogo pin area
  pogo_x: bx - 3.8
  pogo_y1: 15.3
  pogo_y3: 17.8
  cover_width: 1.7
  case_width: 5.5
  
  # hole offset from the edges
  hole_offset: 4.5

  # Layout specific measurements
  corner: 2         # Corner radius
  corner1: 1
  distance: 2 bx + mb

points:
  zones:
    function:
      anchor:
        shift: [75, -90]
      key:
        padding: px
        spread: px
        tags: [gmu1_00]
      rows:
        row:    { row_net: "function"}
      columns:
        c00:      { key: { width: u1_00, column_net: "col_0"}}

        c02:      { key: { width: u1_00, column_net: "col_2", shift: [u1_00]}}
        c03:      { key: { width: u1_00, column_net: "col_3", shift: [u1_00]}}
        c04:      { key: { width: u1_00, column_net: "col_4", shift: [u1_00]}}
        c05:      { key: { width: u1_00, column_net: "col_5", shift: [u1_00]}}

        c06:      { key: { width: u1_00, column_net: "col_6", shift: [u1_50]}}
        c07:      { key: { width: u1_00, column_net: "col_6", shift: [u1_50]}}
        c08:      { key: { width: u1_00, column_net: "col_5", shift: [u1_50]}}
        c09:      { key: { width: u1_00, column_net: "col_4", shift: [u1_50]}}

        c10:      { key: { width: u1_00, column_net: "col_3", shift: [u2_00]}}
        c11:      { key: { width: u1_00, column_net: "col_2", shift: [u2_00]}}
        c12:      { key: { width: u1_00, column_net: "col_1", shift: [u2_00]}}
        c13:      { key: { width: u1_00, column_net: "col_0", shift: [u2_00]}}

    number:
      anchor:
        ref: function_c00_row
        shift: [0, -u1_25]
      key:
        padding: px
        spread: px
        tags: [gmu1_00]
      rows:
        row:    { row_net: "number"}
      columns:
        c00: { key: { width: u1_00, column_net: "col_0" }}
        c01: { key: { width: u1_00, column_net: "col_1" }}
        c02: { key: { width: u1_00, column_net: "col_2" }}
        c03: { key: { width: u1_00, column_net: "col_3" }}
        c04: { key: { width: u1_00, column_net: "col_4" }}
        c05: { key: { width: u1_00, column_net: "col_5" }}
        c06: { key: { width: u1_00, column_net: "col_6" }}
        c07: { key: { width: u1_00, column_net: "col_6" }}
        c08: { key: { width: u1_00, column_net: "col_5" }}
        c09: { key: { width: u1_00, column_net: "col_4" }}
        c10: { key: { width: u1_00, column_net: "col_3" }}
        c11: { key: { width: u1_00, column_net: "col_2" }}
        c12: { key: { width: u1_00, column_net: "col_1" }}
        c13: { key: { width: u2_00, column_net: "col_0", shift: [(u2_00-u1_00)/2], tags: [gmu2_00]}}
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

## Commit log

2025-07-09 initial commit (#1)
    * added submodule
    * added ergogen yaml
    * split up boards
    * added kicad
    * added MCU
    * updated MCU
    * USB
    * pogo pin connectors
    * screw holes
    * pogo pin - ergogen
    * artwork
    * artwork #2
    * artwork #3
    * artwork for GlyphMatrix
    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
    [DeltaForm-RGB.kicad_sch, DeltaForm-keymatrix.kicad_sch, DeltaForm.kicad_pcb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]
2025-07-10 BOM (#2)
    * updated README.md
    * added BOM
    * reorg BOM files
2025-07-11 more tweaks (#3)
    * small tweaks
    * GlyphMatrix - 3mm screws
    * PhaseShift - 3mm screws
    * DeltaForm - 3mm screws
    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
    [DeltaForm.kicad_pcb, DeltaForm_Plate.kicad_pcb, DeltaForm_Plate.step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]
2025-07-13 plates (#4)
    * Silk Screen
    * small changes for GlyphMatrix
    * Silk screen for plates
    * amended GlyphMatrix
    [DeltaForm_Plate.kicad_pcb, DeltaForm_Top.kicad_pcb, DeltaForm_Top.step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]
2025-07-16 update build guide for GlyphMatrix (#8)
    * updated build guide - GlyphMatrix
    * pogo pin
    * updated images
    * updated build guide - GlyphMatrix
    * bottom plate
2025-07-17 2U stabilizers for ergogen (#10)
    * fixed layout json
    * updated ergogen - stabilizers
    * updated BOM
    [omnicode-6.25u.yaml]
2025-07-19 kibot (#11)
    [GlyphMatrix-keymatrix.kicad_sch, GlyphMatrix.kicad_sch]
2025-07-21 more updates (#12)
    * working on kibot
    * added position file
    * fixed footprint for PhaseShift and DeltaForm
    * fixed footprint side for GlyphMatrix
    * KiBot: changed BOM type
    * added fonts
    * KiBot
    * refreshed submodule
    * updated footprint for GlyphMatrix
    * updated footprint for PhaseShift
    * updated footprint for DeltaForm
    * updated build guide
    [DeltaForm.kicad_pcb, GlyphMatrix-keymatrix.kicad_sch, GlyphMatrix.kicad_pcb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]
2025-07-22 updated fonts (#13)
    * Changed fonts for silk screen
    * updated fonts for PhaseShift
    * updated fonts for DeltaForm
    * updated kibot for GlyphMatrix
    * added dummy schematic files for GlyphMatrix
    * updated kibot config
    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
    [DeltaForm.kicad_pcb, DeltaForm_Plate.kicad_sch, DeltaForm_Top.kicad_sch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]
2025-07-23 fixed BOM (#17)
    * fixed BOM
    * adedd colemak-dh
    * correct gui/opt positions
2025-07-28 reorg schematic (#18)
    * GlyphMatrix
    * PhaseShift
    * DeltaForm
    [DeltaForm-keymatrix.kicad_sch, DeltaForm.kicad_sch, GlyphMatrix-RP2040.kicad_sch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]
2025-08-03 updated schematic for GlyphMatrix (#20)
    [GlyphMatrix-RP2040.kicad_sch, GlyphMatrix.kicad_sch]
2025-08-04 adjust pogo pin positions (#21)
    * adjusted positions
    * small tweak
    * updated ergogen
    * 202508.04
    [DeltaForm.kicad_pcb, GlyphMatrix.kicad_pcb, GlyphMatrix_Plate.kicad_pcb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]
2025-08-09 tweaked zone (#22)
    * removed isolated copper islands
    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
    [DeltaForm.kicad_pcb, GlyphMatrix.kicad_pcb, PhaseShift.kicad_pcb]
2025-08-09 202508.10 (#23)
    [GlyphMatrix.kicad_pcb]
2025-08-17 side bars (#25)
    [GlyphMatrix.kicad_pcb, PhaseShift.kicad_pcb, PhaseShift.kicad_sch]
2025-08-28 fixed LED for GlyphMatrix (#26)
    [GlyphMatrix-RGB.kicad_sch, GlyphMatrix.kicad_pcb, GlyphMatrix_Plate.kicad_pcb]
2025-08-29 fixed mounting hole for GlyphMatrix (#27)
    [GlyphMatrix.kicad_pcb, GlyphMatrix.kicad_sch]
2025-09-16 quick fix (#30)
    [DeltaForm.kicad_pcb, DeltaForm.kicad_sch, PhaseShift.kicad_pcb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]
2025-09-21 cases (#31)
    * updated 3D models
    * cases
    * updated top level README.md
    [DeltaForm-Bottom.step, DeltaForm-Top.step, DeltaForm.step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]
2025-09-21 added the case image
